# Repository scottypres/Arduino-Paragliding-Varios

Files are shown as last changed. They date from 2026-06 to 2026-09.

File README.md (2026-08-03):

# Arduino Paragliding Varios

GitHub: [`scottypres/Arduino-Paragliding-Varios`](https://github.com/scottypres/Arduino-Paragliding-Varios)
Local checkout: `~/Documents/GitHub/Vario_Adafruit_Featherwing` — the folder name predates the
rename and is *not* worth changing; git doesn't care what the working directory is called.

Two separate paragliding variometers live here. They share nothing but ideas — different
boards, different sketches, different PCBs. Each one keeps its firmware, KiCad projects and
notes inside its own top-level folder.

| | **SparkFun ESP32 WROOM Vario** | **Adafruit Feather Mini Vario** |
|---|---|---|
| Status | **Active.** All current work. | Older / on ice. |
| Board | SparkFun Thing Plus ESP32 WROOM-C | Adafruit ESP32 Feather V2 |
| Firmware | `Sparkfun ESP32 WROOM Vario/Arduino Scripts/Sparkfun_Vario/` (multi-file) | `Adafruit Feather Mini Vario/Arduino Scripts/oled_ssid_button_buzzer/` (single `.ino`) |
| FQBN | `esp32:esp32:esp32thing_plus_c` | `esp32:esp32:adafruit_feather_esp32_v2` |
| Battery sense | MAX17048 fuel gauge on I2C (21/22) | ADC on `BATT_MONITOR` |
| Last touched | ongoing | 2026-07-03 (`bdf2adf`) |

Sensors on both: BMP581 (pressure/altitude), SHT41 (temp/humidity), SH1106G OLED, piezo buzzers.
The SparkFun build adds GPS, an LSM6DSV16X IMU, SD logging and a web app.

---

## Where things are

```
Adafruit Feather Mini Vario/
  Arduino Scripts/oled_ssid_button_buzzer/   single-file firmware
  KiCAD Files/                               Buzzer PCB, Buzzer PCB with step up converter
  CAD Files/                                 3D models for the stack
  docs/

Sparkfun ESP32 WROOM Vario/
  Arduino Scripts/
    Sparkfun_Vario/          <-- THE firmware. Everything else is a side experiment.
    Sparkfun_Battery_Tester/ standalone battery-drain rig
    experiments/             a2dp beep latency, piezo tests, wifi manager/OTA spike
    iram_tests/              IRAM budget probes (why WiFi and BT can't ship together)
  KiCAD Files/               Buzzer PCB V2, Buzzer PCB V3 (rerouting traces)
  3D Printed Case/
  docs/                      SparkFun datasheets, SD-log backups, design specs
```

`Component References/` is duplicated under each variant's `KiCAD Files/` on purpose: KiCad
resolves 3D models via `${KIPRJMOD}/../Component References/...`, so each project needs its own
copy to open cleanly from its own folder.

**Not in git, safe to delete:** anything under a `.history/` folder (VS Code Local History),
`build/`, `build-wifi/`, `build-bt/`, `.pio/`. If you see a top-level `Arduino Scripts/` or
`KiCAD Files/` in your working copy, those are leftovers from before the per-board
restructure — they contain no source, only build and history junk.

---

## The two firmware builds (SparkFun)

Since v1.2.0 the WiFi build also carries **BLE vario telemetry** (NimBLE — small enough
to coexist with WiFi in IRAM; the old split existed because Bluedroid *Classic* wasn't).
The BT-only build remains as a no-WiFi variant. Selected in `radio_config.h`:

| Build | Radios | Gets you | Loses |
|---|---|---|---|
| **WiFi** (default) | WiFi + BLE | web app, OTA, WiFi portal, LK8EX1 telemetry to phone apps | — |
| **BT** | BLE only | LK8EX1 telemetry, lower power | web app, OTA |

IRAM is within ~2 KB of full on the combined build — `rgbLedWrite` is stubbed in
`power.cpp` to keep the RMT driver out; don't add libraries without watching the link.

```sh
cd "Sparkfun ESP32 WROOM Vario/Arduino Scripts/Sparkfun_Vario"

# WiFi image (default)
arduino-cli compile --fqbn esp32:esp32:esp32thing_plus_c --output-dir build-wifi .

# BT image
arduino-cli compile --fqbn esp32:esp32:esp32thing_plus_c --output-dir build-bt \
  --build-property compiler.cpp.extra_flags=-DVARIO_RADIO_BT .
```

Required libraries: `SparkFun MAX1704x Fuel Gauge Arduino Library`, `SparkFun 6DoF LSM6DSV16X`,
plus the usual Adafruit GFX/SH110X/SHT4x/BMP5xx, TinyGPSPlus, ESPAsyncWebServer, WiFiManager.

### Getting a build onto the device

1. **OTA** (WiFi image running): System tab → *Firmware update*, or
   `espota.py -i <ip> -p 3232 -a password -f build-wifi/Sparkfun_Vario.ino.bin`
   (hostname `sparkfun-vario`).
2. **SD self-flash** — the only way to reach the BT image. Copy both binaries to the SD card
   root as `/fw_wifi.bin` and `/fw_bt.bin`, then Menu → System → **Switch FW** flashes *the
   other* variant and reboots.
3. **USB** — `arduino-cli upload -p /dev/cu.usbserial-* --fqbn esp32:esp32:esp32thing_plus_c`.

---

## Firmware versions

`Sparkfun_Vario/version.h` holds a single `VARIO_FW_VERSION`. It is shown in three places:

- OLED: **Menu → System → About**
- Web app: the header (`SparkFun Vario v1.0.0-WiFi`) and System tab → *About*
- API: `GET /api/settings` → `fw_version`, `fw_radio`, `fw_build`

The radio suffix (`-WiFi` / `-BT`) is derived at compile time, so the version string always
says which of the two images is running. `fw_build` is `__DATE__ __TIME__`, which answers
"is the board running the build I just made?" without any build-time codegen.

**Bump `VARIO_FW_VERSION` and add a `CHANGELOG.md` line in the same commit that changes
behaviour.** Semver-ish: patch for fixes, minor for new menu items/features, major for
anything that breaks saved settings or the log format.

To check what a device is running:

```sh
curl -s http://172.20.10.2/api/settings | python3 -m json.tool | grep fw_
```

---

## Working on this repo

Development also happens in Claude Code **cloud** sessions that push straight to
`origin/main` (branch names like `worktree-bridge-cse_*`). **Always `git fetch` before you
start** — a local checkout has silently been 21 commits stale before, and flashing a stale
build erases features that only exist on the device.

Device is usually at `http://172.20.10.2/` on the iPhone-hotspot subnet (`172.20.10.x`).
It sleeps aggressively, so a failed curl means "asleep", not "broken".

`arduino_secrets.h` is gitignored; copy `arduino_secrets.example.h` if you need hardcoded
WiFi credentials. Normally the WiFi portal handles it instead.

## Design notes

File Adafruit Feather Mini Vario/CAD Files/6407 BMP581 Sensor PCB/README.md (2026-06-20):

## Adafruit BMP5xx I2C or SPI Temperature and Pressure Sensors - STEMMA QT PCB

<a href="http://www.adafruit.com/products/6413"><br/>
Click here to purchase one from the Adafruit shop</a>
<a href="http://www.adafruit.com/products/6413"><br/>
Click here to purchase one from the Adafruit shop</a>
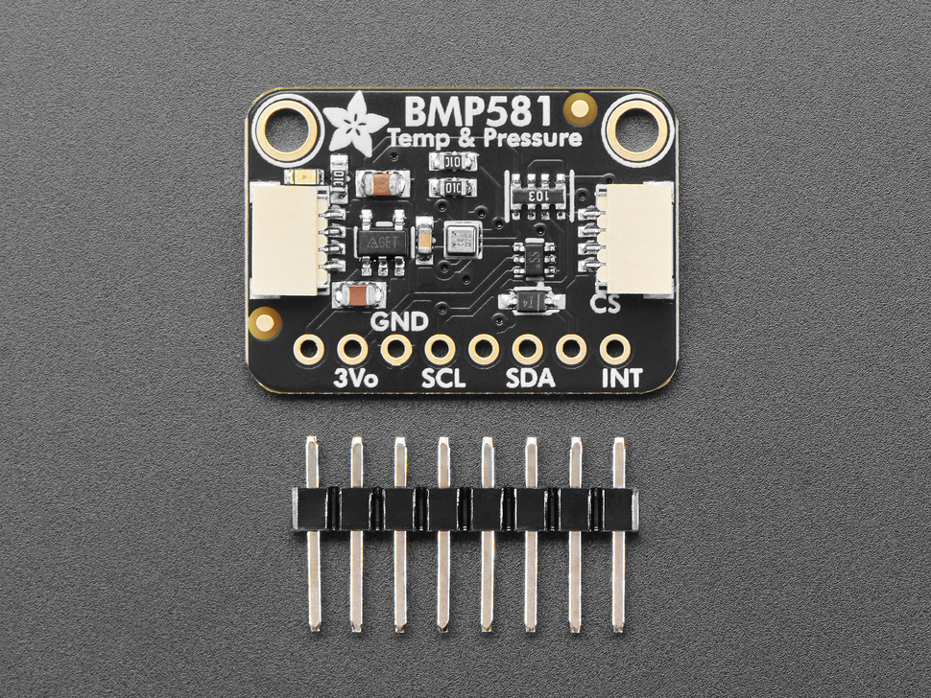
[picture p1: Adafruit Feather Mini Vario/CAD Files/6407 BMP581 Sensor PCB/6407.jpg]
<a href="http://www.adafruit.com/products/6413"><br/>
Click here to purchase one from the Adafruit shop</a>

PCB files for the Adafruit BMP5xx I2C or SPI Temperature and Pressure Sensors - STEMMA QT. 

Format is EagleCAD schematic and board layout
* https://www.adafruit.com/product/6413
* https://www.adafruit.com/product/6411
* https://www.adafruit.com/product/6407

### Description

Bosch has been a leader in barometric pressure sensors, from the BMP085. BMP180, BMP280, BMP388, BMP390... now we've got the next generation, the Adafruit BMP585 Precision Barometric Pressure and Altimeter Breakout. As you would expect, this sensor is similar to its earlier versions but even better. The BMP585 has better precision than ever, which makes it excellent for environmental sensing or as a precision altimeter. It can even be used in either I2C and SPI configurations.

The BMP5xx is the next-generation of sensors from Bosch and is the upgrade to the BMP2xx and BMP3xx - with a low-altitude noise as low as 1cm (0.08Pa) and the same fast conversion time. And like the previous BMP280, you can use I2C or SPI. For simple easy wiring, go with I2C. If you want to connect a bunch of sensors without worrying about I2C address collisions, go with SPI.

The BMP585 and BMP580 has a relative accuracy of ±6 Pascals at room temperature, which translates to about ±50 centimeters of altitude (compare to the BMP280's ±12 Pascal/±1 meter and BMP388's ±8 Pascal/±0.5 meter). The typical absolute accuracy is ±60 Pa or about 5 meters. Check the datasheet for how temperature and altitude can affect the absolute/relative accuracy.

The BMP581 has an astonishing relative accuracy of ±0.4 Pascals at 900-1100 hPa and 25°C, which translates to about ±3.3 centimeters of altitude (compare to the BMP280's ±12 Pascal/±1 meter and BMP388's ±8 Pascal/±0.5 meter). The typical absolute accuracy is ±30Pa or about 2.5 meters. Check the datasheet for how temperature and altitude can affect the absolute/relative accuracy.

The datasheet sort of implies they intend this sensor to be used for drones and quadcopters, to keep altitude stable, but you could also use this for wearables or any project that wants to track height-above-sea-level. Note that for absolute height you'll still need to enter in the barometric pressure at sea level if the weather changes, but that's true of every altimeter sensor that uses pressure. You can also measure temperature with ±0.5°C accuracy.

Nice sensor right? So we made it easy for you to get right into your next project. The surface-mount sensor is soldered onto a custom made PCB in the STEMMA QT form factor, making them easy to interface with. The STEMMA QT connectors on either side are compatible with the SparkFun Qwiic I2C connectors. This allows you to make solderless connections between your development board and the BMP58x or to chain it with a wide range of other sensors and accessories using a compatible cable. QT Cable is not included, but we have a variety in the shop

### License

Adafruit invests time and resources providing this open source design, please support Adafruit and open-source hardware by purchasing products from [Adafruit](https://www.adafruit.com)!

Designed by Limor Fried/Ladyada for Adafruit Industries.

Creative Commons Attribution/Share-Alike, all text above must be included in any redistribution. 
See license.txt for additional details.

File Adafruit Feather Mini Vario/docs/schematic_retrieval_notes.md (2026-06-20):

# Schematic Retrieval Notes

Updated: 2026-06-20

## Files Retrieved

- Adafruit ESP32 Feather V2, product 5400:
  - Retrieved official EagleCAD schematic and board files.
  - Folder: `5400 ESP32 Feather V2 EagleCAD`
  - Source: https://github.com/adafruit/Adafruit-ESP32-Feather-V2-PCB
  - Native KiCad source not found.

- Adafruit 128x64 OLED FeatherWing, product 6313 / 4650 family:
  - Retrieved official EagleCAD schematic and board files for the 128x64 OLED FeatherWing.
  - Folder: `6313 OLED FeatherWing EagleCAD`
  - Source: https://github.com/adafruit/Adafruit-OLED-FeatherWing-PCB
  - Native KiCad source not found.

- Adafruit BMP581 Temperature and Pressure Sensor, product 6407:
  - Retrieved official EagleCAD schematic and board files.
  - Folder: `6407 BMP581 Sensor EagleCAD`
  - Source: https://github.com/adafruit/Adafruit-BMP5xx-Temperature-and-Pressure-Sensor-PCB
  - Native KiCad source not found.

- Adafruit SHT41 Temperature and Humidity Sensor, product 5776:
  - Retrieved official EagleCAD schematic and board files.
  - Folder: `5776 SHT41 Sensor EagleCAD`
  - Source: https://github.com/adafruit/Adafruit-SHT40-PCB
  - Native KiCad source not found.

- Custom Buzzer PCB:
  - Existing native KiCad project already present.
  - Folder: `Buzzer PCB`

## No Downloadable Schematic Source Found

- 400 mAh LiPo battery:
  - Battery only; no schematic source needed. Use connector symbols and physical battery envelope.

- 12085 passive buzzer / Adafruit product 160 PS1240-style piezo buzzer:
  - No downloadable schematic source found. Use a generic KiCad buzzer/speaker symbol and a footprint based on measured/datasheet pin spacing.

- Comidox 0.9-5V to 5V boost converter module:
  - No exact schematic source found for the purchased module. Treat as a 3-pin module: `VIN`, `GND`, `VOUT`, with a custom footprint based on measured board and pin spacing.

- ALLECIN S8050 transistor:
  - No external schematic source needed. Use KiCad built-in BJT symbol and match the footprint to the actual package/pinout.

- JST-PH 2.0 battery connectors:
  - No external schematic source needed. Use generic 2-pin connector symbols and KiCad JST-PH footprints.

- SS12D00G5 slide switch:
  - No exact importable schematic source found. Use a KiCad SPDT switch symbol and verify/create the footprint from the measured switch pinout.

- 1N5819 Schottky diode:
  - No external schematic source needed. Use KiCad built-in diode symbol and match the footprint to the physical package.

- Resistors, capacitors, single-pin header:
  - No external schematic source needed. Use KiCad built-in symbols and footprints.

- STEMMA QT / Qwiic JST-SH cables:
  - Cable assemblies only; no schematic source needed. Use generic 4-pin connector symbols and KiCad JST-SH footprints for board-side connectors.

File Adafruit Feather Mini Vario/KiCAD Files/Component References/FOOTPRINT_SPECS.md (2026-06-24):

# Footprint build specs — from DXF + PDF (Buzzer PCB V2)

Source: `Component References/*.pdf` (dims, pin names) + `*Sheet1.dxf` (geometry).
All headers are **2.54 mm pitch, single row, THT**. Pin 1 = square pad.
Exact pad centers to be verified visually against the drawing in KiCad at build time
(DXFs are drawn at a per-file scale + include both front/back views — counts below are de-duplicated).

## Sides (per user; do NOT flip others)
- SD card reader → **BACK (B.Cu)**
- JST plug → **BACK** (existing part)
- Buzzer → **FRONT (F.Cu)** (existing part)
- OLED / Comidox booster / TP4057 charger → **keep current side** (unspecified)

## 1. M16968 OLED + Rotary Knob — `M16968 OLED and Rotary Knob.step`
- Board outline: **59.3 × 35.3 mm**
- Mounting: **4 × Ø3.25** holes (corners), vertical span 29.5
- Header: **9 pins**, header offset 11.5 from datum, 2 from top edge
- Pin order (BACK view, L→R): `3v3, GND, BACK, ENCODER_B, ENCODER_A, ENCODER_PUSH, OLED_SCL, OLED_SDA, CONFIRM`
- Note: front/back pin order mirrors — confirm orientation when placing.

## 2. WWZMDiB SD TF Card Adaptor — `WWZMDiB SD TF Card Adaptor - SPI - Arduino.step`  → BACK
- Board outline: **17.9 × 17.75 mm**, thickness 1.6
- Card window: 13.8 wide
- Mounting: **2 × Ø2.5**, 14.5 apart (horizontal), near bottom
- Header: **6 pins** along bottom edge, row-to-mount offset 4.5
- Pin order (front view, L→R): `3v3, CS, MOSI, CLK, MISO, GND`

## 3. Comidox 5V Booster — `Comidox 5V Booster Board.step`
- Board outline: **10.75 × 10.75 mm**
- Pot/trimmer circle: Ø5.25
- Header: **3 pins** (Ø1 holes): `Vin, GND, Vout` (L→R), offsets 8.12 / 2.84
- Pad pitch 2.54.

## 4. HiLetGo TP4057 LiPo/LiIon Charger — `HiLetGo TP4057 LiPo_LiIon Charger.step`
- Board envelope: **12.2 × 18.5 mm** including the USB-C protrusion.
- Main pad columns span **10.45 mm**; pad rows span **9.0 mm**. Holes are **6 × Ø0.8**.
- Pads at USB end: `In-`, `In+`.
- Pads at opposite end: `Out-`, `Batt-`, `Batt+`, `Out+`.

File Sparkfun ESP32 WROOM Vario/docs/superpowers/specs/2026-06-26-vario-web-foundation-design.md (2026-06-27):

# SparkFun Vario — Web Foundation (Sub-project #0) Design

Date: 2026-06-26
Status: IN PROGRESS — phases 1–2 complete & verified green (see Implementation progress)
Sketch: `Arduino Scripts/Sparkfun_Vario/Sparkfun_Vario.ino` (currently ~2030 lines, single file)
Board: SparkFun Thing Plus ESP32 WROOM-C, Arduino-ESP32 **core 3.x** (pin-based `ledcAttach`/`ledcWriteTone` confirm this)

## Roadmap context

The full wishlist is ~7 subsystems built on the existing working sketch. Each gets its own
spec → plan → build cycle. Recommended order:

| # | Sub-project | Depends on |
|---|---|---|
| **0** | **Web foundation (THIS doc)** — async migration, SD-served SPA, unified settings, WS, OTA, confirms, file split | — |
| 1 | Time & date — RTC on battery, NTP on cold boot, GPS-time vs manual-location, timestamp every log row | 0 |
| 2 | OLED window system (device) — up to 3 windows, encoder switch, select/back enters menu | 1 |
| 3 | OLED designer (browser) — simulated 128×64, drag placeholders, per-field config, WYSIWYG, save/upload | 0,2 |
| 4 | Live map — Leaflet + OSM tiles, current position, updates as you move | 0,1 |
| 5 | Power + logger extras — deep sleep, takeoff auto-start, flight summary, IGC export | 1 |
| 6 | Jingles + vario tone polish — 3-buzzer chords/melodies, tune climb/sink feel | — |

This document covers **#0 only**. #0 is deliberately "new plumbing, same on-device behavior"
so it yields a clean *nothing-regressed* checkpoint before later phases change how the device acts.

## Hardware/firmware reality (baseline)

- **3 passive piezo buzzers** on pins 13/26/27, LEDC-driven via per-buzzer bitmask (`setToneMask`). Chords already possible. Volume currently faked as #-of-buzzers-on.
- Sensors: BMP581 (`Adafruit_BMP5xx`), SHT4x, TinyGPSPlus GPS, SH1106 128×64 OLED, NeoPixel.
- Vario tone algorithm already exists and is decent (`updateVarioAudio`).
- Current web: **synchronous `WebServer.h`**, whole UI as inline `F()` strings in `handleRoot`, `ArduinoOTA` (IDE-only), WiFiManager portal, **no LittleFS**. SD card mounted with CSV logger. `data.json` polled at 1 Hz. SD clear/format have **no confirmation** and `format` calls `deleteRecursive("/")`.
- No real-time clock; every log row is `millis()`.

## Decisions (locked via grilling)

1. **Async library**: ESP32Async/ESPAsyncWebServer (mathieucarbou fork) — required for core 3.x. The old me-no-dev fork won't compile.
2. **Bootstrap & failure model**: minimal page baked into flash (PROGMEM) is *always* served and can do the essentials — show live data, set WiFi, **upload the SPA bundle to SD**. The rich SPA (designer, map, etc.) is served from SD `/www` when present; if SD or `/www/index.html` is missing, fall back to the flash page (with an "upload web UI" button) instead of a dead server. Leaflet + map tiles load from **CDN** (online), so SD holds only our handful of files — no on-device unzip.
3. **Settings model**: one unified in-memory settings struct is the single source of truth. `GET /api/settings` returns all; `POST /api/settings` patches. The on-device menu and the browser both read/write this same model (no drift). Concrete `buildSettingsJson()` + `applySettingsJson()` over known fields — **not** a reflective registry framework. Scalars persist to **NVS** (Preferences); window-config files (later phases) persist as JSON on SD. Model is extensible: later additions (time mode, deep-sleep timeout, window-config pointers) are just new fields.
4. **Live telemetry**: one `AsyncWebSocket` (`/ws`) broadcasting a shared JSON telemetry frame at ~5 Hz, fed from the existing sensor cadence (non-blocking, won't disturb buzzer beep timing). `GET /api/state` one-shot retained for initial load and debugging.
5. **OTA**: add **ElegantOTA** (async mode) → browser `/update` page with drag-drop + progress bar. **Keep ArduinoOTA** for fast IDE reflashing during dev. If flash gets tight later, ArduinoOTA is the one to drop.
6. **Destructive actions**: reusable browser confirmation modal on every destructive action; **typed-word confirm** for full SD wipe and factory reset. Default "clear" wipes logs/flight data but **preserves `/www` and `/config`** so you can't brick your own UI. A separate, explicitly-labeled "Full wipe SD (erases web UI)" exists with the loud typed warning. No server-side CSRF token machinery (overkill for a personal LAN device).
7. **Code organization**: split the single `.ino` into subsystem `.h`/`.cpp` pairs, staying **procedural with shared globals** (match current style; no OOP rewrite). Portable across Arduino IDE and arduino-cli/PlatformIO. The split is done **first** and verified to compile with behavior unchanged before any feature is added.
8. **Scope line**: #0 is plumbing only. On-device OLED/menu behavior is **unchanged**. #0 mirrors the *current* settings (data logging, set/clear zero, audio, volume, response, tone test, log rate, GPS display, forget WiFi, pixel) into the polished browser UI. The 3-window OLED redesign and the select/back menu flow are deferred entirely to #2.

## Architecture

### File layout (after refactor)

```
Sparkfun_Vario.ino     // setup() / loop() wiring only
globals.h              // pins, shared state, structs, enums, extern decls
settings.h/.cpp        // unified model, buildSettingsJson/applySettingsJson, NVS load/save
web.h/.cpp             // AsyncWebServer, routes, AsyncWebSocket, ElegantOTA wiring, flash fallback page
audio.h/.cpp           // buzzers, vario tones (jingles land here in #6)
display.h/.cpp         // OLED render (window system lands here in #2)
sensors.h/.cpp         // BMP581 + SHT4x
gps.h/.cpp             // TinyGPS glue
logging.h/.cpp         // SD CSV logger
power.h/.cpp           // battery (deep sleep lands here in #5)
wifi_net.h/.cpp        // WiFiManager portal + multi-network store
```

(Procedural; `.cpp` files share state through `globals.h` externs, as today.)

### Web/asset serving

- AsyncWebServer on port 80.
- `GET /` → if `/www/index.html` exists on SD, serve it (and `/www/*` static assets); else serve the PROGMEM flash fallback page.
- Static handler for `/www/*` from SD.
- Upload endpoint (`POST /api/upload?path=/www/...`) writes uploaded files to SD; used by both the flash fallback page and the SPA to update the UI without reflashing.

### API surface (#0)

- `GET /api/state` — one-shot telemetry + status JSON (supersedes `data.json`).
- `WS /ws` — pushes the same telemetry frame ~5 Hz.
- `GET /api/settings` / `POST /api/settings` — unified settings.
- `POST /api/upload` — write file to SD (SPA bundle, configs).
- Logs: `GET /api/log` (view), `GET /api/log/download`, `GET /api/log/tail` (port existing).
- WiFi: `GET`/`POST /api/wifi` (list/add/forget/forget-all — port existing).
- Destructive: `POST /api/sd/clear` (preserves /www,/config), `POST /api/sd/wipe` (typed confirm), `POST /api/reset` (typed confirm).
- `/update` — ElegantOTA.
- JSON via **ArduinoJson**.

### Data flow

`loop()` reads sensors → updates shared globals → at the sensor cadence, `web` serializes a
telemetry frame and broadcasts on `/ws`. Browser renders from WS; falls back to `GET /api/state`
if WS drops, with auto-reconnect. Settings edits POST to `/api/settings`, which calls
`applySettingsJson()` (updates globals + NVS); changes made on the device menu are reflected to
browsers via the next telemetry/settings push.

## Error handling

- SD missing/assets missing → flash fallback page, never a dead server.
- WS drop → browser auto-reconnects; `GET /api/state` covers the gap.
- Upload failure (SD full / write error) → HTTP 500 + message surfaced in UI.
- Destructive ops require confirm; full-wipe/reset require typed word; "clear" never touches `/www`,`/config`.
- Settings POST validates/clamps fields (reuse existing `constrain` bounds); bad field ignored, not fatal.

## Testing / verification

- **Toolchain**: arduino-cli 1.5.0, esp32 core 3.3.10, FQBN `esp32:esp32:esp32thing_plus_c`. I can run `arduino-cli compile` here to verify each phase.
- **Green baseline (current sketch, 2026-06-26)**: compiles clean — 1,238,053 bytes = **18% of 6.25 MB** app partition; globals 56,576 bytes = **17% of 320 KB** RAM. Flash budget is comfortable; ArduinoOTA need NOT be dropped.
- **Libs to install**: `ESP Async WebServer` (ESP32Async fork) + `AsyncTCP` (ESP32Async) + `ElegantOTA`; build flag `-DELEGANTOTA_USE_ASYNC_WEBSERVER=1`.
- **Refactor gate**: after the file split (no behavior change), `arduino-cli compile` must stay green before adding features.
- **Pure-logic unit test (host-compilable)**: `buildSettingsJson()` → `applySettingsJson()`
  round-trip preserves every field; out-of-range inputs clamp. Single assert-based check, no framework.
- **On-device smoke**: serve fallback page with SD removed; upload SPA to SD and confirm rich UI loads; WS live values update; ElegantOTA upload succeeds; confirm modals gate destructive ops; "clear" leaves `/www` intact.

## Out of scope for #0

OLED window system & menu-flow redesign (#2), designer (#3), time/date (#1), map (#4),
deep sleep & logger extras (#5), jingles & tone tuning (#6). The settings model is *designed* to
accept their fields without rework, but none are implemented here.

## Implementation progress (updated 2026-06-27)

Build verify: `arduino-cli compile --fqbn esp32:esp32:esp32thing_plus_c .` (run from sketch dir).

- ✅ **Phase 1 — File split.** Single 2030-line `.ino` → `globals.h/.cpp` + 10 subsystem `.h/.cpp` pairs (audio, display, controls, sensors, gps_mod, power, wifi_net, web, logging, settings), main `.ino` = setup()/loop() only. Procedural, shared globals. Verified behavior-preserving: 1,238,393 B (+340 B vs baseline).
- ✅ **Phase 2 — Async migration.** `WebServer.h` → ESP Async WebServer 3.11.1 (+ Async TCP 3.4.10). globals: `AsyncWebServer webServer`. All routes ported to async handlers (`AsyncWebServerRequest*`), POST args via `getParam(name,true)`, file sends via `request->send(SD,path,type)`, download adds Content-Disposition, no-store headers via beginResponse. `serviceWebServer()` no longer polls (event-driven) — now only fires a **deferred board restart** (async handlers can't `ESP.restart()` inline). begin()/end() lifecycle kept mutually exclusive with WiFiManager portal. Gotchas fixed: `AsyncWebServerParameter`→`AsyncWebParameter`; `HTTP_GET/POST` ambiguous (WiFiManager pulls core WebServer.h) → qualified `AsyncWebRequestMethod::HTTP_GET/POST`. Verified green: 1,333,257 B (20%), RAM 17%.
- ✅ **Phase 3 — Browser OTA.** Switched ElegantOTA → core `Update.h` + a custom async upload handler (`/api/ota`) to avoid ElegantOTA's GLOBAL `-DELEGANTOTA_USE_ASYNC_WEBSERVER=1` flag (would break plain `arduino-cli compile`). Same browser-upload feature, no fragile config. ArduinoOTA kept for IDE reflashing.
- ✅ **Phase 4 — WebSocket telemetry.** `AsyncWebSocket("/ws")` broadcasting `dataJson()` at ~5 Hz via `serviceWebPush()` (200 ms throttle + `cleanupClients()`); `GET /api/state` retained for poll fallback. SPA uses WS with poll fallback.
- ✅ **Phase 5 — Unified settings model.** `buildSettingsJson()`/`applySettingsJson()` + `GET`/`POST /api/settings` (AsyncCallbackJsonWebHandler), persisted to NVS. Added `dataLog`/`logRate`/`gpsDisp` keys.
- ✅ **Phase 6 — Bootstrap assets.** Flash PROGMEM `kIndexHtml` fallback + SD `/www` static serving + `/api/upload`. `/sd/clear` preserves `/www`+`/config`; `/sd/wipe` (typed "ERASE" confirm) full wipe.
- ✅ **Phase 7 — Polished SPA.** Dark tabbed SPA (Live/Map/Settings/WiFi/SD/System), toggle switches, confirm modals, Leaflet live map (CDN + SRI), OTA progress bar.
- ✅ **Extras.** Jingle engine (3-buzzer chords, on-demand, never at boot) + `/api/jingle`; deep sleep (`enterDeepSleep()`, wake on encoder button) + `/api/sleep`; live map.
- ✅ **Sub-project #1 — Time & date.** `timekeeping.h/.cpp`: NTP via `configTime()` on WiFi-connect (ESP32 RTC keeps ticking after WiFi drops); GPS-time fallback seeds the clock via `settimeofday()` when NTP hasn't synced; `serviceClock()` in loop. UTC stored (TZ=UTC0; offset knob deferred to manual-location work). CSV gains an `iso_utc` column on every row (migration sentinel bumped to `iso_utc` → old logs auto-rotate). `dataJson` exposes `time_known`/`time_source`/`time_utc`; SPA footer shows live UTC clock. Verified green: 1,421,332 B (21%), RAM 17%.
- ✅ **Sub-project #2 — OLED 3-window system** (device-side). New `inMenuMode`/`activeWindow` state (globals) + `kOledWindowCount=3`. View mode: encoder cycles 3 data windows — **Flight** (big altitude + vario + sat/bat), **GPS** (lat/lng/alt/speed/sat), **Status** (temp/humidity/battery/SD/WiFi + UTC date+time). Select (encoder/confirm) **or** back enters the menu; in menu, encoder scrolls (full-screen 5-row scrolling list with `n/total` indicator), select activates/edits, back exits editing then exits menu→view. `dataJson` exposes `oled_window`/`oled_window_count`/`oled_in_menu`. Old `gpsDisplayEnabled` menu toggle kept (now inert vs windows; #3 will redefine windows). Verified green: 1,423,116 B (21%), RAM 17%.
- ✅ **Sub-project #3 — Browser OLED designer + config-driven rendering.** New `windows.h/.cpp`: `OledField{data,x,y,size,dec,prefix,suffix}` + `OledWindow{fields[8],count}` × `kOledWindowCount`. Device renders each window straight from its field list (`drawConfiguredWindow` replaced the hard-coded Flight/GPS/Status draws), so the browser preview is 1:1. Config persists to SD `/config/windows.json` (ArduinoJson load/save); baked-in defaults when absent/invalid. Data keys: altitude_ft, raw_altitude_ft, vario_mps, temp_f, humidity_pct, battery_pct, battery_v, sat_used, sat_seen, lat, lng, gps_alt_m, gps_speed_kmph, date, time, plus `text` (static label). Routes: `GET /api/windows`, `POST /api/windows` (AsyncCallbackJsonWebHandler → `applyWindowConfigJson` + SD persist + `updateDisplay(true)`). New SPA **OLED** tab: 128×64 live preview (×3 scale), drag-to-position fields (pointer events, clamped 0-127/0-63), tap-to-edit panel (data dropdown / prefix / suffix / size 1-4 / decimals / X·Y / delete), +Field (max 8), Save-to-device, Download JSON, Upload JSON. Verified green: 1,439,344 B (21%), RAM 18%. Note: preview text width is a monospace approximation of Adafruit_GFX 6×8 metrics — field *positions* map exactly; glyph widths are close, not pixel-perfect.

## Open items

- Manual-location + TZ offset knob (GPS-time vs text/zip geocoding toggle) deferred; clock currently UTC-only.
- None blocking. (Toolchain: arduino-cli. Flash budget: 21% of 6.25 MB — very comfortable.)
- Runtime/on-hardware verification still pending (compile-green only): web UI serves, routes work, portal⇄server handoff, deferred reset/sleep, NTP/GPS clock sync, CSV timestamps.

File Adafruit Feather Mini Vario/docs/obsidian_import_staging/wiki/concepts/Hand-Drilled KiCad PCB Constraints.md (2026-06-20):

---
type: concept
title: "Hand-Drilled KiCad PCB Constraints"
created: 2026-06-20
updated: 2026-06-20
tags:
  - pcb
  - kicad
  - fabrication
status: developing
related:
  - "[[Feather Vario Buzzer PCB]]"
  - "[[KiCad Single-Sided PCB Milling Workflow]]"
sources:
  - "[[vario-adafruit-featherwing-repo-2026-06-20]]"
---

# Hand-Drilled KiCad PCB Constraints

For a hand-drilled PCB, footprints should use drill sizes that match the available bit set instead of library-default or mathematically convenient holes.

## Drill Strategy

The active drill list for the Feather vario buzzer board is:

`0.8`, `1.0`, `1.2`, `1.4`, `1.6`, `1.8`, `2.0`, `2.2`, `2.4`, `3.0`, `3.125`, `3.2 mm`.

The current board export uses only:

`0.8`, `1.0`, `1.2`, `3.0 mm`.

This keeps fabrication simple and avoids odd drill sizes such as `2.6 mm` that cannot be made directly with the available bits.

## Trace Strategy

For a low-power buzzer board, `1 mm` traces are acceptable everywhere. Wider traces can still be used for extra margin and easier milling:

- `3 mm`: battery, boost, buzzer, and main ground paths if there is space.
- `2 mm`: shorter current branches where space is tight.
- `1 mm`: signal traces such as D13 to the transistor base.

The important routing property is directness and short return paths, not maximum width.

## Footprint Strategy

Use footprints that match fabrication and assembly realities:

- TO-92 transistor footprints can be widened to `2.54 mm` pitch for hand drilling, but this requires bending the outside leads outward.
- Mounting holes should be converted to allowed drill sizes, such as `3.0 mm` NPTH instead of non-listed clearances.
- Module footprints should encode real mechanical constraints, including board size and hole-to-edge distances.

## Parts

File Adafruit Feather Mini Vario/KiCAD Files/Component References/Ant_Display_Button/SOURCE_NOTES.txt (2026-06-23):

Ant Display tactile button footprint source

Local source project:
C:\Users\Scott\Documents\GitHub\antPID\Ant_Display\kicad\Ant_Display\Ant_Display.kicad_pcb

Copied footprint:
Button_Switch_THT:SW_PUSH_6mm_H5mm

Copied button nets:
SW1 BACK  -> BTN_BACK_GPIO3 / GND
SW2 NEXT  -> BTN_NEXT_GPIO4 / GND
SW3 DOWN  -> BTN_DOWN_GPIO5 / GND
SW4 UP    -> BTN_UP_GPIO21 / GND

Copied pad geometry:
Four through-hole pads, duplicate pad numbers 1/1 and 2/2.
Pad coordinates are (0,0), (6.5,0), (0,4.5), and (6.5,4.5).
Pad size is 3.0 mm, drill is 1.2 mm, on both copper and mask layers.

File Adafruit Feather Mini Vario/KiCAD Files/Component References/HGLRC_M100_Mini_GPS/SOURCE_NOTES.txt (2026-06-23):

HGLRC M100_MINI GPS reference sources

Official product page:
https://www.hglrc.com/products/hglrc-m100_mini-gps
- Size: 15 x 15 x 5.2 mm
- Input: 3.3V-5V per product page
- M10 chip, 72 channels, 115200 bps, 10Hz, UBLOX-compatible protocol

Manual PDF saved in this folder:
M100minigpsManual.pdf
- Wiring/pad order shown as RX TX 5V GND on the manual graphic
- English parameter table lists power supply as 5V, size 15 x 15 x 5.2 mm, output protocol UBLOX, 115200 bps, 10Hz

STEP model search result:
https://grabcad.com/library/hglrc-m100-mini-gps-1
- Search result identifies HGLRC M100_MINI.step, but GrabCAD download requires an interactive account/session from the saved page.

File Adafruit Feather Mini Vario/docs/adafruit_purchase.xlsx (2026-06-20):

products_history
order | product id | product name | quantity | price | subtotal | CAD Downloaded
3697907 | 160 | Piezo Buzzer | 2 | 1.5 | 3 | External model found, login required; not copied
3697907 | 261 | JST PH 2 Pin Cable Female Connector 100mm | 1 | 0.75 | 0.75 | STEP cable assembly added: 261 JST PH 2-pin Cable
3697907 | 2940 | Short Headers Kit for Feather 12 pin 16 pin Female Headers | 1 | 1.5 | 1.5 | Reference CAD copied: 2940 Short Feather Headers - Generic PinSocket Reference
3697907 | 3299 | Black Nylon Machine Screw and Stand off Set – M2.5 Thread | 1 | 16.95 | 16.95 | STEP standoff variants added: 3299 M2.5 Standoff Reference
3697907 | 3366 | 36 pin Stacking header pack of 5! | 1 | 5.95 | 5.95 | Parametric source copied: 3366 36-pin Stacking Header - Parametric Source
3697907 | 3700 | Maker Friendly Zipper Case Red | 1 | 2.5 | 2.5 | No downloadable external CAD found
3697907 | 3898 | Lithium Ion Polymer Battery Ideal For Feathers 3.7V 400mAh | 2 | 6.95 | 13.9 | Copied: 3898 400mah Battery
3697907 | 4210 | STEMMA QT / Qwiic JST SH 4 pin Cable 100mm Long | 1 | 0.95 | 0.95 | STEP cable assembly added: 4210_4399 STEMMA QT Qwiic JST SH Cables
3697907 | 4397 | STEMMA QT / Qwiic JST SH 4 pin Cable with Premium Female Sockets | 1 | 0.95 | 0.95 | STEP cable assembly added: 4397 STEMMA QT to Female Sockets Cable
3697907 | 4399 | STEMMA QT / Qwiic JST SH 4 Pin Cable 50mm Long | 2 | 0.95 | 1.9 | STEP cable assembly added: 4210_4399 STEMMA QT Qwiic JST SH Cables
3697907 | 5019 | Thick Double Sided Rectangle Foam Tape 2 pieces | 2 | 0.75 | 1.5 | No downloadable external CAD found
3697907 | 5400 | Adafruit ESP32 Feather V2 8MB Flash 2 MB PSRAM | 1 | 19.95 | 19.95 | Copied: 5400 ESP32 Feather V2
3697907 | 5719 | PCB Coaster with Gold Adafruit Logo | 1 | 2.5 | 2.5 | No downloadable external CAD found
3697907 | 5776 | Adafruit Sensirion SHT41 Temperature & Humidity Sensor | 1 | 5.95 | 5.95 | STEP added: 5776 SHT41 Sensor - from SHT45 same SHT4x board family.step
3697907 | 6313 | Assembled Adafruit FeatherWing OLED 128x64 OLED Add on | 1 | 15.95 | 15.95 | Copied by name: 4650 OLED FeatherWing
3697907 | 6407 | Adafruit BMP581 I2C or SPI Temperature and Pressure Sensor | 1 | 9.95 | 9.95 | STEP added: 6407 BMP581 Sensor - from BMP585 same BMP5xx board family.step

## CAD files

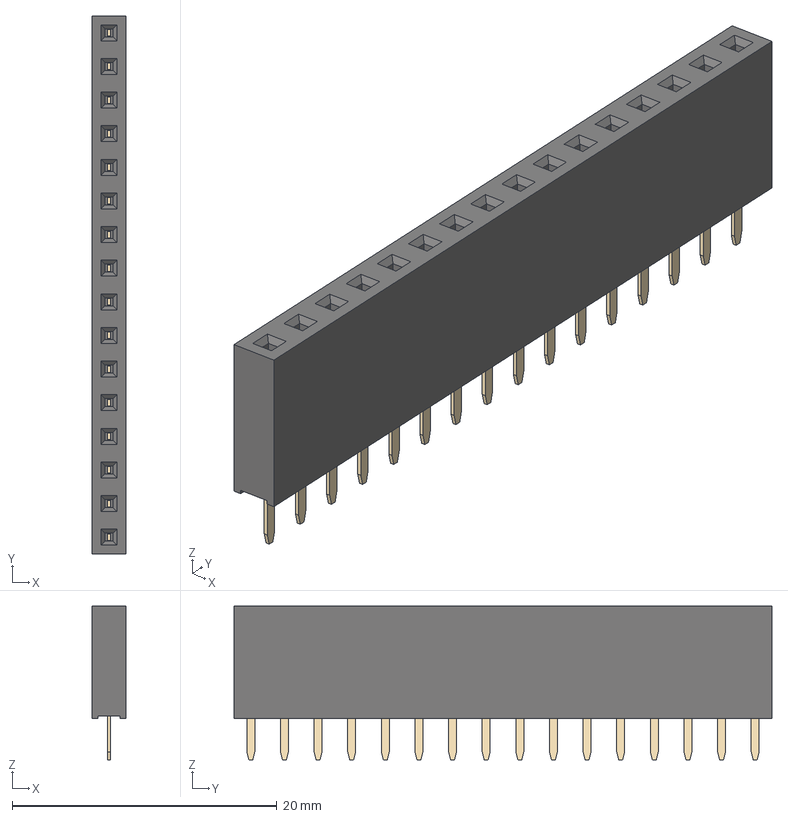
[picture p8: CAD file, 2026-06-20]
Adafruit Feather Mini Vario/CAD Files/2940 Short Feather Headers - Generic PinSocket Reference/PinSocket_1x16_P2.54mm_Vertical.step
2.54 x 40.6 x 11.6 mm

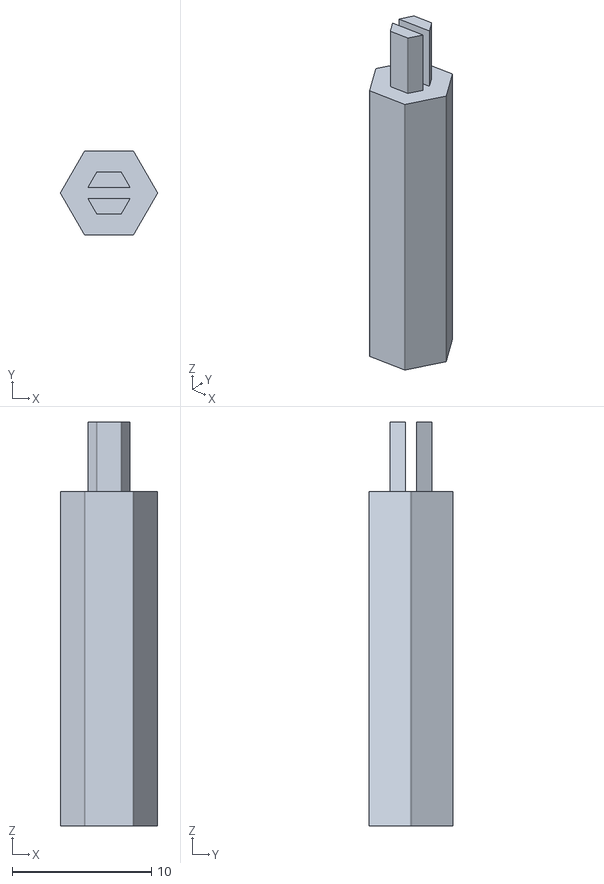
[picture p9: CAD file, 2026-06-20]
Adafruit Feather Mini Vario/CAD Files/3299 M2.5 Standoff Reference/files/hex-standoff_base.stl
6.96 x 6.06 x 29.0

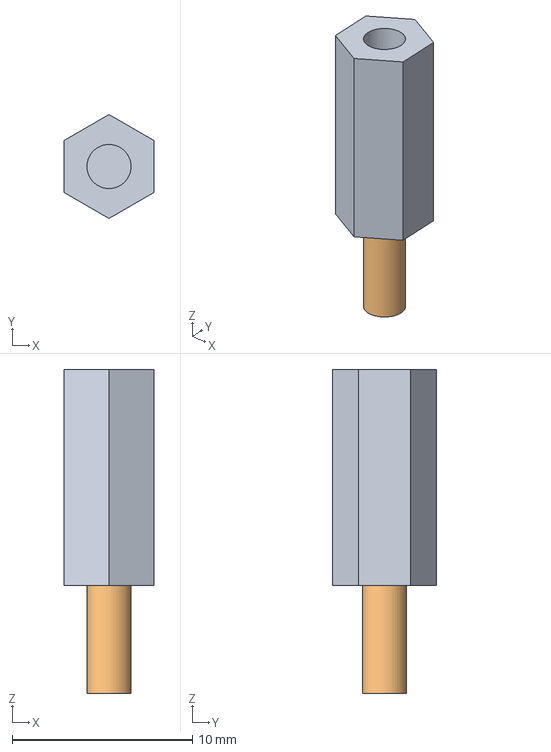
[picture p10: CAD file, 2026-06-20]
Adafruit Feather Mini Vario/CAD Files/3299 M2.5 Standoff Reference/M2.5 male-female hex standoff 12mm body.step
5.00 x 5.77 x 18.0 mm

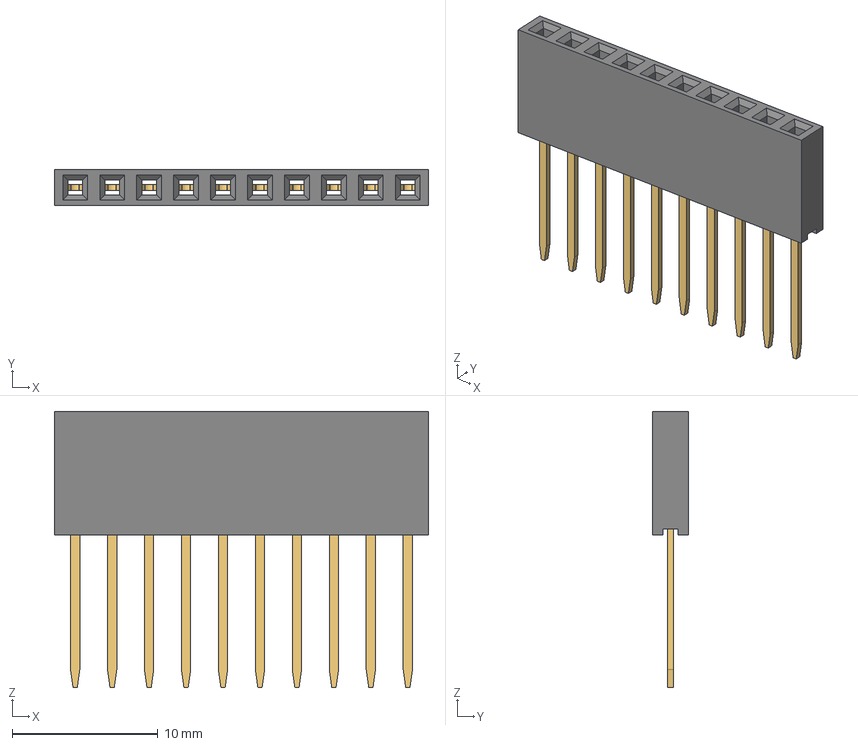
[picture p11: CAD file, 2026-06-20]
Adafruit Feather Mini Vario/CAD Files/3366 36-pin Stacking Header - Parametric Source/Stackable Header 2.54 mm.FCStd
25.7 x 2.50 x 19.0 mm
Pins
Housing

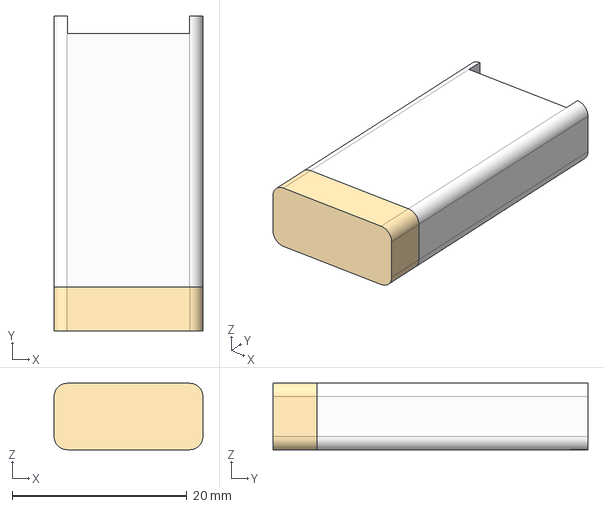
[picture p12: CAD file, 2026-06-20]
Adafruit Feather Mini Vario/CAD Files/3898 400mah Battery/3898 400mAh Battery.step
17.0 x 36.0 x 7.60 mm

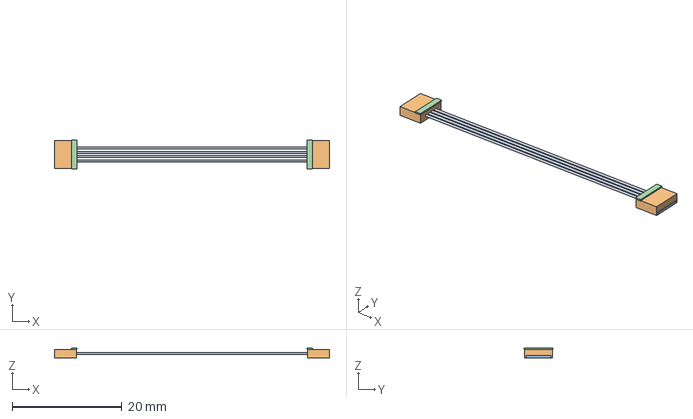
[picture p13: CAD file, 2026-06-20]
Adafruit Feather Mini Vario/CAD Files/4210_4399 STEMMA QT Cable Connector Reference/4399 STEMMA QT Qwiic JST SH 4-pin cable 50mm simplified.step
50.0 x 5.30 x 1.77 mm

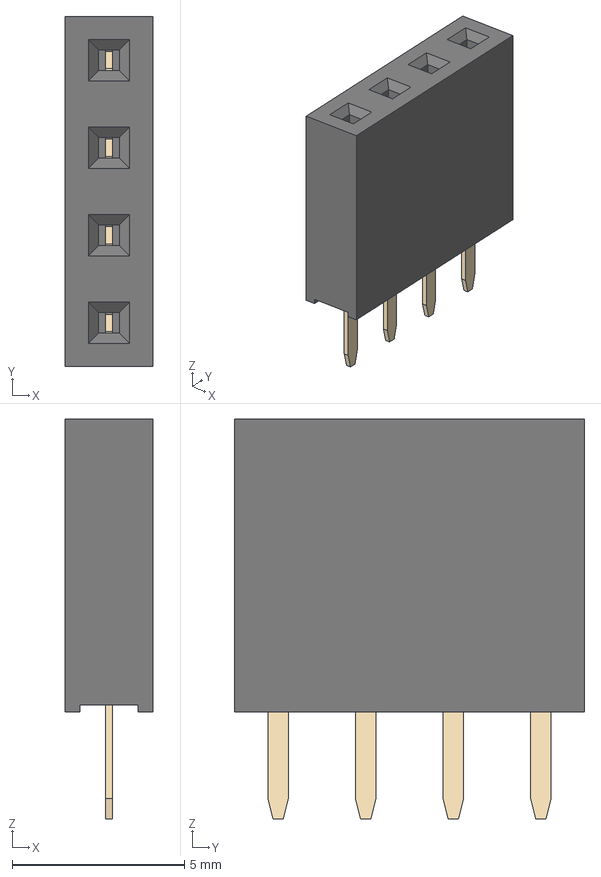
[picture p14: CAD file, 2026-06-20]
Adafruit Feather Mini Vario/CAD Files/4397 STEMMA QT to Female Sockets Reference/PinSocket_1x04_P2.54mm_Vertical.step
2.54 x 10.2 x 11.6 mm

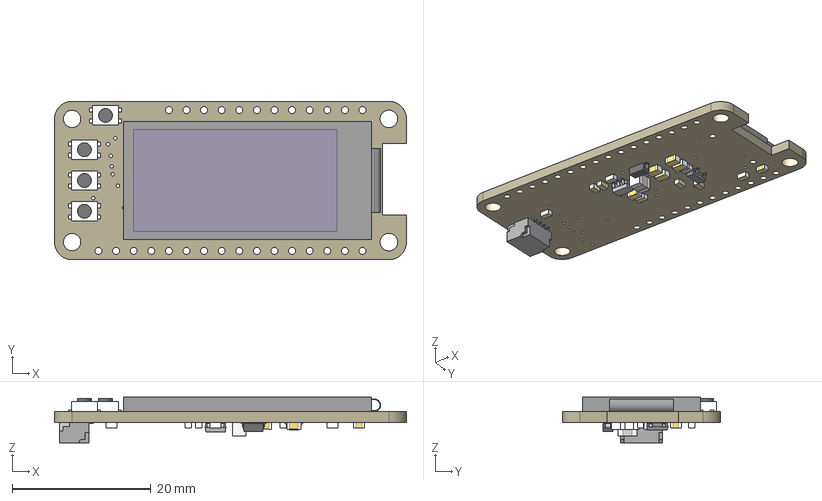
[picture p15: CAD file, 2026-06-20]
Adafruit Feather Mini Vario/CAD Files/4650 OLED FeatherWing/4650 OLED FeatherWing.step
50.8 x 22.9 x 6.59 mm
Board
10uF/16V x 5
0.1uF x 10
KMR2 x 4
APX803
OLED_128X64_SH1107
FAN5331SX
10uH
MBR120
STEMMA_I2C_QT

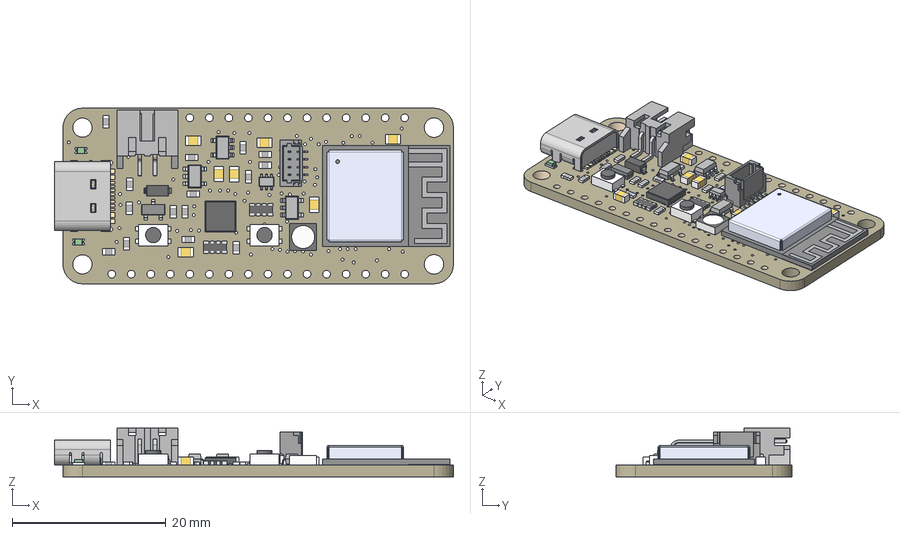
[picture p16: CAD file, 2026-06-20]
Adafruit Feather Mini Vario/CAD Files/5400 ESP32 Feather V2/5400 ESP32 Feather V2.step
51.9 x 22.9 x 6.37 mm
Board
10uF x 7
AP2112-3.3 x 2
MBR540
JSTPH
MCP73831T-2ACI/OT
RED x 2
1uF x 15
KMR2 x 2
DMG3415U
47K x 2
ESP32-PICO-MINI-02MINI
WS2812B3535
STEMMA_I2C_QTRA
TPB1,27 x 2
USB Type C
CP2102N-24
DUAL NPN

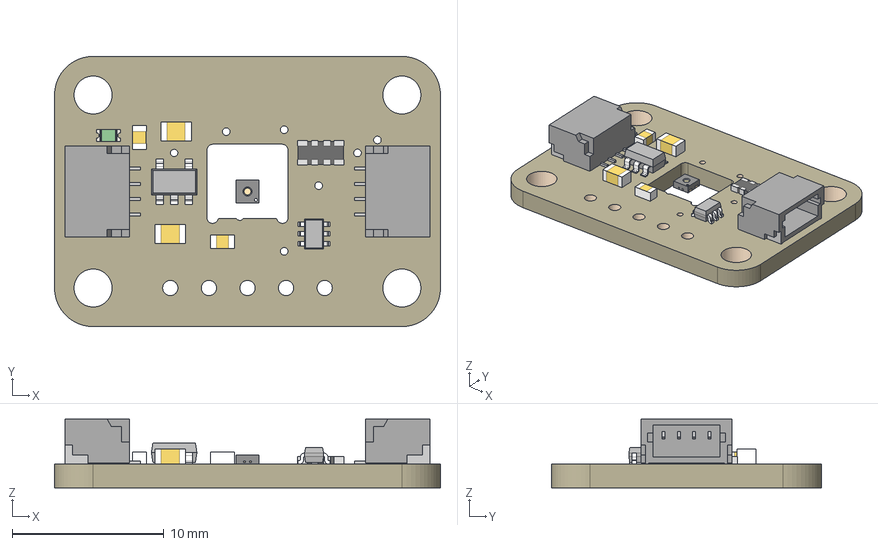
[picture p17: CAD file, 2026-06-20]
Adafruit Feather Mini Vario/CAD Files/5776 SHT41 Sensor PCB/5776 SHT41 Sensor - from SHT45 same SHT4x board family.step
25.4 x 17.8 x 4.53 mm
Board
10uF x 2
AP2127K-3.3
10K x 2
10K Pack
BSS138
STEMMA_I2C_QT x 2
GREEN
SHT4X_

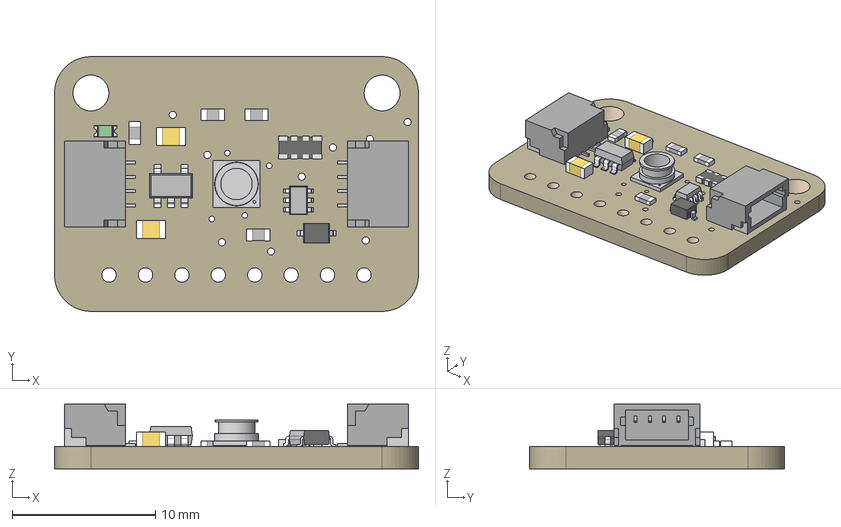
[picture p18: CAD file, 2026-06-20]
Adafruit Feather Mini Vario/CAD Files/6407 BMP581 Sensor PCB/6407 BMP581 Sensor - from BMP585 same BMP5xx board family.step
25.4 x 17.8 x 4.53 mm
Board
10K x 4
1N4148
10uF x 2
AP2127K-3.3
10K Pack
BSS138
STEMMA_I2C_QT x 2
GREEN
BMP585

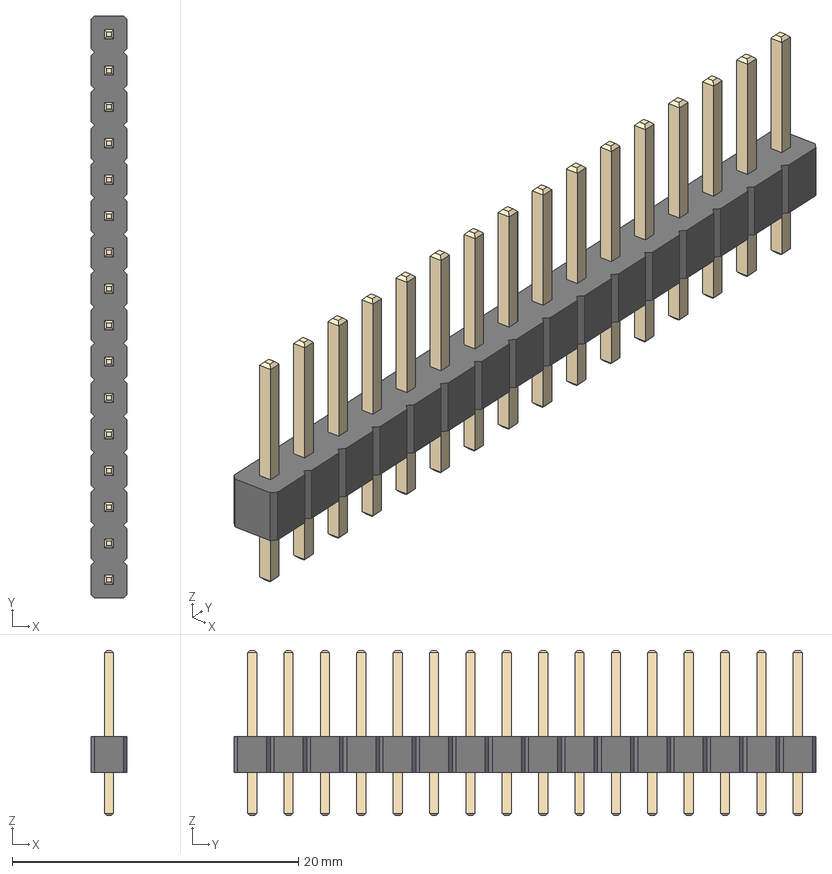
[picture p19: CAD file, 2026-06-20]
Adafruit Feather Mini Vario/CAD Files/Standard 2.54mm Male Headers/PinHeader_1x16_P2.54mm_Vertical.step
2.54 x 40.6 x 11.5 mm

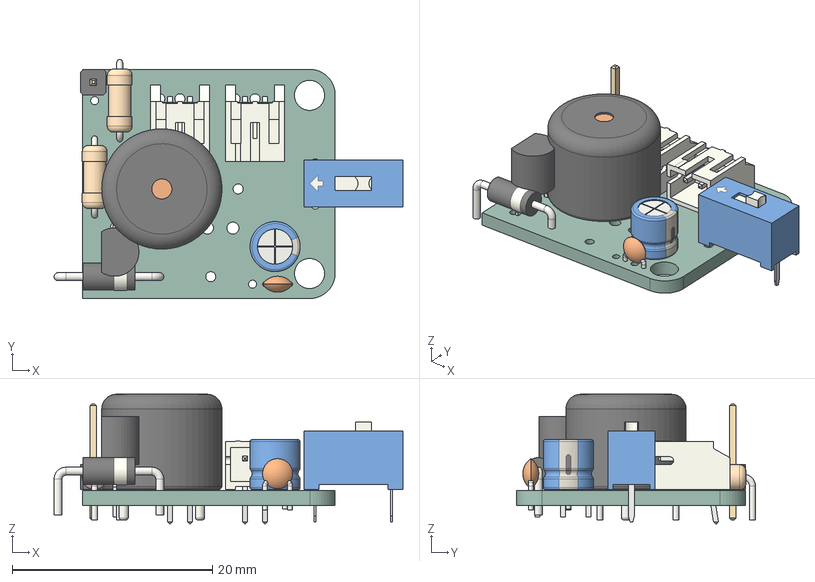
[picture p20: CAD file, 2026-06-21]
Adafruit Feather Mini Vario/KiCAD Files/Buzzer PCB with step up converter/STEP/PCB_with_models.step
34.8 x 23.8 x 12.9 mm
PinHeader_1x01_P254mm_Vertical
CP_Radial_D50mm_P200mm
C_Disc_D30mm_W16mm_P250mm
R_Axial_DIN0207_L63mm_D25mm_P762mm_Horizontal x 2
SW_DIP_SPSTx01_Slide_978x472mm_W762mm_P254mm
JST_S2B_PH_K x 2
TO-92_Inline_Wide
D_DO-41_SOD81_P10.16mm_Horizontal
Buzzer_12x95RM76
Buzzer PCB_PCB

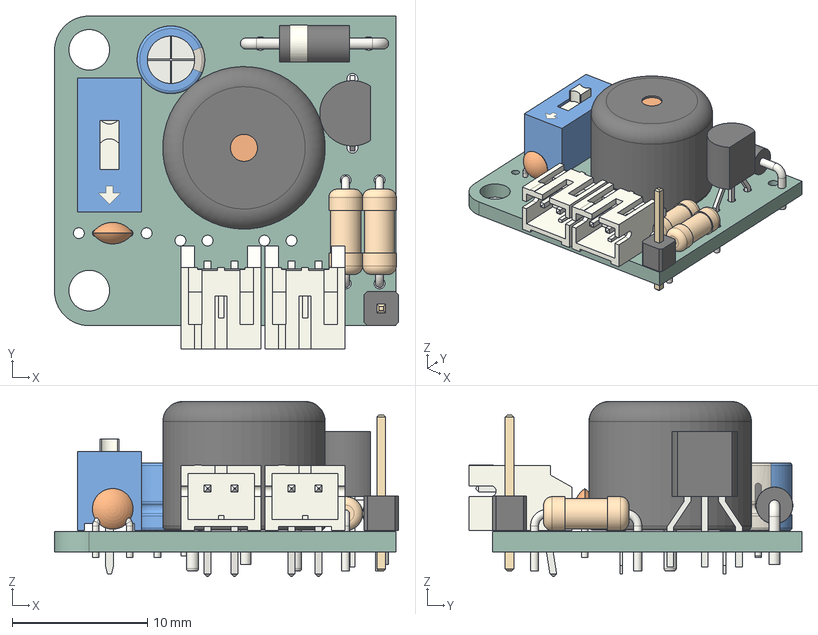
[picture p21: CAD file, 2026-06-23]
Adafruit Feather Mini Vario/KiCAD Files/Buzzer PCB/STEP/PCB.step
25.4 x 24.6 x 12.9 mm
PinHeader_1x01_P254mm_Vertical
CP_Radial_D50mm_P200mm
C_Disc_D30mm_W16mm_P250mm
R_Axial_DIN0207_L63mm_D25mm_P762mm_Horizontal x 2
SW_DIP_SPSTx01_Slide_978x472mm_W762mm_P254mm
JST_S2B_PH_K x 2
TO-92_Inline_Wide
D_DO-41_SOD81_P10.16mm_Horizontal
Buzzer_12x95RM76
Buzzer PCB_PCB

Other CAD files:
Adafruit Feather Mini Vario/CAD Files/261 JST PH 2-pin Cable/261 JST PH 2-pin cable female connector 100mm simplified.step
Adafruit Feather Mini Vario/CAD Files/261 JST PH 2-pin Connector Reference/261 JST PH 2-pin cable female connector 100mm simplified.step
Adafruit Feather Mini Vario/CAD Files/4210_4399 STEMMA QT Qwiic JST SH Cables/4399 STEMMA QT Qwiic JST SH 4-pin cable 50mm simplified.step
Adafruit Feather Mini Vario/CAD Files/4397 STEMMA QT to Female Sockets Cable/4397 STEMMA QT JST SH to female sockets cable 150mm simplified.step
Adafruit Feather Mini Vario/CAD Files/3299 M2.5 Standoff Reference/files/hex-standoff.scad
Adafruit Feather Mini Vario/CAD Files/261 JST PH 2-pin Connector Reference/JST_PH_B2B-PH-K_1x02_P2.00mm_Vertical.step
Adafruit Feather Mini Vario/CAD Files/2940 Short Feather Headers - Generic PinSocket Reference/PinSocket_1x12_P2.54mm_Vertical.step
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

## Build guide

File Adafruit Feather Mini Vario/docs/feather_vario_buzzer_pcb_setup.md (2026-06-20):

# Feather Vario Buzzer Power/Sound PCB Setup

## Purpose

This small PCB acts as a **battery power switch board** and **loud passive buzzer driver board** for the Feather-based vario build.

The system stack is:

```text
FeatherWing OLED
        ↓
400 mAh LiPo battery (sandwiched between adafruit feather and featherwing)
        ↓
Adafruit Feather
        ↓
custom power/buzzer PCB with switch + boost + buzzer driver
        ↓
BMP581 connected to featherwing through Qwiic/STEMMA QT (BMP sits adjacent to our custom PCB)
```

The custom PCB will sit underneath the Feather, adjacent to the BMP581 board.

---

## Important Connector Correction

For the battery path, use **JST-PH 2.0 mm**

```text
JST-PH 2.0 mm = Feather LiPo battery connector
JST-SH 1.0 mm = Qwiic/STEMMA QT connector
```

Do **not** connect the LiPo battery through a Qwiic/JST-SH connector. Qwiic is for 3.3V I2C devices only.

Use the Amazon parts you bought:

- **20 Sets JST PH 2.0 Connector 2 Pin Male/Female**
- **PH 2.0 mm Socket Kit, through-hole side-entry/right-angle PCB connectors**

The custom PCB should have:

```text
JST-PH 2mm 2pin female connector for battery input
JST-PH 2mm 2pin female connector for Feather battery output
switch to turn off all components (SS12D00G5)
```

---

## Main Components

### Purchased components

| Component | Purchased item / source description | Use |
|---|---|---|
| LiPo battery | 400 mAh battery | Main power source |
| Buzzer/transducer | 12085 passive buzzer, 12 mm × 8.5 mm, 42Ω | Loud variable-pitch sounder |
| Boost converter | Comidox 0.9–5V to 5V step-up module | Boosts LiPo/BAT voltage to 5V for buzzer | dimensions: 11x10.5mm (pin location to be determined, but order will be Vin, GND, Vout vertically)
| Transistor kit | ALLECIN 24-value BJT kit | S8050 as buzzer driver |
| Battery connectors | JST-PH 2.0 connector pigtails and PCB sockets | Battery in/out wiring |
| Switch | SS12D00G5 slide switch | Main power switch |
| Flyback diode | Existing 1N5819 Schottky diode | Protects driver transistor from buzzer coil kickback |

### Additional small parts needed

| Qty | Part | Suggested value |
|---:|---|---|
| 1 | Base resistor | 330Ω to 470Ω |
| 1 | Base pulldown resistor | 100kΩ |
| 1 | Bulk capacitor | 47µF to 100µF electrolytic |
| 1 | Ceramic decoupling capacitor | 0.1µF |
| 1 | single-pin header | D13 signal from Feather |

---

## Board Function Blocks

The PCB has two main sections:

1. **Power switching section**
2. **Buzzer driver section**

---

## 1. Power Switching Section

The LiPo battery plugs into the custom PCB first. The PCB switch controls power to the entire device.

### Battery path

```text
LiPo battery +
        ↓
JST-PH battery input +
        ↓
SS12D00G5 slide switch
        ↓
switched BAT+
        ↓
JST-PH output +
        ↓
Feather battery input +
```

Ground is not switched:

```text
LiPo battery -
        ↓
JST-PH battery input -
        ↓
PCB GND
        ↓
JST-PH output -
        ↓
Feather battery input -
```

### Switch wiring

Use the SS12D00G5 as a simple inline power switch on the **positive battery lead**.

```text
Battery + → switch common
switch ON terminal → switched BAT+
unused switch terminal → not connected
```

Before final soldering, verify the switch pins with a multimeter. Do not assume the pinout from the package shape.

---

## 2. Buzzer Driver Section

The buzzer should be driven from the boosted 5V rail through an NPN low-side switch.

### Recommended transistor

Use this one from from the ALLECIN kit:

```text
S8050 NPN

```

---

## Electrical Connections

### Boost converter

The Comidox boost converter has:

```text
VIN
GND
VOUT
```

Wire it like this:

```text
switched BAT+ → boost VIN
PCB GND       → boost GND
boost VOUT    → BOOST_5V
```

The boost converter should receive power **after the main switch**, so it is fully off when the device switch is off.

---

## Buzzer circuit

```text
BOOST_5V → buzzer +
buzzer - → transistor collector
transistor emitter → GND
```

### Transistor base drive

```text
Feather D13 → 330Ω–470Ω resistor → transistor base
transistor base → 100kΩ resistor → GND
```

### Flyback diode

Use your existing **1N5819** across the buzzer.

```text
1N5819 stripe/cathode side → BOOST_5V / buzzer +
1N5819 non-stripe/anode    → buzzer - / transistor collector
```

The diode is normally reverse-biased during operation. It protects the transistor from the magnetic buzzer coil’s voltage spike.

### Capacitors

Place these close to the boost converter output and buzzer driver:

```text
47–100µF electrolytic:
+ → BOOST_5V
- → GND

0.1µF ceramic:
BOOST_5V → GND
```

---

## Feather Connections

The custom PCB connects to the Feather using:

```text
D13
GND
```

The power path to the Feather is handled through the Feather’s battery input connector.

### Signal connection

Use **D13** as the buzzer PWM/tone signal.

```text
Feather D13 → custom PCB BUZZER_SIG
```

---

## FeatherWing / Feather Header Plan

The OLED FeatherWing is pre-soldered and connects to the Feather through female headers.

The OLED FeatherWing uses:

```text
3V
GND
SDA
SCL
```

The BMP581 connects through the OLED FeatherWing’s Qwiic/STEMMA QT port.

The buzzer PCB does **not** connect through Qwiic. It uses D13 for the buzzer signal and the switched battery path for power.

### D27 note

Since the buzzer signal is now planned for **D13**, removing the D27 header pin is not electrically required for the buzzer circuit.

If D27 removal is only for physical clearance, it is acceptable. If there is no clearance issue, leave D27 installed.

---

## Overall Wiring Diagram

```text
                      ┌──────────────────────────┐
                      │  Custom Power/Buzzer PCB │
                      │                          │
LiPo Battery + ───────┤ JST-PH IN +              │
LiPo Battery - ───────┤ JST-PH IN -              │
                      │                          │
                      │ IN+ → switch → BAT_SW+   │
                      │ IN- → GND                │
                      │                          │
                      │ BAT_SW+ → JST-PH OUT + ──┼────→ Feather battery +
                      │ GND     → JST-PH OUT - ──┼────→ Feather battery -
                      │                          │
                      │ BAT_SW+ → boost VIN      │
                      │ GND     → boost GND      │
                      │ boost VOUT → BOOST_5V    │
                      │                          │
Feather D13 ──────────┤ BUZZER_SIG               │
Feather GND ──────────┤ optional extra GND       │
                      │                          │
                      │ BOOST_5V → buzzer +      │
                      │ buzzer - → transistor C  │
                      │ transistor E → GND       │
                      └──────────────────────────┘
```

---

## Suggested Net Names

Use these net names in KiCad/Fusion:

```text
BAT_IN
BAT_SW
GND
BOOST_5V
BUZZER_SIG
BUZZER_LOW
```

Connections:

```text
BAT_IN      = battery input positive before switch
BAT_SW      = switched battery positive after switch
GND         = battery negative / system ground
BOOST_5V    = 5V boost output
BUZZER_SIG  = D13 signal from Feather
BUZZER_LOW  = buzzer negative / transistor collector
```

---

## Suggested Net Classes / Trace Widths

For a CNC-milled single-sided board:

| Net class | Nets | Suggested trace width |
|---|---|---:|
| Power | BAT_IN, BAT_SW, BOOST_5V, GND, BUZZER_LOW | 2.0 mm |
| Signal | BUZZER_SIG | 0.3–0.5 mm |
Please create pad diameters that are as large as possible without overlapping eachother. There should be 0.55mm between each pad minimum. When possible, if 3mm diameter pads that are adjacent allows for 0.55mm clearance between them, when possible make the pads slot shaped (5mm long and 3mm wide for example)

Use wider traces if space allows, especially on:

```text
BAT_SW → boost VIN
boost VOUT → buzzer +
buzzer - → transistor collector
transistor emitter → GND
```

---

---

## Example ESP32 Arduino Test Code

```cpp
const int BUZZER_PIN = 13;
const int BUZZER_CH = 0;

void setup() {
  pinMode(BUZZER_PIN, OUTPUT);
  digitalWrite(BUZZER_PIN, LOW);

  ledcSetup(BUZZER_CH, 3000, 8);
  ledcAttachPin(BUZZER_PIN, BUZZER_CH);
}

void loop() {
  ledcWriteTone(BUZZER_CH, 2500);
  delay(150);

  ledcWriteTone(BUZZER_CH, 0);
  digitalWrite(BUZZER_PIN, LOW);
  delay(250);

  ledcWriteTone(BUZZER_CH, 4000);
  delay(150);

  ledcWriteTone(BUZZER_CH, 0);
  digitalWrite(BUZZER_PIN, LOW);
  delay(500);
}
```

---

## Sleep / Off Behavior

The main slide switch cuts power from the LiPo to:

```text
Feather
OLED FeatherWing
BMP581
boost converter
buzzer driver
```

So when the switch is off, there should be essentially no battery drain from the electronics.

Deep sleep is separate from true off. The switch is what provides true off.

Before entering ESP32 deep sleep, the firmware should still stop the buzzer:

```cpp
ledcWriteTone(BUZZER_CH, 0);
digitalWrite(BUZZER_PIN, LOW);
pinMode(BUZZER_PIN, OUTPUT);
```

Also turn off the OLED display before sleep if using deep sleep without switching the device fully off.

---

## Critical Warnings

1. **Battery polarity matters.**  
   Some Amazon JST-PH cables may have reversed polarity compared with Adafruit/Feather wiring. Verify with a multimeter before plugging into the Feather.

2. **Do not use JST-SH/Qwiic for battery power.**  
   Qwiic/STEMMA QT is 3.3V I2C only.

3. **Do not drive the 42Ω buzzer directly from a Feather GPIO.**  
   Use the transistor driver.

4. **Verify transistor pinout before milling.**  
   S8050 may have different pin orders depending on package/vendor.

5. **Verify switch pinout before milling.**  
   Use continuity mode to identify common and switched terminals.

6. **Use a shared ground.**  
   Feather GND, boost GND, buzzer driver GND, and battery negative must all be common.

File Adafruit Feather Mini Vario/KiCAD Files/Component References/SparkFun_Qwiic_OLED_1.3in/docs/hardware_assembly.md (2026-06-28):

---
icon: fontawesome/solid/screwdriver-wrench
---

SparkFun's Qwiic system makes components plug and play. Simply plug one end of your Qwiic cable into the Qwiic connector on your OLED screen and the other end of the Qwiic cable into the controller board (here we're using the RedBoard Qwiic). Now connect your controller board to the computer and voila. You're ready to rock. 

<figure markdown>
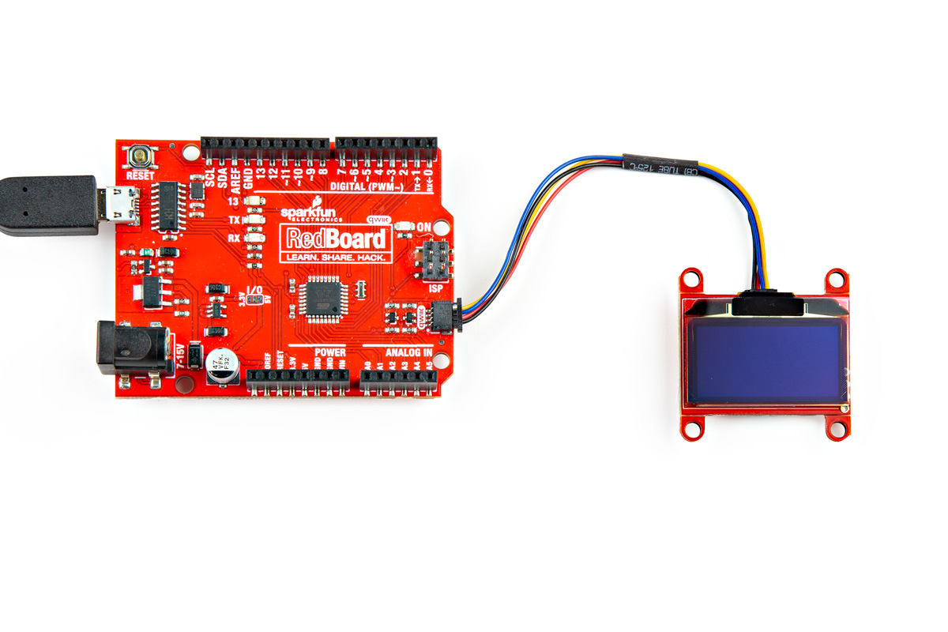
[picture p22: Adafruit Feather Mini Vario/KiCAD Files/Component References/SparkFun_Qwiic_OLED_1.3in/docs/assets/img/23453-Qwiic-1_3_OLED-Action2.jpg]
Qwiic OLED connected to the Qwiic RedBoard

<figcaption markdown>SparkFun Qwiic OLED connected to the SparkFun Qwiic RedBoard</figcaption>
</figure>

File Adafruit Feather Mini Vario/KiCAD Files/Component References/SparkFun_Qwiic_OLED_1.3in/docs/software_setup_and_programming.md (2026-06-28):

---
icon: simple/arduino
---

!!! arduino

    ### Arduino IDE

    This example assumes you are using the latest version of the Arduino IDE on your desktop. If this is your first time using Arduino IDE and an library, please review the following tutorials.

    - [Installing the Arduino IDE](https://learn.sparkfun.com/tutorials/installing-arduino-ide)
    - [Installing an Arduino Library](https://learn.sparkfun.com/tutorials/installing-an-arduino-library)

SparkFun has leveraged our existing OLED library to work with the SparkFun Qwiic OLED 1.3 board. If you haven't already worked with our OLED boards, you can obtain this library through the Arduino Library Manager by searching for "Qwiic OLED" and installing the latest version. If you prefer downloading libraries manually, you can grab them from the GitHub Repository.

<div style="text-align: center"><a href="https://github.com/sparkfun/SparkFun_Qwiic_OLED_Arduino_Library/archive/refs/heads/main.zip" target="qwiic_oled_arduino_library" class="md-button">SparkFun Qwiic OLED Arduino Library GitHub</a></div>

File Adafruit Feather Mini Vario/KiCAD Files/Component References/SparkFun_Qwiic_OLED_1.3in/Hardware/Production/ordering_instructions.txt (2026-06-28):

panel size, 122x136mm
PCB thickness, 1.6mm
number of layers, 2
soldermask color, Red
silkscreen color, White
oz copper, 1oz
finish, HASL lead free
stencils, top+bottom
pcs per panel, 9
min trace width, 0.2540mm / 0.0100in
min drill size, 0.3000mm / 0.0118in

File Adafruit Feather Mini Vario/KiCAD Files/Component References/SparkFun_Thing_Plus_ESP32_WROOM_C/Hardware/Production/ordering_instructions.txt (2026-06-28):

panel size, 107x204mm
PCB thickness, 1.6mm
number of layers, 2
soldermask color, Red
silkscreen color, White
oz copper, 1oz
finish, HASL lead free
stencils, none
pcs per panel, 12
min trace width, 0.1270mm / 0.0050in
min drill size, 0.3048mm / 0.0120in

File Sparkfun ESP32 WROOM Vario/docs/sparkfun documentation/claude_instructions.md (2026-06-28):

To process any PDFs, please use Microsoft MarkItDown MCP

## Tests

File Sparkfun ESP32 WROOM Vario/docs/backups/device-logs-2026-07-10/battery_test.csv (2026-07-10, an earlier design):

millis | elapsed_s | event | battery_voltage | battery_percent | wifi_status | ssid | bluetooth_enabled | oled_enabled
260124 | 199 | log_cleared | 4.121 | 103.0 | connected | Warehouse_2G | 0 | 1
261413 | 0 | logging_started | 4.130 | 103.0 | connected | Warehouse_2G | 0 | 1
261427 | 0 | sample | 4.130 | 103.0 | connected | Warehouse_2G | 0 | 1
261927 | 0 | sample | 4.130 | 103.0 | connected | Warehouse_2G | 0 | 1
262427 | 1 | sample | 4.126 | 103.0 | connected | Warehouse_2G | 0 | 1
262927 | 1 | sample | 4.126 | 103.0 | connected | Warehouse_2G | 0 | 1
263427 | 2 | sample | 4.129 | 103.0 | connected | Warehouse_2G | 0 | 1
263927 | 2 | sample | 4.129 | 103.0 | connected | Warehouse_2G | 0 | 1
264427 | 3 | sample | 4.130 | 103.0 | connected | Warehouse_2G | 0 | 1
264927 | 3 | sample | 4.130 | 103.0 | connected | Warehouse_2G | 0 | 1
265107 | 3 | logging_stopped | 4.130 | 103.0 | connected | Warehouse_2G | 0 | 1
265732 | 0 | logging_started | 4.130 | 103.0 | connected | Warehouse_2G | 0 | 1
265746 | 0 | sample | 4.130 | 103.0 | connected | Warehouse_2G | 0 | 1
266246 | 0 | sample | 4.129 | 103.0 | connected | Warehouse_2G | 0 | 1
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

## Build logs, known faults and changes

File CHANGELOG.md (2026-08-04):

# Changelog

Versions track the SparkFun `Sparkfun_Vario` firmware (`version.h`). Bump
`VARIO_FW_VERSION` in the same commit that changes behaviour.

## 1.4.0 — 2026-08-04

- **Fix: Flyskyhy/Gaggle connect but receive no telemetry.** Devices named
  `BlueFly-*` are handled as real BlueFlyVarios, whose RN4677 radio exposes
  Microchip Transparent UART (`49535343-...`), not Nordic UART or HM-10.
  The firmware now streams on all three profiles. It also exposes standard
  Environmental Sensing Pressure (2A6D) at Flyskyhy's required 10 Hz and
  logs notification subscriptions over USB serial for field diagnosis.
- **Temperature over BLE.** Environmental Sensing (181A) with the standard
  Temperature characteristic (2A6E), notified at 1 Hz — drives Flyskyhy's
  Temperature instrument. Same reading the LK8EX1 temp field carries: SHT41
  when present, the BMP's own sensor otherwise.
- **Buttons over BLE.** Automation IO (1815) with the Digital characteristic
  (2A56), 2 bits per button (back / encoder push / confirm) plus the Number
  of Digitals descriptor. Notified on change, not on a tick, so a click
  reaches the app immediately.
- **Fix: LK8EX1 battery field.** Was sent as 1000+volts×10 (4.1 V read as
  "41%" by spec-compliant apps). Now sends 1000+percent when the fuel gauge
  reports one, plain voltage float otherwise, per the LK8EX1 spec.
- **Fix: keep advertising while connected** (up to 3 concurrent centrals).
  Previously the first client (a Mac, Flyskyhy left in the background) made
  the vario invisible to everyone else — the usual cause of Gaggle's
  "connection failed". Telemetry notifies fan out to every subscriber.

## 1.3.0 — 2026-08-04

- **Dual BLE serial services.** Sentences now stream simultaneously over the
  HM-10 dialect (FFE0/FFE1, what Flyskyhy documents) AND Nordic UART
  (6E4000xx, the XCTracer-style dialect Gaggle handles best) — aimed at the
  "Gaggle stuck on connecting / Flyskyhy lists but won't select" reports.
  Standard Battery (180F, live percent) and Device Information (180A)
  services added too; apps probe these right after connecting.
- **GPS over BLE.** $GPGGA + $GPRMC at 1 Hz to the phone apps, with a
  Settings → Bluetooth toggle ("Send GPS to apps") and an OLED menu item
  (GPS → BLE GPS out). Automatically silent while GPS is disabled, has no
  fix, or the fix is >5 s stale.
- **Configurable BLE name** (Settings → Bluetooth, applied at next boot) —
  some apps recognise varios by advertised name, so this makes
  experimenting easy. Blank resets to "SparkFun Vario".

## 1.2.0 — 2026-08-04

- **WiFi + BLE in one image.** The WiFi build now carries BLE LK8EX1 telemetry
  alongside the web app — no more firmware-switching to feed Gaggle/Flyskyhy.
  Made possible by NimBLE (the 2023 split was forced by Bluedroid Classic) plus
  stubbing the unused RGB-LED/RMT driver to claw back the last ~2 KB of IRAM.
  The BT-only build remains as a low-power variant.
- **Fix: toggling Bluetooth off rebooted the device** — `NimBLEDevice::deinit()`
  crashes in practice; the stack now inits once and "off" just stops advertising
  and drops the client.
- **Fix: Settings tab JS died** referencing a Bluetooth toggle that didn't exist;
  the toggle now actually exists (Settings → Bluetooth → BLE telemetry).
- Note: generic BLE devices never appear in iOS/macOS Settings scan lists —
  connect from inside the flight app (or verify with LightBlue).

## 1.1.0 — 2026-08-03

- **BLE vario telemetry (BT build).** The BT firmware now advertises as
  `SparkFun Vario` over BLE (HM-10-style service FFE0/FFE1) and streams
  `$LK8EX1` sentences at 5 Hz — pressure, altitude, vario, temperature and
  battery — so iPhone flight apps (Gaggle, Flyskyhy) can use it as an external
  baro/vario, exactly like a BlueFlyVario. Replaces the old Bluetooth Classic
  SPP, which iOS could not see at all. OLED `bt_status` shows Off / Adv / Linked.
- **Faster logging.** Log rates now go down to 0.2 s (5 Hz) and 0.5 s; the CSV's
  `millis` column carries the sub-second timing. NOTE: the saved log-rate
  preference is an index, so after flashing re-pick your rate once (old
  selections shift two steps faster).
- **Flight log names.** Per-flight CSVs are now `/logs/flight_YYYY_MM_DD_HH-MM-SS.csv`
  (local start time; FAT forbids `:` so the time is dash-separated).
- **Idle log size cap.** Settings → Logging: "Idle log limit (MB)" rotates
  `/vario_log.csv` to `_old` past the cap (0 = unlimited, the old behaviour).
- **SD usage.** Card used/total shown in the web SD tab (with a bar) and as a
  new `sd_usage` OLED panel field on both firmwares.
- **Per-firmware OLED layouts.** Layouts live in `/config/windows_wifi.json` and
  `/config/windows_bt.json`; the designer grew a "Layout for" selector so the
  WiFi build's browser can edit the BT build's screens (saved to SD, loaded when
  that firmware boots). Old `/config/windows.json` still loads as a fallback.

## 1.0.0 — 2026-08-03

First numbered release. Baseline of everything already shipping on the device:

- Two mutually exclusive radio builds (WiFi / BT A2DP) selected in `radio_config.h`,
  swappable on the device via SD self-flash (Menu → System → Switch FW).
- Web app served from the device: live data, settings, OLED window designer, map,
  WiFi manager, SD file browser, Buzzer Lab, OTA update.
- OLED menu with categories: Power & Lock, Vario & Audio, Clock, Altitude, IMU,
  Flight, GPS, Logging, System.
- Clock synced from GPS and NTP (most recent source wins), 12h/24h toggle and a
  saved timezone offset.
- Button lock (hold Select+Back), staged OLED/WiFi/BT toggles applied on lock.
- Tunable vario tone model: 1–3 buzzers, thresholds, pitch slope, two-tone.
- Configurable Bluetooth earbud name.
- MAX17048 fuel gauge battery monitoring, SD data + battery logging.
- **New in this release:** firmware version reporting — Menu → System → About,
  the web app header and System → About card, and `fw_version` / `fw_radio` /
  `fw_build` in `GET /api/settings`.

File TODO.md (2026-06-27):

# TODO

## Battery Voltage

- [ ] Future hardware/firmware change: remove the WS2812B NeoPixel from A1/GPIO25 and repurpose A1 for battery voltage sensing through a resistor divider. Do not remove the current NeoPixel firmware until this hardware change is ready.

## Temperature Self-Heating Compensation

- [ ] Run the vario in a constant-temperature room for 30-45 minutes while logging SHT41 temperature, SHT41 humidity, BMP temperature, BMP pressure/altitude, battery voltage, and runtime.
- [ ] Use the warmup data to estimate how much the PCB heats the sensors after startup.
- [ ] Add a firmware correction for displayed/logged temperature based on runtime or measured warmup behavior.
- [ ] Validate the correction with a second constant-temperature run.

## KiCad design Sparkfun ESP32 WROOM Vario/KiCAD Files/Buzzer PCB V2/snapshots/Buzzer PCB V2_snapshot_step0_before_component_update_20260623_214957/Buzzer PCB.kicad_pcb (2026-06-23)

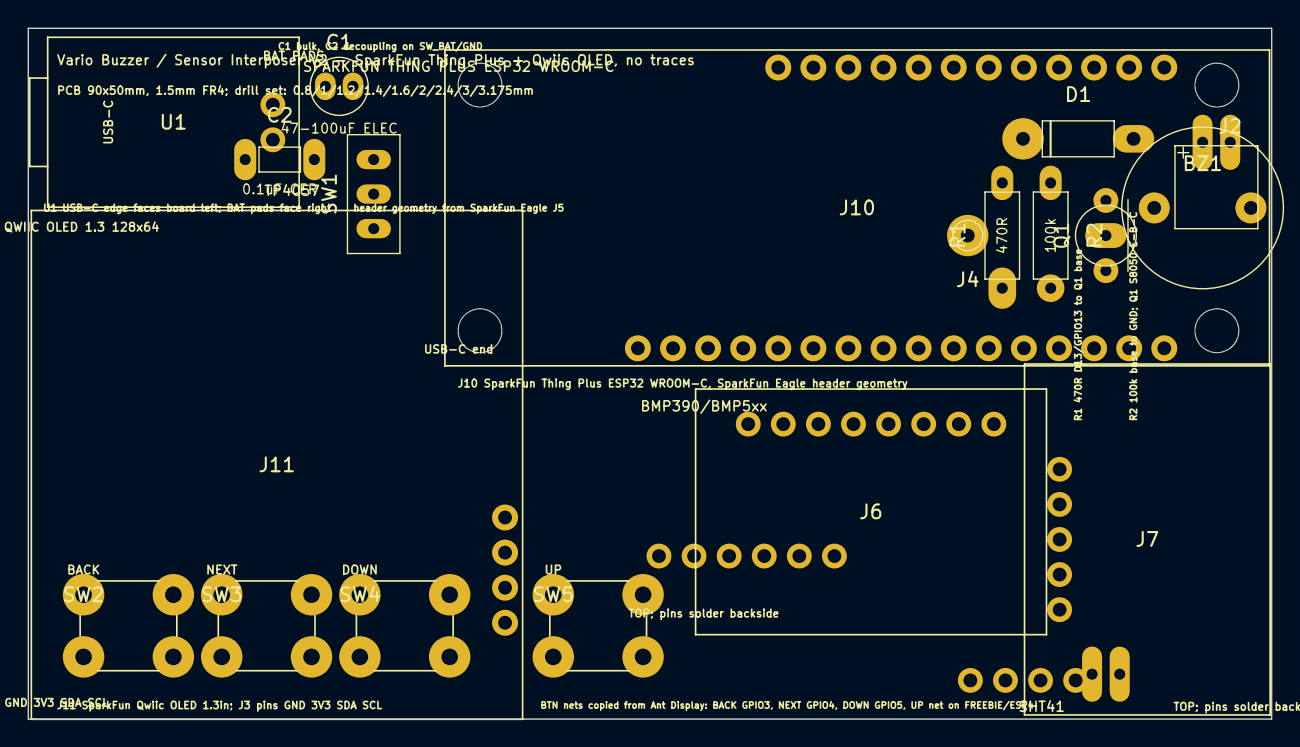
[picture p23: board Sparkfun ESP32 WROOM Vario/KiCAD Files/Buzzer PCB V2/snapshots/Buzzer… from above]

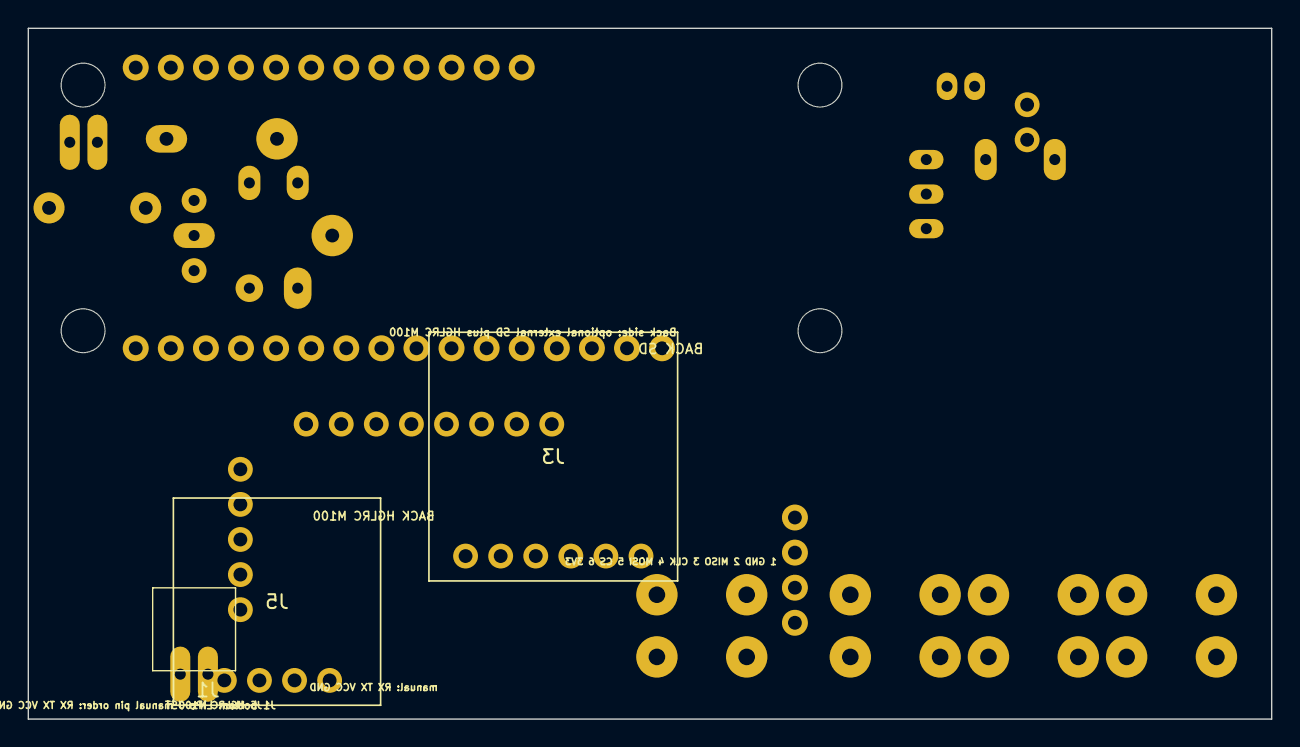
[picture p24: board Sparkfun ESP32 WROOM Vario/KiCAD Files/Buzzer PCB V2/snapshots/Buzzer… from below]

Board: 2 copper layers, 90.0 x 50.0 mm, 22 parts (3 on the bottom side), 19 nets, no tracks yet.

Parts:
BZ1: 12085 Passive Buzzer 42R; Buzzer_12x8.5mm_P7.62mm_Custom
C1: 47-100uF ELEC; CP_Radial_D5.0mm_P2.00mm
C2: 0.1uF CER; C_Disc_D3.0mm_W1.6mm_P2.50mm
D1: 1N5819; D_DO-41_SOD81_P10.16mm_Horizontal
J1: 2600mAh LiPo JST-PH bottom; JST_PH_S2B-PH-K_1x02_P2.00mm_Horizontal
J2: Legacy SW_BAT/GND out; JST_PH_S2B-PH-K_1x02_P2.00mm_Horizontal
J3: Optional external SD module; Thing Plus has onboa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; SD_Module_18x18_6Pin_Back
J4: Legacy D13 test pad; PinHeader_1x01_P2.54mm_Vertical
J5: HGLRC M100 Mini GPS manual pinout; GPS_M100_15x15_4Pin_Back
J6: BMP390/BMP5xx top pads; Adafruit_BMP390_Breakout_Top
J7: SHT41 top pads; Adafruit_SHT41_Breakout_Top
J10: SparkFun Thing Plus ESP32 WROOM-C USB-C header; SparkFun_Thing_Plus_ESP32_WROOM_C_Header
J11: SparkFun Qwiic OLED 1.3in module; SparkFun_Qwiic_OLED_1p3_Module
Q1: S8050; TO-92_Inline_Wide_Formed
R1: 470R; R_Axial_DIN0207_L6.3mm_D2.5mm_P7.62mm_Horizontal
R2: 100k; R_Axial_DIN0207_L6.3mm_D2.5mm_P7.62mm_Horizontal
SW1: SS12D00G5; SS12D00G5_Custom
SW2: BACK; Ant_Display_SW_PUSH_6mm_H5mm
SW3: NEXT; Ant_Display_SW_PUSH_6mm_H5mm
SW4: DOWN; Ant_Display_SW_PUSH_6mm_H5mm
SW5: UP; Ant_Display_SW_PUSH_6mm_H5mm
U1: TP4057 USB-C charger; TP4057_Module_18.2x12.3

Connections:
3V3: J3.6 (3V3), J5.3 (VCC 3.3-5V), J6.1 (VCC), J6.2 (3V3), J7.1 (VCC), J7.2 (3V3), J10.27 (3V3), J11.2 (VDD)
BAT_IN: J1.1 (+), SW1.2 (COM), U1.1 (BAT+)
BTN_BACK_GPIO3: J10.6 (GPIO3 / ESP33), SW2.1
BTN_DOWN_GPIO5: J10.4 (GPIO5 / ESP32), SW4.1
BTN_NEXT_GPIO4: J10.5 (GPIO4 / ESP15), SW3.1
BTN_UP_GPIO21: J10.13 (FREEBIE / ESP4), SW5.1
BUZZER_BASE: Q1.2 (B), R1.2, R2.1
BUZZER_LOW: BZ1.2 (-), D1.2 (A), Q1.3 (C)
D13_BUZZER_GPIO13: J4.e (D13/GPIO13 test), J10.9 (GPIO0 / ESP13 / STAT), R1.1
GND: C1.2 (-), C2.2 (-), J1.2 (-), J2.2 (-), J3.1 (GND), J5.4 (GND), J6.3 (GND), J7.3 (GND), J10.25 (GND), J11.1 (GND), Q1.1 (E), R2.2, SW2.2, SW3.2, SW4.2, SW5.2, U1.2 (BAT-)
GPS_RX_THING_TX: J5.1 (RX), J10.14 (TX / ESP17)
GPS_TX_THING_RX: J5.2 (TX), J10.15 (RX / ESP16)
SCL: J6.4 (SCK/SCL), J7.4 (SCL), J10.2 (SCL / ESP22), J11.4 (SCL)
SDA: J6.6 (SDI/SDA), J7.5 (SDA), J10.1 (SDA / ESP21), J11.3 (SDA)
SD_CS_GPIO2: J3.5 (CS), J10.7 (GPIO2 / ESP27)
SPI_MISO: J3.2 (MISO), J10.16 (POCI / ESP19)
SPI_MOSI: J3.4 (MOSI), J10.17 (PICO / ESP23)
SPI_SCK: J3.3 (CLK), J10.18 (SCK / ESP18)
SW_BAT: BZ1.1 (+), C1.1 (+), C2.1 (+), D1.1 (K), J2.1 (+), J10.12 (V_BATT), SW1.1 (ON)

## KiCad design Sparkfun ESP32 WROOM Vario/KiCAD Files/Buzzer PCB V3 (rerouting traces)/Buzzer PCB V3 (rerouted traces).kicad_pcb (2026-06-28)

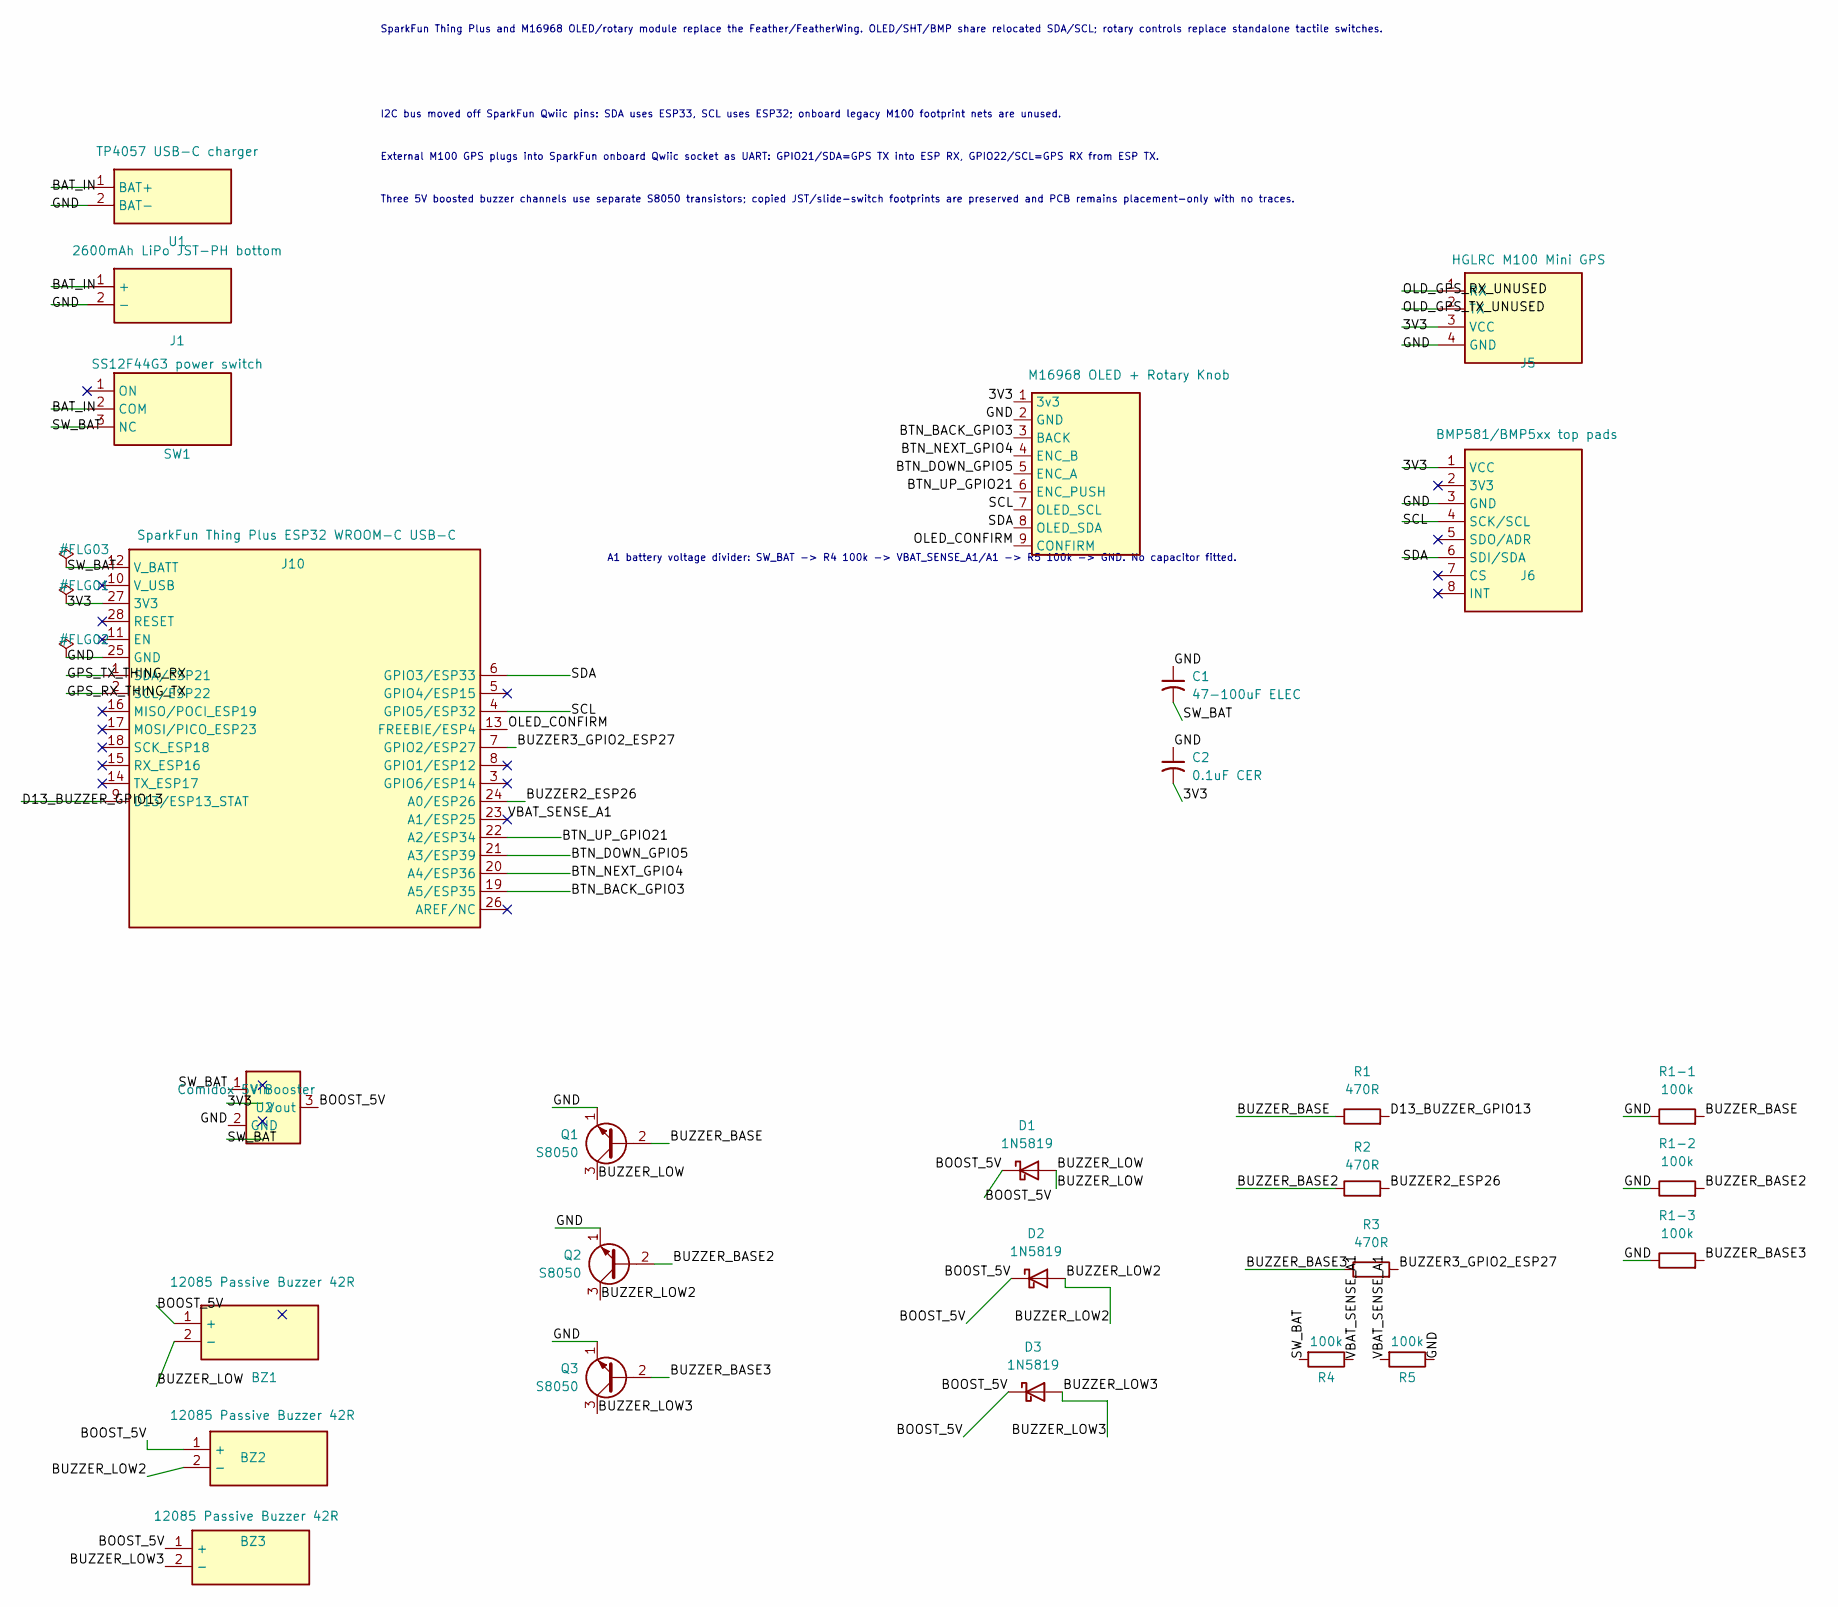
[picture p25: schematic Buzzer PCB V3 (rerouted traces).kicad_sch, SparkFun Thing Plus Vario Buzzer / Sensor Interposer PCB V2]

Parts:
BZ1, BZ2, BZ3: 12085 Passive Buzzer 42R; Buzzer_12x8.5mm_P7.62mm_Custom
C1: 47-100uF ELEC; CP_Radial_D5.0mm_P2.00mm
C2: 0.1uF CER; Ceramic_Cap_0.1uF_P5.00mm_V1
D1, D2, D3: 1N5819; D_DO-41_SOD81_P10.16mm_Horizontal
J1: 2600mAh LiPo JST-PH bottom; JST_PH_S2B-PH-K_1x02_P2.00mm_Horizontal
J5: HGLRC M100 Mini GPS; GPS_M100_15x15_4Pin_Back
J6: BMP581/BMP5xx top pads; Adafruit_BMP390_Breakout_Top
J10: SparkFun Thing Plus ESP32 WROOM-C USB-C; SparkFun_Thing_Plus_ESP32_WROOM_C_Header
J11: M16968 OLED + Rotary Knob; OLED_M16968_59x35_9Pin
Q1, Q2, Q3: S8050; TO-92_Inline
R1, R2, R3: 470R; R_Axial_DIN0207_L6.3mm_D2.5mm_P10.16mm_Horizontal
R1-1, R1-2, R1-3, R4, R5: 100k; R_Axial_DIN0207_L6.3mm_D2.5mm_P10.16mm_Horizontal
SW1: SS12F44G3 power switch; SS12F44G3_5.9x12.25_P3.00
U1: TP4057 USB-C charger; TP4057_Module_12.2x18.5
U2: Comidox 5V Booster; Comidox_5V_Booster_10.75x10.75_3Pin

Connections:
/3V3: C2.2, J5.3 (VCC), J6.1 (VCC), J10.27 (3V3), J11.1 (3v3)
/BAT_IN: J1.1 (+), SW1.2 (COM), U1.1 (BAT+)
/BOOST_5V: BZ1.1 (+), BZ2.1 (+), BZ3.1 (+), D1.1 (K), D2.1 (K), D3.1 (K), U2.3 (Vout)
/BTN_BACK_GPIO3: J10.19 (A5/ESP35), J11.3 (BACK)
/BTN_DOWN_GPIO5: J10.21 (A3/ESP39), J11.5 (ENC_A)
/BTN_NEXT_GPIO4: J10.20 (A4/ESP36), J11.4 (ENC_B)
/BTN_UP_GPIO21: J10.22 (A2/ESP34), J11.6 (ENC_PUSH)
/BUZZER2_ESP26: J10.24 (A0/ESP26), R2.2
/BUZZER3_GPIO2_ESP27: J10.7 (GPIO2/ESP27), R3.2
/BUZZER_BASE: Q1.2 (B), R1.1, R1-1.2
/BUZZER_BASE2: Q2.2 (B), R1-2.2, R2.1
/BUZZER_BASE3: Q3.2 (B), R1-3.2, R3.1
/BUZZER_LOW: BZ1.2 (-), D1.2 (A), Q1.3 (C)
/BUZZER_LOW2: BZ2.2 (-), D2.2 (A), Q2.3 (C)
/BUZZER_LOW3: BZ3.2 (-), D3.2 (A), Q3.3 (C)
/D13_BUZZER_GPIO13: J10.9 (D13/ESP13_STAT), R1.2
/GND: C1.1, C2.1, J1.2 (-), J5.4 (GND), J6.3 (GND), J10.25 (GND), J11.2 (GND), Q1.1 (E), Q2.1 (E), Q3.1 (E), R1-1.1, R1-2.1, R1-3.1, R5.1, U1.2 (BAT-), U2.2 (GND)
/GPS_RX_THING_TX: J10.2 (SCL/ESP22)
/GPS_TX_THING_RX: J10.1 (SDA/ESP21)
/OLD_GPS_RX_UNUSED: J5.1 (RX)
/OLD_GPS_TX_UNUSED: J5.2 (TX)
/OLED_CONFIRM: J10.13 (FREEBIE/ESP4), J11.9 (CONFIRM)
/SCL: J6.4 (SCK/SCL), J10.4 (GPIO5/ESP32), J11.7 (OLED_SCL)
/SDA: J6.6 (SDI/SDA), J10.6 (GPIO3/ESP33), J11.8 (OLED_SDA)
/SW_BAT: C1.2, J10.12 (V_BATT), R4.2, SW1.3 (NC), U2.1 (Vin)
/VBAT_SENSE_A1: J10.23 (A1/ESP25), R4.1, R5.2

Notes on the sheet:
External M100 GPS plugs into SparkFun onboard Qwiic socket as UART: GPIO21/SDA=GPS TX into ESP RX, GPIO22/SCL=GPS RX from ESP TX.
I2C bus moved off SparkFun Qwiic pins: SDA uses ESP33, SCL uses ESP32; onboard legacy M100 footprint nets are unused.
SparkFun Thing Plus and M16968 OLED/rotary module replace the Feather/FeatherWing. OLED/SHT/BMP share relocated SDA/SCL; rotary controls replace standalone tactile switches.
A1 battery voltage divider: SW_BAT -> R4 100k -> VBAT_SENSE_A1/A1 -> R5 100k -> GND. No capacitor fitted.
Three 5V boosted buzzer channels use separate S8050 transistors; copied JST/slide-switch footprints are preserved and PCB remains placement-only with no traces.

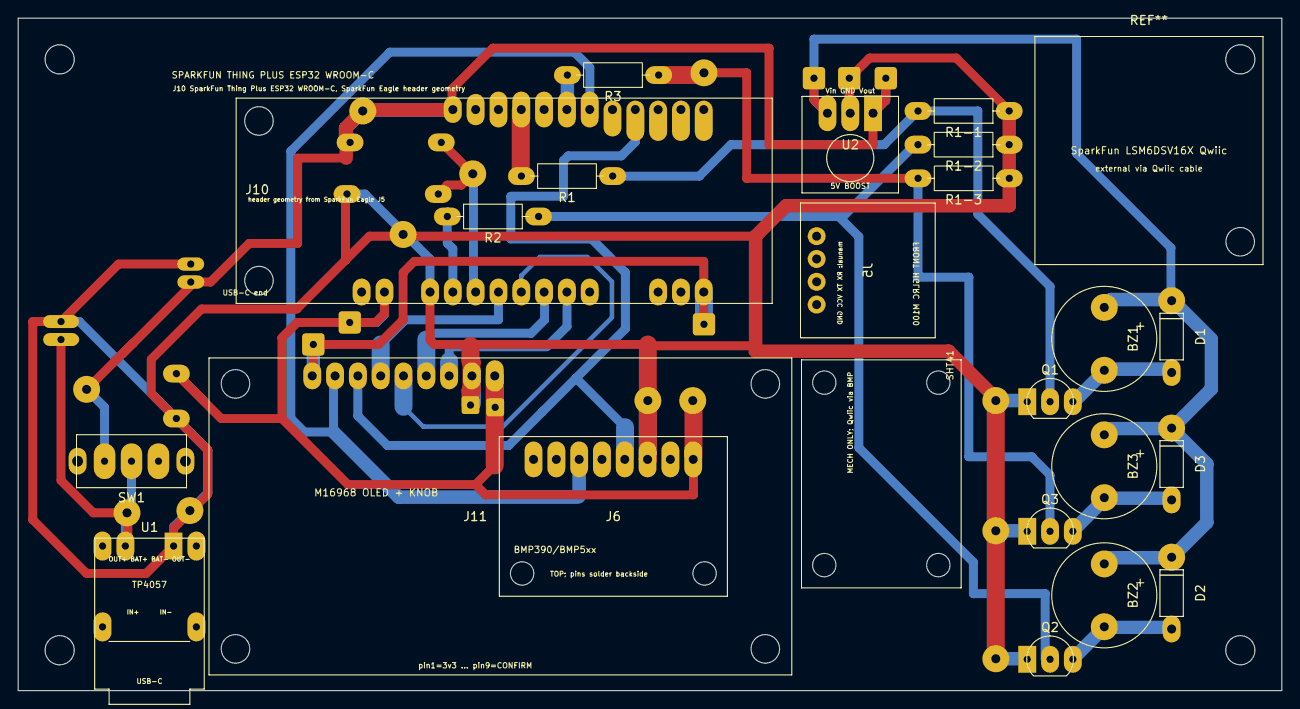
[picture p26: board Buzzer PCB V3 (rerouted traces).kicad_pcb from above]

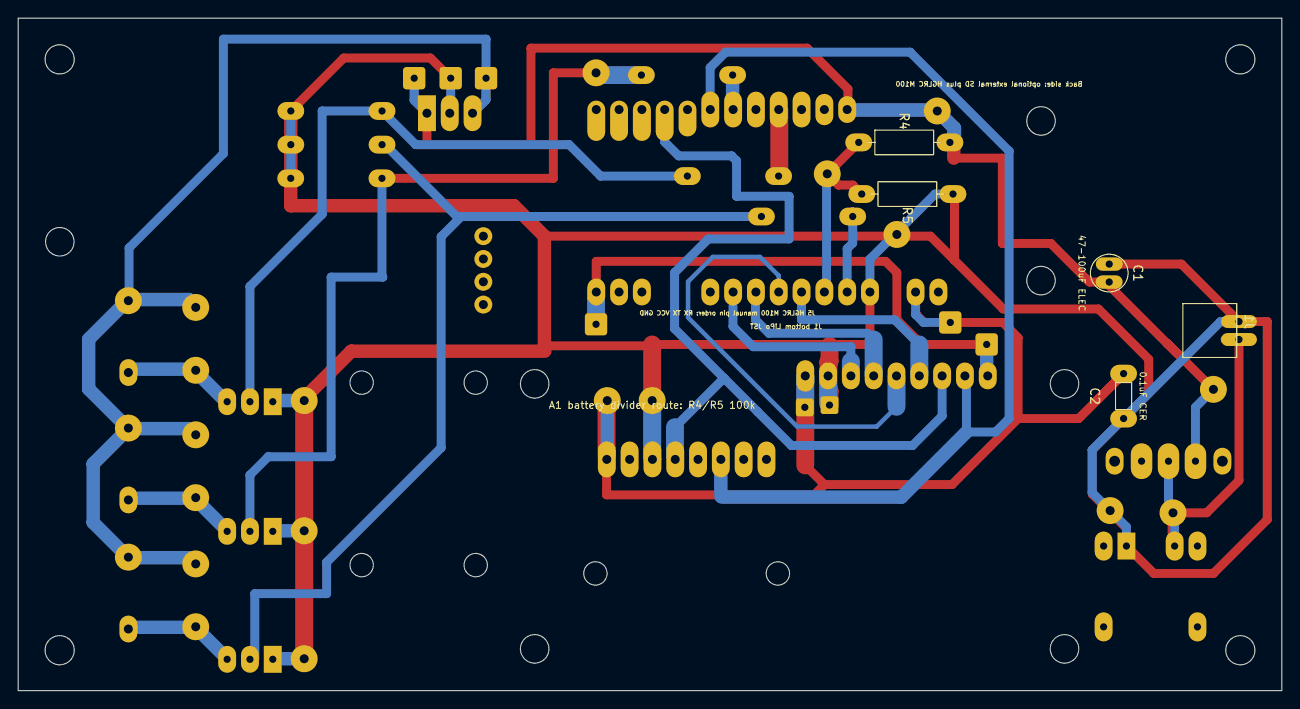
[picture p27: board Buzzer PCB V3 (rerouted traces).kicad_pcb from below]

Board: 2 copper layers, 140.7 x 74.9 mm, 32 parts (5 on the bottom side), 22 nets.

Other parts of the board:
H1, H2, H3, H4: MountingHole_3.2mm_M3
J7: SHT41 mechanical only; Adafruit_SHT41_Breakout_Top

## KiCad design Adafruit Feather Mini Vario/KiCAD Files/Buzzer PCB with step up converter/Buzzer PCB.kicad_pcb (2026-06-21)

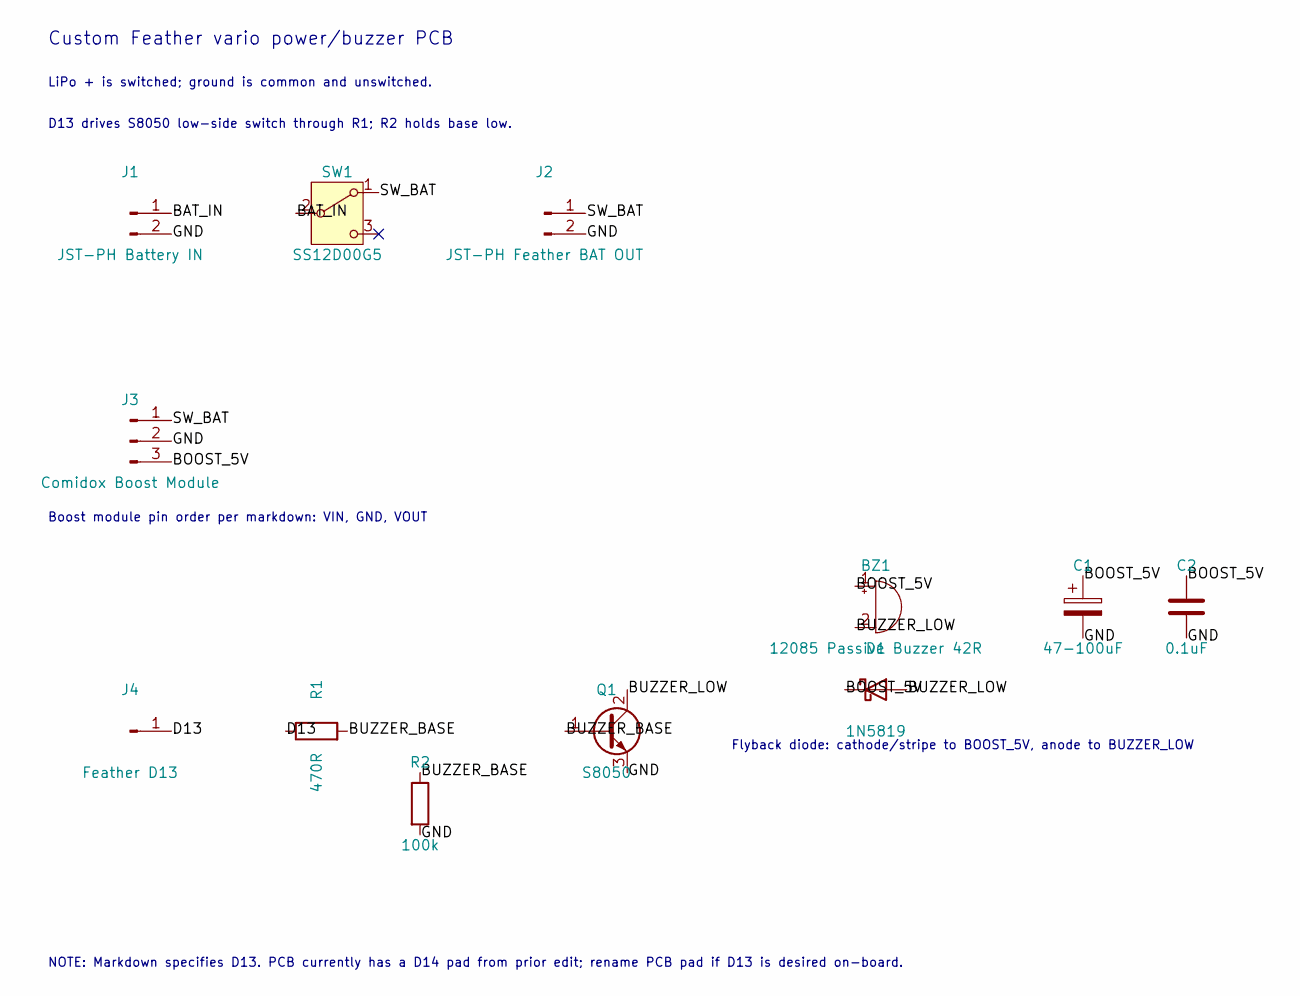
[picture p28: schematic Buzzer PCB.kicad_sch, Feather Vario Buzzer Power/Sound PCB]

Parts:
BZ1: 12085 Passive Buzzer 42R
C1: 47-100uF; CP_Radial_D5.0mm_P2.00mm
C2: 0.1uF; C_Disc_D3.0mm_W1.6mm_P2.50mm
D1: 1N5819; D_DO-41_SOD81_P10.16mm_Horizontal
J1: JST-PH Battery IN; JST_PH_S2B-PH-K_1x02_P2.00mm_Horizontal
J2: JST-PH Feather BAT OUT; JST_PH_S2B-PH-K_1x02_P2.00mm_Horizontal
J3: Comidox Boost Module; PinHeader_1x03_P2.54mm_Vertical
J4: Feather D13; PinHeader_1x01_P2.54mm_Vertical
Q1: S8050; TO-92_Inline
R1: 470R; R_Axial_DIN0207_L6.3mm_D2.5mm_P7.62mm_Horizontal
R2: 100k; R_Axial_DIN0207_L6.3mm_D2.5mm_P7.62mm_Horizontal
SW1: SS12D00G5

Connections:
BAT_IN: J1.1 (+), SW1.2 (COM)
BOOST_5V: BZ1.1 (+), C1.1 (+), C2.1 (+), D1.1 (K), J3.3 (VOUT)
BUZZER_BASE: Q1.1 (B), R1.2, R2.1
BUZZER_LOW: BZ1.2 (-), D1.2 (A), Q1.2 (C)
D13: J4.1 (Feather D13), R1.1
GND: C1.2 (-), C2.2 (-), J1.2 (-), J2.2 (-), J3.2 (GND), Q1.3 (E), R2.2
SW_BAT: J2.1 (+), J3.1 (VIN), SW1.1 (ON)

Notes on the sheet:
Boost module pin order per markdown: VIN, GND, VOUT
Flyback diode: cathode/stripe to BOOST_5V, anode to BUZZER_LOW
Custom Feather vario power/buzzer PCB
LiPo + is switched; ground is common and unswitched.
D13 drives S8050 low-side switch through R1; R2 holds base low.
NOTE: Markdown specifies D13. PCB currently has a D14 pad from prior edit; rename PCB pad if D13 is desired on-board.

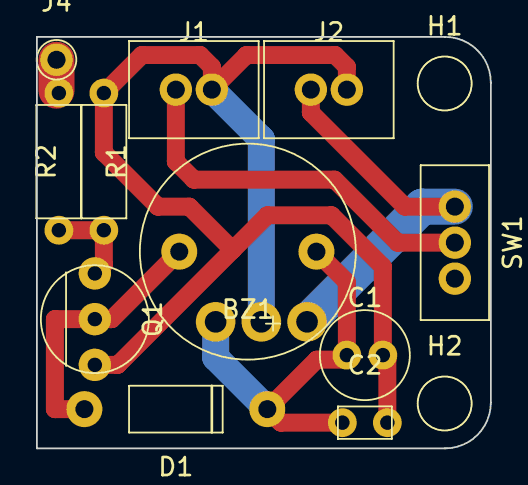
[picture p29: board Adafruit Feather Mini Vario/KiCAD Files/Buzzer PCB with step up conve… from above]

Board: 2 copper layers, 25.2 x 22.9 mm, 14 parts (1 on the bottom side), 7 nets.

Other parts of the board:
H1, H2: NPTH_3.0mm; MountingHole_3.0mm

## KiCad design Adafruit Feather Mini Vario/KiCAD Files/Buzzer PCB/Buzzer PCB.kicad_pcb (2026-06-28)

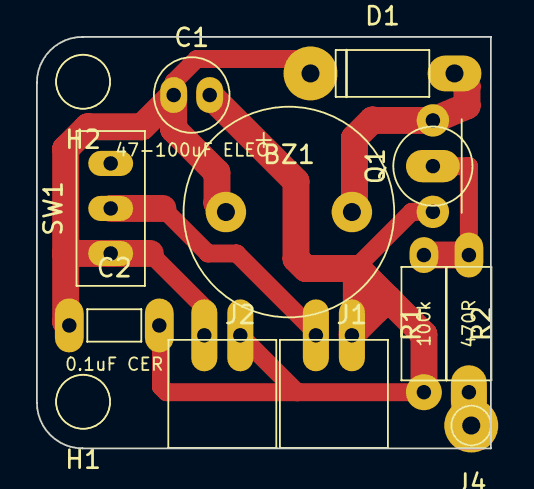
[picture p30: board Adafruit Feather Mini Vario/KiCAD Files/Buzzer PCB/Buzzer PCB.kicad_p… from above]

Board: 2 copper layers, 25.2 x 22.9 mm, 13 parts (0 on the bottom side), 6 nets.

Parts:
BZ1: 12085 Passive Buzzer 42R; Buzzer_12x8.5mm_P7.62mm_Custom
C1: 47-100uF ELEC; CP_Radial_D5.0mm_P2.00mm
C2: 0.1uF CER; C_Disc_D3.0mm_W1.6mm_P2.50mm
D1: 1N5819; D_DO-41_SOD81_P10.16mm_Horizontal
H1, H2: NPTH_3.0mm; MountingHole_3.0mm
J1: JST-PH Battery IN; JST_PH_S2B-PH-K_1x02_P2.00mm_Horizontal
J2: JST-PH Feather BAT OUT; JST_PH_S2B-PH-K_1x02_P2.00mm_Horizontal
J4: Feather D13; PinHeader_1x01_P2.54mm_Vertical
Q1: S8050; TO-92_Inline_Wide_Formed
R1: 470R; R_Axial_DIN0207_L6.3mm_D2.5mm_P7.62mm_Horizontal
R2: 100k; R_Axial_DIN0207_L6.3mm_D2.5mm_P7.62mm_Horizontal
SW1: SS12D00G5; SS12D00G5_Custom

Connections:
BAT_IN: J1.1 (+), SW1.2 (COM)
BUZZER_BASE: Q1.2 (B), R1.2, R2.1
BUZZER_LOW: BZ1.2 (-), D1.2 (A), Q1.3 (C)
D13: J4.e (Feather D13), R1.1
GND: C1.2 (-), C2.2 (-), J1.2 (-), J2.2 (-), Q1.1 (E), R2.2
SW_BAT: BZ1.1 (+), C1.1 (+), C2.1 (+), D1.1 (K), J2.1 (+), SW1.1 (ON)

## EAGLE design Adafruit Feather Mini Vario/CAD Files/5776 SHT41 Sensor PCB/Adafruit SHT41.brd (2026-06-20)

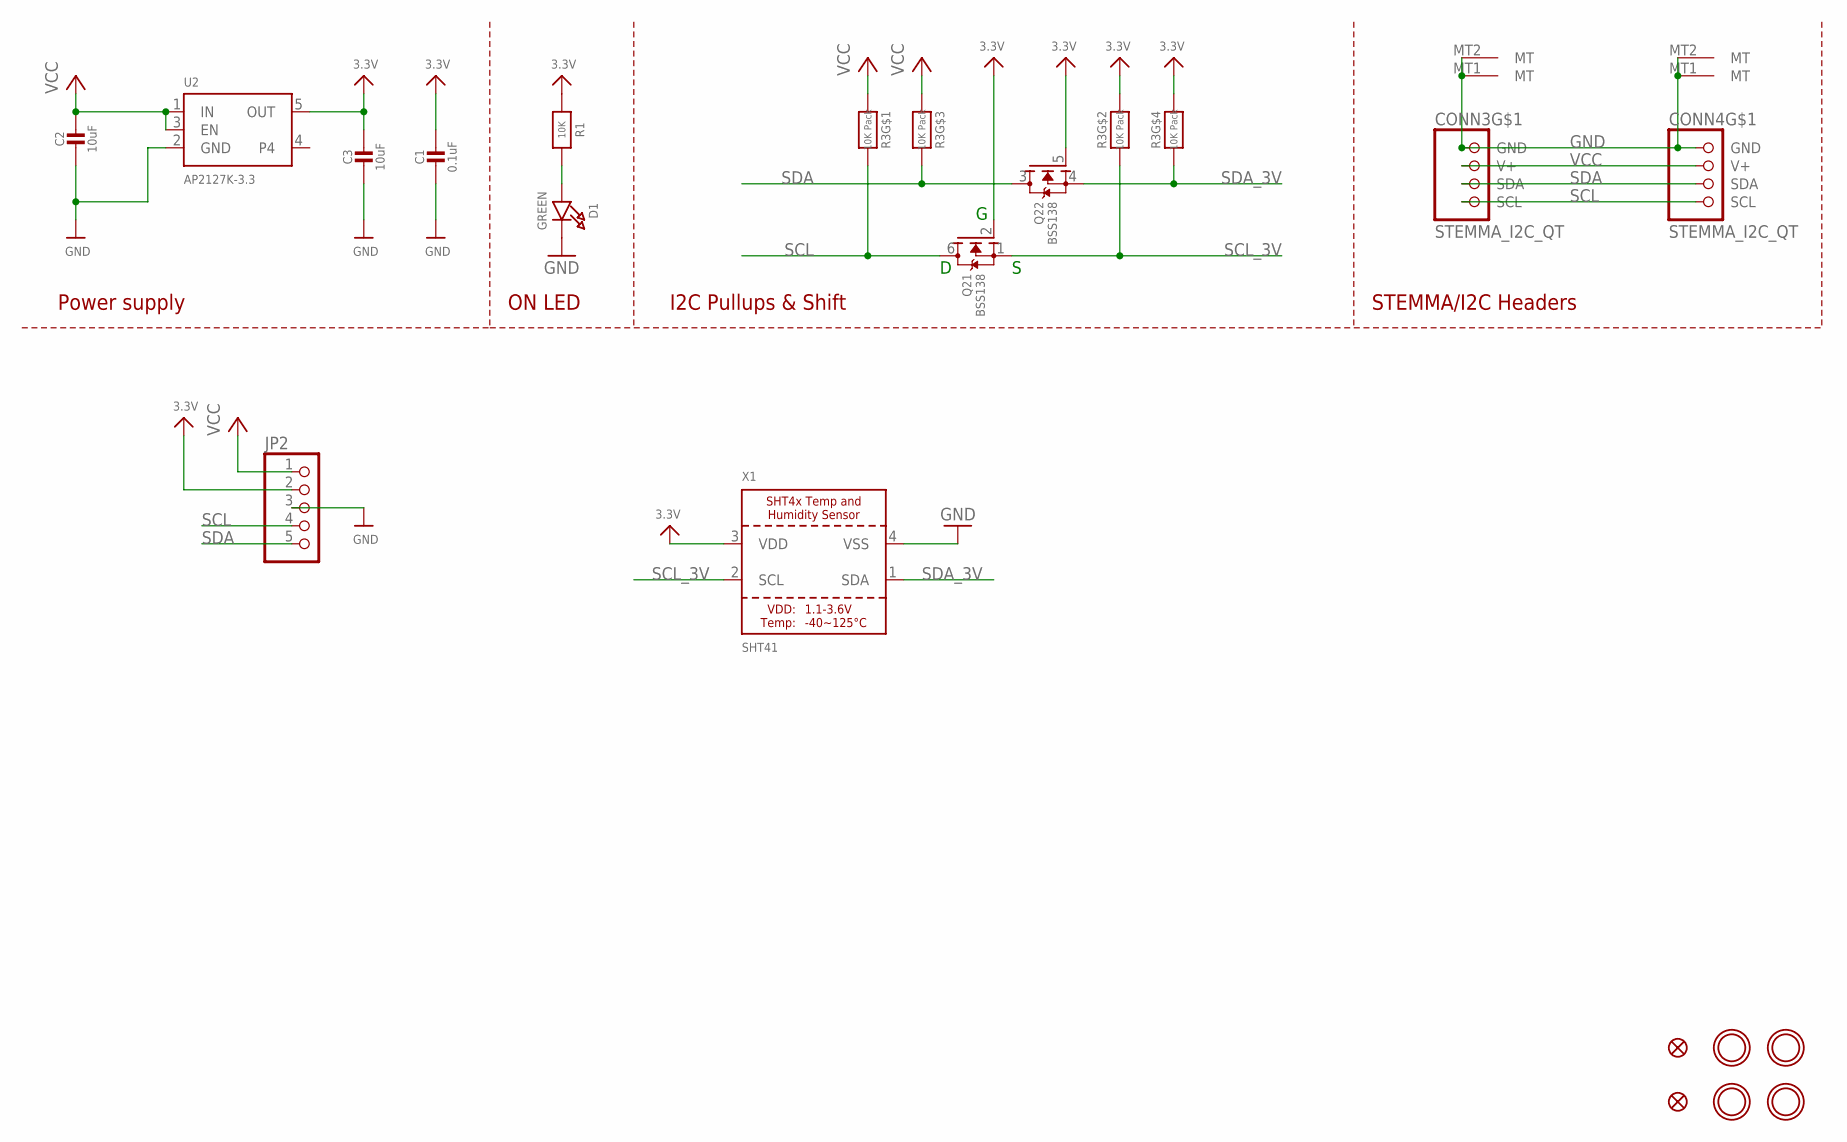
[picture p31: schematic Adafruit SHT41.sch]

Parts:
C1: 0.1uF; 0603-NO
C2, C3: 10uF; 0805-NO
CONN3, CONN4: STEMMA_I2C_QT; JST_SH4
D1: GREEN; CHIPLED_0603_NOOUTLINE
FID3, FID4: FIDUCIAL_1MM
JP2: HEADER-1X570MIL; 1X05_ROUND_70
Q2: BSS138; SOT363
R1: 10K; 0603-NO
R3: 10K Pack; RESPACK_4X0603
U2: AP2127K-3.3; SOT23-5
U$1, U$17, U$19, U$21: MOUNTINGHOLE2.5; MOUNTINGHOLE_2.5_PLATED
X1: SHT41; SHT4X

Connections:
3.3V: C1.1, C3.1, JP2.2, Q2.2 (G), Q2.5 (G), R1.1, R3.2 (1), R3.4 (1), U2.5 (OUT), X1.3 (VDD)
GND: C1.2, C2.2, C3.2, CONN3.1 (GND), CONN3.MT1 (MT), CONN3.MT2 (MT), CONN4.1 (GND), CONN4.MT1 (MT), CONN4.MT2 (MT), D1.C, JP2.3, U2.2 (GND), X1.4 (VSS)
unnamed: D1.A, R1.2
SCL: CONN3.4 (SCL), CONN4.4 (SCL), JP2.4, Q2.6 (D), R3.8 (2)
SCL_3V: Q2.1 (S), R3.7 (2), X1.2 (SCL)
SDA: CONN3.3 (SDA), CONN4.3 (SDA), JP2.5, Q2.3 (D), R3.6 (2)
SDA_3V: Q2.4 (S), R3.5 (2), X1.1 (SDA)
VCC: C2.1, CONN3.2 (V+), CONN4.2 (V+), JP2.1, R3.1, R3.3 (1), U2.1 (IN), U2.3 (EN)

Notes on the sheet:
I2C Pullups & Shift
STEMMA/I2C Headers
ON LED
Power supply

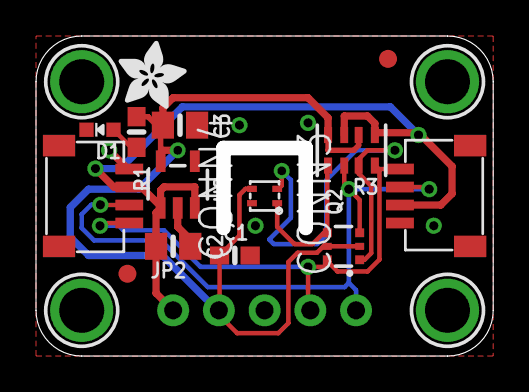
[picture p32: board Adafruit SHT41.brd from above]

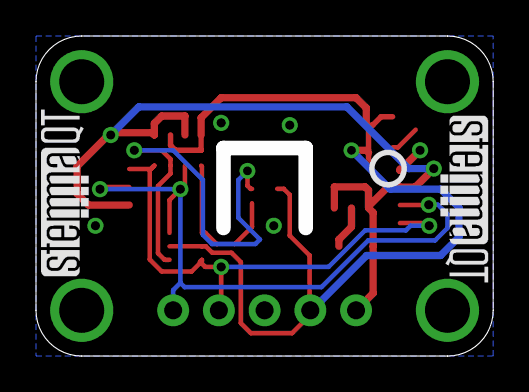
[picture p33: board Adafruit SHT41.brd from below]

Board: 2 copper layers, 25.4 x 17.8 mm, 35 parts (8 on the bottom side), 8 nets.

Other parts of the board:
PLABEL0: PLABEL0
PLABEL1: PLABEL1
PLABEL2: PLABEL2
PLABEL3: PLABEL3
PLABEL4: PLABEL4
PLABEL7: PLABEL7
PLABEL8: PLABEL8
PLABEL9: PLABEL9
PLABEL10: PLABEL10
PLABEL11: PLABEL11
PLABEL12: PLABEL12
PLABEL13: PLABEL13
PLABEL14: PLABEL14
U$22: ADAFRUIT_3.5MM
U$25: PCBFEAT-REV-040
U$30, U$31: STEMMAQT

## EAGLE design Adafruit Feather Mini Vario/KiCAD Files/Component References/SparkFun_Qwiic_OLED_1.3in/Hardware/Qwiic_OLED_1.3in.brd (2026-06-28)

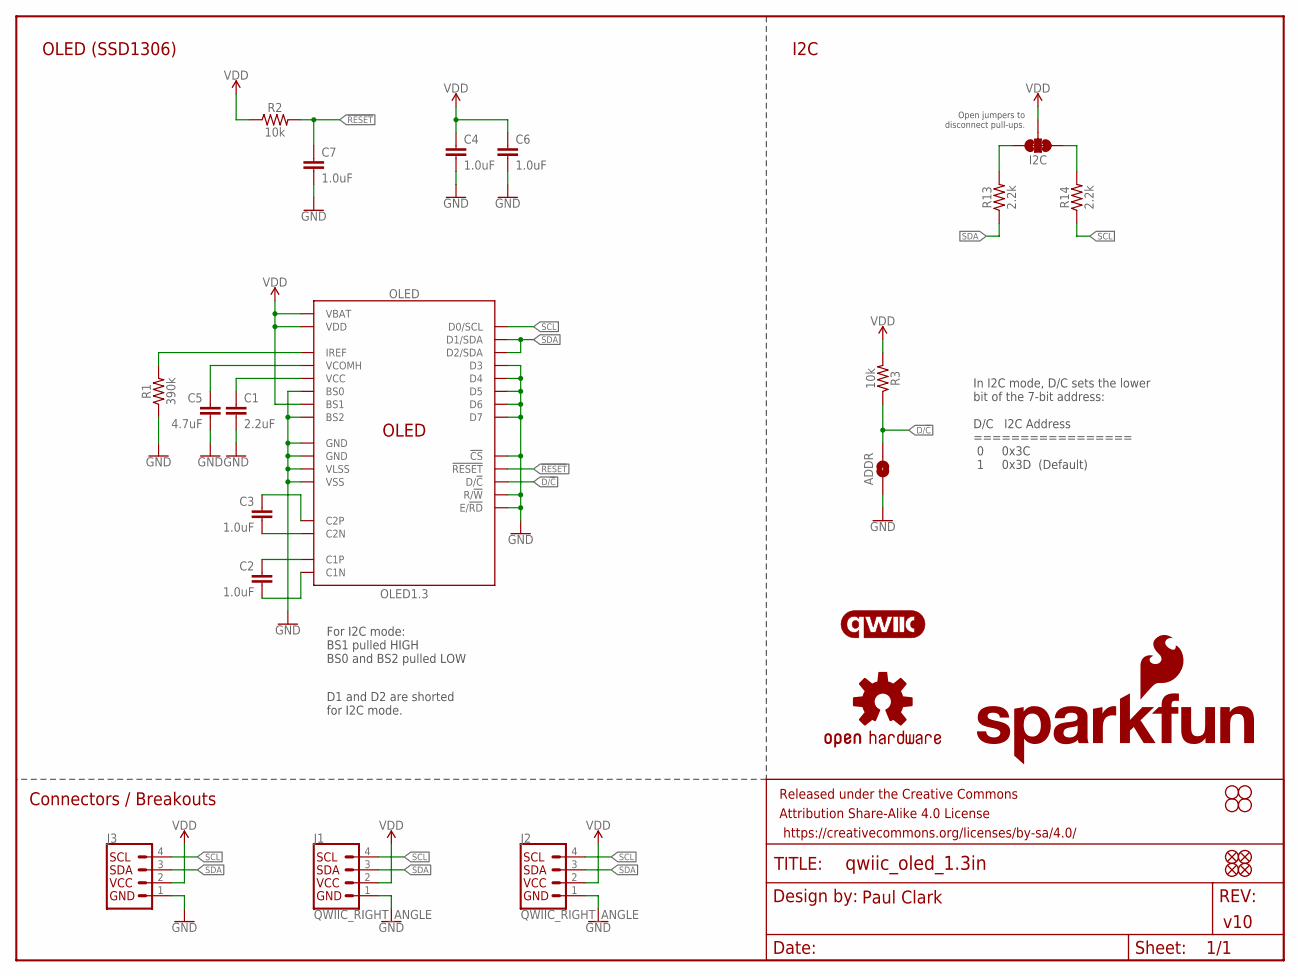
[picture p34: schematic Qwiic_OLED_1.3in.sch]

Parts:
ADDR: JUMPER-SMT_2_NO_SILK; SMT-JUMPER_2_NO_SILK
C1: 2.2uF; 0603
C2, C3, C4, C6, C7: 1.0uF; 0603
C5: 4.7uF; 0603
FID1, FID2, FID3, FID4: FIDUCIAL1X2; FIDUCIAL-1X2
FRAME1: FRAME-LETTER; CREATIVE_COMMONS
H1, H2, H3, H4: STAND-OFF
I2C: JUMPER-SMT_3_2-NC_TRACE_SILK; SMT-JUMPER_3_2-NC_TRACE_SILK
J1, J2: QWIIC_RIGHT_ANGLE; JST04_1MM_RA
J3: I2C_STANDARD_NO_SILK; 1X04_NO_SILK
LOGO1: QWIIC_LOGO_6MM; QWIIC_6MM
LOGO3: OSHW-LOGOS; OSHW-LOGO-S
LOGO4: SFE_LOGO_NAME_FLAME.1_INCH; SFE_LOGO_NAME_FLAME_.1
OLED: OLED1.3; OLED-1.3-128X64
R1: 390k; 0603
R2, R3: 10k; 0603
R13, R14: 2.2k; 0603

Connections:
!RESET!: C7.1, OLED.14 (!RESET!), R2.2
C1N: C2.2, OLED.5 (C1N)
C1P: C2.1, OLED.4 (C1P)
C2N: C3.2, OLED.3 (C2N)
C2P: C3.1, OLED.2 (C2P)
D/!C!: ADDR.2, OLED.15 (D/!C!), R3.1
GND: ADDR.1, C1.2, C4.2, C5.2, C6.2, C7.2, J1.1, J2.1, J3.1 (GND), OLED.1 (GND), OLED.8 (VSS), OLED.10 (BS0), OLED.12 (BS2), OLED.13 (!CS!), OLED.16 (R/!W!), OLED.17 (E/!RD!), OLED.21 (D3), OLED.22 (D4), OLED.23 (D5), OLED.24 (D6), OLED.25 (D7), OLED.29 (VLSS), OLED.30 (GND), R1.1
IREF: OLED.26 (IREF), R1.2
unnamed: I2C.3, R13.2
unnamed: I2C.1, R14.2
SCL: J1.4, J2.4, J3.4 (SCL), OLED.18 (D0/SCL), R14.1
SDA: J1.3, J2.3, J3.3 (SDA), OLED.19 (D1/SDA), OLED.20 (D2/SDA), R13.1
VCC: C1.1, OLED.28 (VCC)
VCOMH: C5.1, OLED.27 (VCOMH)
VDD: C4.1, C6.1, I2C.2, J1.2, J2.2, J3.2 (VCC), OLED.6 (VBAT), OLED.9 (VDD), OLED.11 (BS1), R2.1, R3.2

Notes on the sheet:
v10
D1 and D2 are shorted for I2C mode.
In I2C mode, D/C sets the lower bit of the 7-bit address: D/C I2C Address ================= 0 0x3C 1 0x3D (Default)
For I2C mode: BS1 pulled HIGH BS0 and BS2 pulled LOW
Open jumpers to disconnect pull-ups.
Paul Clark
OLED (SSD1306)
Connectors / Breakouts
I2C



Board: 2 copper layers, 35.6 x 36.8 mm, 37 parts (3 on the bottom side), 15 nets.

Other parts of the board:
U$1: QWIIC_OLED_1#3##0
U$2: #I�C#2
U$3: #3V3#2
U$4: #ADDR#5
U$5: #GND#4
U$6: #SCL#0
U$7: #SDA#1

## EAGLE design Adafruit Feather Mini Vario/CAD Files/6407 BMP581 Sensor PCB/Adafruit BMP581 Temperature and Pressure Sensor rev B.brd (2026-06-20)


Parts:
C4, C5: 10uF; 0805-NO
C6: 0.1uF; 0603-NO
CONN3, CONN4: STEMMA_I2C_QT; JST_SH4
D1: GREEN; CHIPLED_0603_NOOUTLINE
D2: 1N4148; SOD-323
FID3, FID4: FIDUCIAL_1MM
IC1: BMP581; BMP388
JP1: HEADER-1X870MIL; 1X08_ROUND_70
Q2: BSS138; SOT363
R1, R4, R5: 10K; 0603-NO
R2: 10K Pack; RESPACK_4X0603
SJ1: SOLDERJUMPER; SOLDERJUMPER_ARROW_NOPASTE
U1: AP2127K-3.3; SOT23-5
U$40, U$41: MOUNTINGHOLE2.5; MOUNTINGHOLE_2.5_PLATED

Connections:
3.3V: C5.1, C6.1, IC1.1 (VDDIO), IC1.10 (VDD), JP1.2, Q2.2 (G), Q2.5 (G), R1.2, R2.2 (1), R2.4 (1), R4.2, R5.1, U1.5 (OUT)
CS: D2.C, JP1.7
CS_3V: D2.A, IC1.6 (CSB), R1.1
GND: C4.2, C5.2, C6.2, CONN3.1 (GND), CONN3.MT1 (MT), CONN3.MT2 (MT), CONN4.1 (GND), CONN4.MT1 (MT), CONN4.MT2 (MT), D1.C, IC1.3 (GND), IC1.8 (GND), IC1.9 (GND), JP1.3, SJ1.2, U1.2 (GND)
INT: IC1.7 (INT), JP1.8
unnamed: D1.A, R5.2
SCK/SCL: CONN3.4 (SCL), CONN4.4 (SCL), JP1.4, Q2.6 (D), R2.8 (2)
SCK_3V: IC1.2 (SCK), Q2.1 (S), R2.7 (2)
SDI/SDA: CONN3.3 (SDA), CONN4.3 (SDA), JP1.6, Q2.3 (D), R2.6 (2)
SDI_3V: IC1.4 (SDI), Q2.4 (S), R2.5 (2)
SDO/ADR: IC1.5 (SDO), JP1.5, R4.1, SJ1.1
VCC: C4.1, CONN3.2 (V+), CONN4.2 (V+), JP1.1, R2.1, R2.3 (1), U1.1 (IN), U1.3 (EN)

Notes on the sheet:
I2C Pullups & Shift
STEMMA/I2C Headers
ON LED
Power supply
For SPI set CSB low at startup SDO=MISO, SDI=MOSI, SCK=SCK, CSB=CS/SSEL
For I2C leave CSB pulled high (default value) SDI=SDA, SCK=SCL
LEVEL SHIFTING (5V <--> 3V)



Board: 2 copper layers, 25.4 x 17.8 mm, 40 parts (11 on the bottom side), 12 nets.

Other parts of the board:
PLABEL14: PLABEL14
PLABEL15: PLABEL15
PLABEL16: PLABEL16
PLABEL17: PLABEL17
PLABEL18: PLABEL18
PLABEL19: PLABEL19
PLABEL20: PLABEL20
PLABEL21: PLABEL21
PLABEL23: PLABEL23
PLABEL24: PLABEL24
PLABEL26: PLABEL26
PLABEL27: PLABEL27
PLABEL28: PLABEL28
PLABEL29: PLABEL29
U$1: GND; ADAFRUIT_2.5MM
U$2: ADAFRUIT_2.5MM
U$46: ADAFRUIT_3.5MM
U$47: PCBFEAT-REV-040
U$48, U$49: STEMMAQT

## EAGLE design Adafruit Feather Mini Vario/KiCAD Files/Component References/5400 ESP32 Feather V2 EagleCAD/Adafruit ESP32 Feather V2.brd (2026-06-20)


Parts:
C1, C2, C13: 10uF; 0805-NO
C3, C6, C7, C8: 10µF; 0805-NO
C4, C5, C9, C10: 1uF; 0603-NO
C11, C12: 0.1uF; 0603-NO
CHG: ORANGE; CHIPLED_0603_NOOUTLINE
CONN1: STEMMA_I2C_QTRA; JST_SH4_RA
D3: RED; CHIPLED_0603_NOOUTLINE
D4: MBR540; SOD-123
D+1: TPB1,27; B1,27
D-1: TPB1,27; B1,27
IC3: CP2102N-24; QFN24_4MM_SMSC
JP1: HEADER-1X16ROUND; 1X16_ROUND
JP3: HEADER-1X12; 1X12_ROUND
LED1: WS2812B3535; LED3535
Q3: DMG3415U; SOT23-R
Q5: DUAL NPN; SOT363
R1, R3: 200K; 0603-NO
R2, R4, R5, R6, R10: 5.1K; 0603-NO
R7, R12: 100K; 0603-NO
R9: 47K; RESPACK_4X0603
R13: 10K; RESPACK_4X0603
SW1, SW2: KMR2; BTN_KMR2_4.6X2.8
U1, U2: AP2112-3.3; SOT23-5
U3: MCP73831T-2ACI/OT; SOT23-5
U$31, U$32: MOUNTINGHOLE2.5; MOUNTINGHOLE_2.5_PLATED
U$34, U$35: FIDUCIAL_1MM
X1: JSTPH; JSTPH2_BATT
X3: ESP32-PICO-MINI-02MINI; ESP32-PICO-MINI
X6: USB Type C; USB_C_CUSB31-CFM2AX-01-X

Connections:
3.3V: C1.1, C2.1, C8.1, C9.1, C13.1, JP1.15, R9.5 (2), R13.1, U2.5 (OUT), X3.3 (3.3V)
3.45V: C10.1, C12.1, IC3.5 (VIO), IC3.6 (VDD)
!RESET: C4.1, JP1.16, Q5.3 (D), R13.8 (2), SW2.B (S), SW2.B' (S1), X3.8 (EN)
A0_DAC2: JP1.12, X3.16 (IO26/DAC2/A2_9)
A1_DAC1: JP1.11, X3.15 (IO25/DAC1/A2_8)
A2_I34: JP1.10, X3.9 (I34/A1_6)
A3_I39: JP1.9, X3.7 (I39/A1_3)
A4_I36: JP1.8, X3.4 (I36/A1_0)
A5_IO4: JP1.7, X3.24 (IO4/A2_0)
A13_I35: C5.1, R1.1, R3.2, X3.10 (I35/A1_7)
CC1: R6.2, X6.A5 (CC1)
CC2: R5.2, X6.B5 (CC2)
D+: D+1.TP, IC3.3 (D+), X6.A6 (D+), X6.B6 (D+)
D-: D-1.TP, IC3.4 (D-), X6.A7 (D-), X6.B7 (D-)
DTR: IC3.23 (DTR), Q5.1 (S), R13.3 (1)
EN: JP3.2, R7.1, U2.3 (EN)
GND: C1.2, C2.2, C3.2, C4.2, C5.2, C6.2, C7.2, C8.2, C9.2, C10.2, C11.2, C12.2, C13.2, CONN1.1 (GND), CONN1.MT1 (MT), CONN1.MT2 (MT), D3.C, IC3.2 (GND), IC3.THERM (GND), JP1.13, LED1.4 (GND), R3.1, R4.1, R5.1, R6.1, R9.3 (1), R12.1, R13.5 (2), SW1.A, SW1.A' (P1), SW2.A, SW2.A' (P1), U1.2 (GND), U2.2 (GND), U3.2 (VSS), X1.1, X1.NC1, X1.NC2, X3.1 (GND), X3.2 (GND), X3.11 (GND), X3.14 (GND), X3.36 (GND), X3.37 (GND), X3.38 (GND), X3.39 (GND), X3.40 (GND), X3.41 (GND), X3.42 (GND), X3.43 (GND), X3.44 (GND), X3.45 (GND), X3.46 (GND), X3.47 (GND), X3.48 (GND), X3.49 (GND), X3.50 (GND), X3.51 (GND), X3.52 (GND), X3.53 (GND), X3.54 (GND), X3.55 (GND), X3.56 (GND), X3.57 (GND), X3.58 (GND), X3.59 (GND), X3.60 (GND), X3.61 (GND), X6.A1B12 (GND), X6.B1A12 (GND)
GPIO0: LED1.1 (DI), Q5.6 (D), X3.23 (IO0/A2_1)
I37: JP1.1, X3.5 (I37/A1_1)
IO12_A11: JP3.5, X3.19 (IO12/A2_5)
IO13_A12: JP3.4, R10.1, X3.20 (IO13/A2_4)
IO14_A6: JP3.10, X3.18 (IO14/A2_6)
IO15_A8: JP3.8, X3.21 (IO15/A2_3)
IO27_A10: JP3.6, X3.17 (IO27/A2_7)
IO32_A7: JP3.9, X3.12 (IO32/A1_4/X32P)
IO33_A9: JP3.7, X3.13 (IO33/A1_5/X32N)
MISO: JP1.4, X3.35 (IO21)
MOSI: JP1.5, X3.33 (IO19)
unnamed: CHG.C, R2.1
unnamed: R2.2, U3.1 (STAT)
unnamed: R4.2, U3.5 (PROG)
unnamed: D3.A, R10.2
unnamed: R9.4 (1), SW1.B (S), SW1.B' (S1), X3.6 (I38/A1_2)
unnamed: Q5.5 (G), R13.6 (2)
unnamed: Q5.2 (G), R13.2 (1)
NEOI2C_PWR: R13.4 (1), U1.3 (EN), X3.22 (IO2/A2_2)
RTS: IC3.19 (RTS), Q5.4 (S), R13.7 (2)
RX/IO7: JP1.3, X3.27 (IO7)
RXD0: IC3.21 (TXD), X3.30 (RXD0)
SCK: JP1.6, X3.29 (IO5)
SCL: CONN1.4 (SCL), JP3.11, X3.26 (IO20)
SDA: CONN1.3 (SDA), JP3.12, X3.34 (IO22)
TX/IO8: JP1.2, X3.28 (IO8)
TXD0: IC3.20 (RXD), X3.31 (TXD0)
VBAT: C3.1, JP3.1, Q3.3 (D), R1.2, U3.3 (VBAT), X1.2
VBUS: C11.1, CHG.A, D4.A, IC3.7 (REGIN), JP3.3, Q3.1 (G), R9.7 (2), R9.8 (2), R12.2, U3.4 (VDD), X6.A4B9 (VBUS), X6.B4A9 (VBUS)
VBUS_DET: IC3.8 (VBUS), R9.1, R9.2 (1), R9.6 (2)
VHI: C6.1, D4.C, Q3.2 (S), R7.2, U1.1 (IN), U2.1 (IN)
V_NEOI2C: C7.1, CONN1.2 (V+), LED1.2 (VDD), U1.5 (OUT)

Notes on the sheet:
POWER AND FILTERING
RESET
10K = 100mA
5.0K = 200mA
2.0K = 500mA
1.0K = 1000mA
USB TO SERIAL CONVERTER
LIPO CHARGING
LED
ESP32 PICO MODULE
LIPO MONITOR
HEADERS
STEMMA QT & SECOND LDO
USB TYPE C
AUTORESET
NEOPIXEL



Board: 2 copper layers, 50.8 x 22.9 mm, 54 parts (6 on the bottom side), 49 nets.

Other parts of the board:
U$7: ADAFRUIT_5MM
U$9: FEATHERLOGO_MED
U$13: PCBFEAT-REV-040
U$14: ADAFRUIT_2.5MM
U$15: ADAFRUIT_3.5MM
U$43: HUZZAH32

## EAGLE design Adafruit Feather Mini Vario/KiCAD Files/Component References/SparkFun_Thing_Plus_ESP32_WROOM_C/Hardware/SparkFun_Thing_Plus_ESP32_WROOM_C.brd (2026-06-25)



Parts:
C1, C4: 10uF; 0402-TIGHT
C2, C5, C15: 0.1uF; 0402-TIGHT
C3, C7, C10: 1.0uF; 0402-TIGHT
C6: 4.7uF; 0402-TIGHT
C19: 4.7uF; 0603
D1: Yellow; LED-0603
D3: BLUE; LED-0603
D4: 3A/10V/280mV; SOD-323
D5: WS2812; WS2812-2020
D12: RED; LED-0603
FD1, FD2, FD3, FD4: FIDUCIALUFIDUCIAL; FIDUCIAL-MICRO
FRAME1: FRAME-LEDGER; CREATIVE_COMMONS
H1, H2: STAND-OFFTIGHT; STAND-OFF-TIGHT
J1: USB_C_2-LAYER_PADS; USB-C-16P-2LAYER-PADS
J2: MICRO-SDFRICTION; MICROSD_TINY
J3: QWIIC_RA; JST04_1MM_RA
J4: JST_2MM_MALE; JST-2-SMD
J5: THING_PLUS_LOGICAL; THING_PLUS
JP1, JP2, JP3: JUMPER-SMT_2_NC_TRACE_SILK; SMT-JUMPER_2_NC_TRACE_SILK
LOGO1: SFE_LOGO_NAME_FLAME.1_INCH; SFE_LOGO_NAME_FLAME_.1
LOGO2: OSHW-LOGOMINI; OSHW-LOGO-MINI
LOGO4: QWIIC_LOGO_4MM; QWIIC_4MM
Q2: MBT3904DW1T1; SC70-6
Q3: 20V/4.2A/52mΩ/1.4W; SOT23-3
R2, R7, R8, R17, R18: 10k; 0402-TIGHT
R3, R4, R34: 1k; 0402-TIGHT
R6: 2.0k; 0603
R9, R10: 5.1k; 0402-TIGHT
S3: Boot; TACTILE_SWITCH_SMD_4.6X2.8MM
S4: Reset; TACTILE_SWITCH_SMD_4.6X2.8MM
TP1, TP2, TP3, TP4: TEST-POINT3X5; PAD.03X.05
U1: MCP73831; SOT23-5
U2: ESP-WROOM-3232D-NARROW; ESP-WROOM-32D-NARROW
U3, U5: 3.3V; SOT23-5
U4: MAX17048; DFN-8
U7: CH340C; SO016

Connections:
3.3V: C1.1, C2.1, C4.1, C5.1, C10.1, D5.VCC, J2.4 (VCC), J5.27 (3.3V), JP1.2, R2.2, U2.2 (3V3), U3.5 (OUT), U7.4 (V3), U7.16 (VCC)
!RESET!: J5.28 (!RESET), Q2.3 (C), R2.1, S4.3 (2), S4.4 (2), U2.3 (EN)
CH340-DTR: Q2.1 (E), R17.1, U7.13 (!DTR)
CH340-RTS: Q2.4 (E), R18.1, U7.14 (!RTS)
CH340-RX: U2.35 (TX-IO1), U7.3 (RXI)
CH340-TX: U2.34 (RX-IO3), U7.2 (TXO)
CHG_LED: D1.A, R3.2
D+: J1.A6 (D+), J1.B6 (D+), U7.5 (UD+)
D-: J1.A7 (D-), J1.B7 (D-), U7.6 (UD-)
DTR-10K: Q2.5 (B), R17.2
ESP_0/QPWR: Q2.6 (C), S3.3 (2), S3.4 (2), TP1.1, U2.25 (IOA0), U5.3 (EN)
ESP_2/RGB_DI: D5.DI, TP3.1, U2.24 (IOA2)
ESP_4/TP_FB: J5.13 (FREEBIE), U2.26 (IOA4)
ESP_5/SD_CS: J2.2 (DAT3/!CS!), TP4.1, U2.29 (CS3/IO5)
ESP_12/GPIO1: J5.8 (GPIO1), U2.14 (POCI2/IOA12)
ESP_13/GPIO0/LED: J5.9 (GPIO0), R4.1, U2.16 (PICO2/IOA13)
ESP_14/GPIO6: J5.3 (GPIO6), U2.13 (SCK2/IOA14)
ESP_15/GPIO4: J5.5 (GPIO4), U2.23 (CS2/IOA15)
ESP_16/TP_RX: J5.15 (RX), U2.27 (IO16)
ESP_17/TP_TX: J5.14 (TX), U2.28 (IO17)
ESP_18/TP_SCK: J2.5 (CLK/SCK), J5.18 (SCK), U2.30 (SCK3/IO18)
ESP_19/TP_POCI: J2.7 (DAT0/SDO), J5.16 (POCI), U2.31 (POCI3/IO19)
ESP_21/TP_SDA: J3.3, J5.1 (SDA), U2.33 (SDA/IO21), U4.8 (SDA)
ESP_22/TP_SCL: J3.4, J5.2 (SCL), U2.36 (SCL/IO22), U4.7 (SCL)
ESP_23/TP_PICO: J2.3 (CMD/SDI), J5.17 (PICO), U2.37 (PICO3/IO23)
ESP_25/TP_A1: J5.23 (A1), U2.10 (DAC1/IOA25)
ESP_26/TP_A0: J5.24 (A0), U2.11 (DAC2/IOA26)
ESP_27/GPIO2: J5.7 (GPIO2), U2.12 (IOA27)
ESP_32/GPIO5: J5.4 (GPIO5), U2.8 (XTAL_P/IOA32)
ESP_33/GPIO3: J5.6 (GPIO3), U2.9 (XTAL_N/IOA33)
ESP_34/TP_A2: J5.22 (A2), U2.6 (IA34)
ESP_35/TP_A5: J5.19 (A5), U2.7 (IA35)
ESP_36/TP_A4: J5.20 (A4), U2.4 (SENSOR_VP/IA36)
ESP_39/TP_A3: J5.21 (A3), U2.5 (SENSOR_VN/IA39)
GND: C1.2, C2.2, C3.2, C4.2, C5.2, C6.2, C7.2, C10.2, C15.2, C19.2, D3.C, D5.GND, D12.C, J1.GND, J1.GND2 (GND), J2.6 (GND), J2.GND1 (GND), J2.GND2 (GND), J2.GND3 (GND), J2.GND4 (GND), J2.GND5 (GND), J2.GND6 (GND), J3.1, J4.1 (-), J5.25 (GND), JP3.1, R6.1, R7.1, R9.1, R10.1, S3.1, S3.2 (1), S4.1, S4.2 (1), U1.2 (VSS), U2.1 (GND), U2.15 (GND), U2.38 (GND), U2.GND1 (GND), U2.GNDT1 (GND), U2.GNDT2 (GND), U2.GNDT3 (GND), U2.GNDT4 (GND), U2.GNDT5 (GND), U2.GNDT6 (GND), U2.GNDT7 (GND), U2.GNDT8 (GND), U3.2 (GND), U4.1 (CTG), U4.4 (GND), U4.6 (QSTRT), U4.9 (GND), U5.2 (GND), U7.1 (GND)
unnamed: JP1.1, R34.1
unnamed: D3.A, R4.2
unnamed: D5.DO, TP2.1
unnamed: JP2.1, R3.1
unnamed: J1.B5 (CC2), R9.2
unnamed: J1.A5 (CC1), R10.2
unnamed: D1.C, U1.1 (STAT)
unnamed: J1.SHLD1 (SHLD), J1.SHLD2 (SHLD), J1.SHLD3 (SHLD), J1.SHLD4 (SHLD), JP3.2
unnamed: R6.2, U1.5 (PROG)
unnamed: D12.A, R34.2
QWIIC_PWR: C3.1, J3.2, U5.5 (OUT)
RTS-10K: Q2.2 (B), R18.2
TP_EN: J5.11 (EN), R8.2, U3.3 (EN)
VIN: C7.1, D4.C, Q3.2 (S), R8.1, U3.1 (IN), U5.1 (IN)
V_BATT: C6.1, C15.1, J4.2 (+), J5.12 (V_BATT), Q3.3 (D), U1.3 (VBAT), U4.2 (CELL), U4.3 (VDD)
V_USB: C19.1, D4.A, J1.VBUS1 (VBUS), J1.VBUS2 (VBUS), J5.10 (V_USB), JP2.2, Q3.1 (G), R7.2, U1.4 (VIN)

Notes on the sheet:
USB-to-Serial Converter
Single-cell LiPo battery
Charge current: I_CHG = 1000 / R_PROG R_PROG=2k : I_CHG=500mA
System Regulator
Lithium-Polymer Battery Charger
600mA out 6V max in
Auto-Reset
Espressif ESP32-WROOM
Reset Button
ThingPlus Form Factor
v40
If DTR is LOW, toggling RTS from HIGH to LOW resets to run mode. If RTS is HIGH, toggling DTR from LOW to HIGH resets to bootloader.
Qwiic Connector
Status LED
GPIO0/Boot Button
V_USB - 6V MAX V_BATT - Single Cell (4.2V MAX)
Pin
IO0
IO2
IO12
IO15
IO5
Run
Bootloader
Default
IO12 = MDTI, IO15 = MDTO
Boot Mode Configuration
IO0: Avoid device connections. Can be used a stat LED.
ADC2 is unavailable when WiFi is enabled.
IO12: Avoid external pullups - will cause bootloader fail.
Use boot control pins with caution: 0, 2, 5, 12, 15
IO2: Avoid external pullups - will cause bootloader fail.
Fuel Gauge
600mA out
RGB Status LED
microSD Connector
IO15: Has builtin pullup at POR.
IO5: Has builtin pullup at POR.
Cut trace to disconnect CHG LED.
Cut trace to disconnect PWR LED.



Board: 2 copper layers, 22.9 x 59.7 mm, 110 parts (46 on the bottom side), 51 nets.

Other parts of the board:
U$1: SFE_LOGO_FLAME_STOP_.1
U$2: #23#PICO#0
U$3: #19#POCI#0
U$4: #4#FREE#0
U$5: #CHG_LED#0
U$6: ESP32#WROOM0
U$7: THING_PLUS_C0
U$8: #SHLD#0
U$9: #_GND#0
U$10: #_NC#0
U$11: #_3V3#0
U$12: SFE_LOGO_FLAME_.1
U$23: 3V30
U$24: CHG1
U$25: PWR2
U$26: STAT0
U$68: A03
U$69: A12
U$70: A21
U$71: A30
U$72: #17#TX#0
U$73: VB1
U$74: EN3
U$75: GND1
U$76: VU0
U$77: 130
U$78: BOOT0
U$79, U$109: #RST#0
U$80: RST0
U$81: #16#RX#0
U$83: #18#SCK#0
U$84: #35#A5#0
U$85: #36#A4#0
U$86: #25#A1#2
U$87: #26#A0#3
U$88: #34#A2#1
U$89: #39#A3#0
U$90: #12#4
U$91: #14#9
U$92: #15#7
U$93: #27#5
U$94: #32#8
U$95: #33#6
U$96: #EN#1
U$97: #VBAT#0
U$98: #VUSB#2
U$99: #13#LED#0
U$100: #21#SDA#1
U$101: #22#SCL#0
U$102: #PWR#0
U$107: NC0

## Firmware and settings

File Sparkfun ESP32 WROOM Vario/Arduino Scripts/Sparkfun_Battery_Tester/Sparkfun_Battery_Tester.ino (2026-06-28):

#include <Adafruit_GFX.h>
#include <Adafruit_SH110X.h>
#include <ESPmDNS.h>
#include <Preferences.h>
#include <SD.h>
#include <SPI.h>
#include <SparkFun_MAX1704x_Fuel_Gauge_Arduino_Library.h>
#include <Update.h>
#include <WebServer.h>
#include <WiFi.h>
#include <Wire.h>

constexpr uint8_t kQwiicPowerPin = 0;
constexpr uint8_t kSdCsPin = 5;
constexpr uint8_t kSdSckPin = 18;
constexpr uint8_t kSdMisoPin = 19;
constexpr uint8_t kSdMosiPin = 23;
constexpr uint8_t kOledSdaPin = 33;
constexpr uint8_t kOledSclPin = 32;
constexpr uint8_t kEncoderAPin = 39;
constexpr uint8_t kEncoderBPin = 36;
constexpr uint8_t kBackButtonPin = 35;
constexpr uint8_t kEncoderButtonPin = 34;
constexpr uint8_t kConfirmButtonPin = 4;
constexpr int8_t kOledResetPin = -1;
constexpr uint8_t kOledAddress = 0x3C;
constexpr uint16_t kOledWidth = 128;
constexpr uint16_t kOledHeight = 64;
constexpr uint32_t kBatteryReadMs = 1000;
constexpr uint8_t kMaxWifiNetworks = 6;
constexpr uint8_t kLogRateCount = 10;
constexpr uint32_t kLogRatesMs[kLogRateCount] = {
    100, 200, 500, 1000, 2000, 5000, 10000, 30000, 60000, 120000};
constexpr const char *kLogRateLabels[kLogRateCount] = {
    "10 Hz", "5 Hz", "2 Hz", "1 Hz", "0.5 Hz", "5 sec", "10 sec", "30 sec", "60 sec", "2 min"};
constexpr const char *kHostname = "sparkfun-vario";
constexpr const char *kFallbackApSsid = "SparkFun-Battery-Test";
constexpr const char *kPrefsNamespace = "vario";
constexpr const char *kLogPath = "/battery_test.csv";

struct StoredWifiNetwork {
  String ssid;
  String password;
};

TwoWire oledWire(1);
Adafruit_SH1106G oled(kOledWidth, kOledHeight, &oledWire, kOledResetPin);
Preferences prefs;
SFE_MAX1704X fuelGauge(MAX1704X_MAX17048);
WebServer server(80);

StoredWifiNetwork wifiNetworks[kMaxWifiNetworks];
uint8_t wifiNetworkCount = 0;
bool oledReady = false;
bool oledEnabled = true;
bool sdReady = false;
bool gaugeReady = false;
bool loggingActive = true;
bool bluetoothEnabled = false;
bool webReady = false;
bool apMode = false;
bool wifiOffRequested = false;
bool wifiManuallyOff = false;
uint8_t logRateIndex = 7;
uint32_t pendingWifiOffAtMs = 0;
uint32_t startMs = 0;
uint32_t lastBatteryReadMs = 0;
uint32_t lastLogMs = 0;
float batteryVoltage = NAN;
float batteryPercent = NAN;
String connectedSsid;
String defaultI2cDevices;
String oledI2cDevices;
String gaugeBus = "none";

String wifiKey(const char *prefix, uint8_t index) {
  return String(prefix) + String(index);
}

String htmlEscape(const String &value) {
  String out;
  out.reserve(value.length());
  for (size_t i = 0; i < value.length(); i++) {
    const char c = value[i];
    if (c == '&') out += F("&amp;");
    else if (c == '<') out += F("&lt;");
    else if (c == '>') out += F("&gt;");
    else if (c == '"') out += F("&quot;");
    else out += c;
  }
  return out;
}

String jsonEscape(const String &value) {
  String out;
  out.reserve(value.length() + 4);
  for (size_t i = 0; i < value.length(); i++) {
    const char c = value[i];
    if (c == '\\' || c == '"') {
      out += '\\';
      out += c;
    } else if (c == '\n') {
      out += F("\\n");
    } else if (c == '\r') {
      out += F("\\r");
    } else {
      out += c;
    }
  }
  return out;
}

String floatJson(float value, uint8_t decimals) {
  if (isnan(value)) {
    return F("null");
  }
  return String(value, static_cast<unsigned int>(decimals));
}

String scanI2cBus(TwoWire &bus) {
  String found;
  for (uint8_t address = 1; address < 127; address++) {
    bus.beginTransmission(address);
    if (bus.endTransmission() == 0) {
      if (found.length()) {
        found += ' ';
      }
      if (address < 16) {
        found += '0';
      }
      found += String(address, HEX);
    }
    delay(1);
  }
  found.toUpperCase();
  return found.length() ? found : String("none");
}

String stopwatch() {
  const uint32_t elapsed = (millis() - startMs) / 1000UL;
  char buf[16];
  snprintf(buf, sizeof(buf), "%02lu:%02lu:%02lu",
           static_cast<unsigned long>(elapsed / 3600UL),
           static_cast<unsigned long>((elapsed / 60UL) % 60UL),
           static_cast<unsigned long>(elapsed % 60UL));
  return String(buf);
}

void readSavedWifi() {
  wifiNetworkCount = 0;
  if (!prefs.getBool("wifiInit", false)) {
    return;
  }
  const uint8_t storedCount = min(prefs.getUChar("wifiCount", 0), kMaxWifiNetworks);
  for (uint8_t i = 0; i < storedCount; i++) {
    const String ssid = prefs.getString(wifiKey("wifiS", i).c_str(), "");
    if (!ssid.length()) {
      continue;
    }
    wifiNetworks[wifiNetworkCount].ssid = ssid;
    wifiNetworks[wifiNetworkCount].password = prefs.getString(wifiKey("wifiP", i).c_str(), "");
    wifiNetworkCount++;
  }
}

void loadLogRate() {
  logRateIndex = prefs.getUChar("btLogRate", logRateIndex);
  if (logRateIndex >= kLogRateCount) {
    logRateIndex = 7;
  }
}

void saveLogRate(uint8_t index) {
  if (index >= kLogRateCount) {
    return;
  }
  logRateIndex = index;
  prefs.putUChar("btLogRate", logRateIndex);
}

void connectWifi() {
  wifiManuallyOff = false;
  wifiOffRequested = false;
  apMode = false;
  connectedSsid = "";
  WiFi.mode(WIFI_STA);
  WiFi.setHostname(kHostname);
  WiFi.setSleep(false);

  WiFi.begin();
  uint32_t attemptStart = millis();
  while (WiFi.status() != WL_CONNECTED && millis() - attemptStart < 9000UL) {
    delay(100);
  }
  if (WiFi.status() == WL_CONNECTED) {
    connectedSsid = WiFi.SSID();
    MDNS.begin(kHostname);
    return;
  }
  WiFi.disconnect(false, false);
  delay(100);

  for (uint8_t i = 0; i < wifiNetworkCount; i++) {
    WiFi.begin(wifiNetworks[i].ssid.c_str(), wifiNetworks[i].password.c_str());
    attemptStart = millis();
    while (WiFi.status() != WL_CONNECTED && millis() - attemptStart < 9000UL) {
      delay(100);
    }
    if (WiFi.status() == WL_CONNECTED) {
      connectedSsid = WiFi.SSID();
      MDNS.begin(kHostname);
      return;
    }
    WiFi.disconnect(false, false);
    delay(100);
  }

  WiFi.mode(WIFI_AP);
  WiFi.softAP(kFallbackApSsid);
  connectedSsid = kFallbackApSsid;
  apMode = true;
  MDNS.begin(kHostname);
}

void startWebIfNeeded() {
  if (!webReady && (WiFi.status() == WL_CONNECTED || apMode)) {
    server.begin();
    webReady = true;
  }
}

void disableWifiNow() {
  logEvent("wifi_off");
  if (webReady) {
    server.stop();
    webReady = false;
  }
  WiFi.disconnect(false, false);
  WiFi.softAPdisconnect(true);
  WiFi.mode(WIFI_OFF);
  connectedSsid = "";
  apMode = false;
  wifiManuallyOff = true;
  wifiOffRequested = false;
}

void enableWifiNow() {
  connectWifi();
  startWebIfNeeded();
  logEvent("wifi_on");
}

String wifiStatusText() {
  if (WiFi.status() == WL_CONNECTED) {
    return WiFi.localIP().toString();
  }
  if (apMode) {
    return WiFi.softAPIP().toString();
  }
  return F("off");
}

String btStatusText() {
  return F("off");
}

void setBluetooth(bool enabled) {
  bluetoothEnabled = false;
}

bool physicalControlUsed() {
  static bool initialized = false;
  static uint8_t lastEncoderState = 0;
  static bool lastBack = false;
  static bool lastSelect = false;
  static bool lastConfirm = false;

  const uint8_t encoderState = (digitalRead(kEncoderAPin) ? 0x02 : 0x00) |
                               (digitalRead(kEncoderBPin) ? 0x01 : 0x00);
  const bool backPressed = digitalRead(kBackButtonPin) == LOW;
  const bool selectPressed = digitalRead(kEncoderButtonPin) == LOW;
  const bool confirmPressed = digitalRead(kConfirmButtonPin) == LOW;

  if (!initialized) {
    initialized = true;
    lastEncoderState = encoderState;
    lastBack = backPressed;
    lastSelect = selectPressed;
    lastConfirm = confirmPressed;
    return false;
  }

  const bool moved = encoderState != lastEncoderState;
  const bool pressed = (backPressed && !lastBack) ||
                       (selectPressed && !lastSelect) ||
                       (confirmPressed && !lastConfirm);
  lastEncoderState = encoderState;
  lastBack = backPressed;
  lastSelect = selectPressed;
  lastConfirm = confirmPressed;
  return moved || pressed;
}

void readBattery() {
  if (millis() - lastBatteryReadMs < kBatteryReadMs) {
    return;
  }
  lastBatteryReadMs = millis();
  if (!gaugeReady) {
    batteryVoltage = NAN;
    batteryPercent = NAN;
    return;
  }
  batteryVoltage = fuelGauge.getVoltage();
  batteryPercent = fuelGauge.getSOC();
}

void ensureLogHeader() {
  if (!sdReady || SD.exists(kLogPath)) {
    return;
  }
  File f = SD.open(kLogPath, FILE_WRITE);
  if (!f) {
    return;
  }
  f.println(F("millis,elapsed_s,event,battery_voltage,battery_percent,wifi_status,ssid,bluetooth_enabled,oled_enabled"));
  f.close();
}

void appendLogRow(const char *event) {
  if (!sdReady) {
    return;
  }
  const uint32_t now = millis();
  ensureLogHeader();
  File f = SD.open(kLogPath, FILE_APPEND);
  if (!f) {
    return;
  }
  f.print(now);
  f.print(',');
  f.print((now - startMs) / 1000UL);
  f.print(',');
  f.print(event);
  f.print(',');
  if (isnan(batteryVoltage)) f.print(""); else f.print(batteryVoltage, 3);
  f.print(',');
  if (isnan(batteryPercent)) f.print(""); else f.print(batteryPercent, 1);
  f.print(',');
  f.print((WiFi.status() == WL_CONNECTED || apMode) ? F("connected") : F("off"));
  f.print(',');
  f.print(connectedSsid);
  f.print(',');
  f.print(bluetoothEnabled ? 1 : 0);
  f.print(',');
  f.println(oledEnabled ? 1 : 0);
  f.close();
}

void writeLogSample(bool force = false) {
  if (!loggingActive || !sdReady) {
    return;
  }
  const uint32_t now = millis();
  const uint32_t logIntervalMs = kLogRatesMs[logRateIndex < kLogRateCount ? logRateIndex : 7];
  if (!force && lastLogMs != 0 && now - lastLogMs < logIntervalMs) {
    return;
  }
  lastLogMs = now;
  appendLogRow("sample");
}

void logEvent(const char *event) {
  appendLogRow(event);
}

void clearLogFile() {
  if (!sdReady) {
    return;
  }
  if (SD.exists(kLogPath)) {
    SD.remove(kLogPath);
  }
  ensureLogHeader();
  lastLogMs = 0;
  logEvent("log_cleared");
}

String buildStateJson() {
  uint32_t logSize = 0;
  if (sdReady && SD.exists(kLogPath)) {
    File logFile = SD.open(kLogPath, FILE_READ);
    if (logFile) {
      logSize = logFile.size();
      logFile.close();
    }
  }

  String json = F("{");
  json += F("\"uptime_ms\":");
  json += String(millis());
  json += F(",\"elapsed\":\"");
  json += stopwatch();
  json += F("\"");
  json += F(",\"battery_voltage\":");
  json += floatJson(batteryVoltage, 3);
  json += F(",\"battery_percent\":");
  json += floatJson(batteryPercent, 1);
  json += F(",\"gauge_ready\":");
  json += gaugeReady ? F("true") : F("false");
  json += F(",\"gauge_bus\":\"");
  json += jsonEscape(gaugeBus);
  json += F("\"");
  json += F(",\"i2c_default\":\"");
  json += jsonEscape(defaultI2cDevices);
  json += F("\"");
  json += F(",\"i2c_oled\":\"");
  json += jsonEscape(oledI2cDevices);
  json += F("\"");
  json += F(",\"logging_active\":");
  json += loggingActive ? F("true") : F("false");
  json += F(",\"sd_ready\":");
  json += sdReady ? F("true") : F("false");
  json += F(",\"log_size\":");
  json += String(logSize);
  json += F(",\"log_rate_index\":");
  json += String(logRateIndex);
  json += F(",\"log_rate_label\":\"");
  json += kLogRateLabels[logRateIndex < kLogRateCount ? logRateIndex : 7];
  json += F("\"");
  json += F(",\"log_rate_options\":[");
  for (uint8_t i = 0; i < kLogRateCount; i++) {
    if (i) {
      json += ',';
    }
    json += '"';
    json += kLogRateLabels[i];
    json += '"';
  }
  json += ']';
  json += F(",\"wifi_connected\":");
  json += (WiFi.status() == WL_CONNECTED || apMode) ? F("true") : F("false");
  json += F(",\"ap_mode\":");
  json += apMode ? F("true") : F("false");
  json += F(",\"wifi_status\":\"");
  json += jsonEscape(wifiStatusText());
  json += F("\"");
  json += F(",\"ssid\":\"");
  json += jsonEscape(connectedSsid);
  json += F("\"");
  json += F(",\"bluetooth_enabled\":");
  json += bluetoothEnabled ? F("true") : F("false");
  json += F(",\"oled_enabled\":");
  json += oledEnabled ? F("true") : F("false");
  json += F(",\"free_heap\":");
  json += String(ESP.getFreeHeap());
  json += F("}");
  return json;
}

void sendRoot() {
  String page = F("<!doctype html><html><head><meta name=viewport content='width=device-width,initial-scale=1'>"
                  "<title>SparkFun Battery Test</title><style>"
                  "body{font-family:-apple-system,BlinkMacSystemFont,Segoe UI,sans-serif;margin:18px;max-width:680px}"
                  ".status{background:#eee;padding:12px;line-height:1.55}button{font-size:16px;padding:8px;margin:4px}"
                  "a{display:inline-block;margin:8px 8px 8px 0}</style></head><body>"
                  "<h1>SparkFun Battery Test</h1><p class=status id=s>Loading...</p>"
                  "<label>Log rate <select id=lr onchange=\"setRate(this.value)\"></select></label><br>"
                  "<button onclick=\"post('/log-start')\">Start logging</button>"
                  "<button onclick=\"post('/log-stop')\">Stop logging</button>"
                  "<button onclick=\"post('/log-clear')\">Clear log</button>"
                  "<button onclick=\"post('/oled-on')\">OLED on</button>"
                  "<button onclick=\"post('/oled-off')\">OLED off</button>"
                  "<button onclick=\"wifiOff()\">WiFi off</button><br>"
                  "<a href=/log-download>Download CSV</a><a href=/log>View CSV</a>"
                  "<h2>OTA</h2><input id=f type=file><button onclick=ota()>Upload firmware</button><pre id=o></pre>"
                  "<script>"
                  "function fmt(v,d,s){return v==null?'--':Number(v).toFixed(d)+s}"
                  "function rates(j){if(!j.log_rate_options)return;let h='';j.log_rate_options.forEach((x,i)=>h+='<option value='+i+' '+(i==j.log_rate_index?'selected':'')+'>'+x+'</option>');lr.innerHTML=h}"
                  "function load(){fetch('/api/state',{cache:'no-store'}).then(r=>r.json()).then(j=>{"
                  "rates(j);s.innerHTML='Stopwatch '+j.elapsed+'<br>Battery '+fmt(j.battery_percent,1,'%')+' '+fmt(j.battery_voltage,3,' V')+'<br>SSID '+(j.ssid||'--')+'<br>WiFi '+j.wifi_status+'<br>Bluetooth '+(j.bluetooth_enabled?'on':'off')+'<br>OLED '+(j.oled_enabled?'on':'off')+'<br>Logging '+(j.logging_active?'on':'off')+' @ '+j.log_rate_label+'<br>SD '+(j.sd_ready?'ready':'off')+' · log '+j.log_size+' bytes<br>Gauge '+(j.gauge_ready?'ready on '+j.gauge_bus:'not found')+'<br>I2C default '+j.i2c_default+'<br>I2C OLED '+j.i2c_oled+'<br>Heap '+j.free_heap;});}"
                  "function post(u){fetch(u,{method:'POST'}).then(load)}"
                  "function setRate(i){fetch('/log-rate?i='+encodeURIComponent(i),{method:'POST'}).then(load)}"
                  "function wifiOff(){s.innerHTML+=' <br>WiFi turning off. Press back/select or rotate knob to turn it back on.';fetch('/wifi-off',{method:'POST'}).catch(()=>{})}"
                  "function ota(){let file=f.files[0];if(!file)return;let fd=new FormData();fd.append('firmware',file,file.name);let x=new XMLHttpRequest();x.open('POST','/api/ota');x.upload.onprogress=e=>{if(e.lengthComputable)o.textContent=Math.round(e.loaded*100/e.total)+'%'};x.onload=()=>{o.textContent=x.status+' '+x.responseText};x.send(fd)}"
                  "setInterval(load,2000);load();</script></body></html>");
  server.send(200, F("text/html"), page);
}

void sendState() {
  server.sendHeader(F("Cache-Control"), F("no-store"));
  server.send(200, F("application/json"), buildStateJson());
}

void sendLog(bool download) {
  if (!sdReady || !SD.exists(kLogPath)) {
    server.send(404, F("text/plain"), F("No battery log file"));
    return;
  }
  if (download) {
    server.sendHeader(F("Content-Disposition"), F("attachment; filename=battery_test.csv"));
  }
  File f = SD.open(kLogPath, FILE_READ);
  server.streamFile(f, F("text/csv"));
  f.close();
}

void handleOtaUpload() {
  HTTPUpload &upload = server.upload();
  if (upload.status == UPLOAD_FILE_START) {
    Update.begin(UPDATE_SIZE_UNKNOWN);
  } else if (upload.status == UPLOAD_FILE_WRITE) {
    Update.write(upload.buf, upload.currentSize);
  } else if (upload.status == UPLOAD_FILE_END) {
    Update.end(true);
  }
}

void handleOtaDone() {
  const bool ok = !Update.hasError();
  server.send(ok ? 200 : 500, F("text/plain"), ok ? F("OK rebooting") : F("OTA failed"));
  if (ok) {
    delay(500);
    ESP.restart();
  }
}

void startWeb() {
  server.on(F("/"), HTTP_GET, sendRoot);
  server.on(F("/api/state"), HTTP_GET, sendState);
  server.on(F("/log"), HTTP_GET, []() { sendLog(false); });
  server.on(F("/log-download"), HTTP_GET, []() { sendLog(true); });
  server.on(F("/log-start"), HTTP_POST, []() {
    loggingActive = true;
    startMs = millis();
    lastLogMs = 0;
    logEvent("logging_started");
    sendState();
  });
  server.on(F("/log-stop"), HTTP_POST, []() {
    logEvent("logging_stopped");
    loggingActive = false;
    sendState();
  });
  server.on(F("/log-clear"), HTTP_POST, []() {
    clearLogFile();
    sendState();
  });
  server.on(F("/log-rate"), HTTP_POST, []() {
    if (server.hasArg("i")) {
      saveLogRate(static_cast<uint8_t>(server.arg("i").toInt()));
      lastLogMs = millis();
      logEvent("log_rate_changed");
    }
    sendState();
  });
  server.on(F("/bt-on"), HTTP_POST, []() { sendState(); });
  server.on(F("/bt-off"), HTTP_POST, []() { sendState(); });
  server.on(F("/oled-on"), HTTP_POST, []() {
    oledEnabled = true;
    if (oledReady) oled.oled_command(SH110X_DISPLAYON);
    logEvent("oled_on");
    sendState();
  });
  server.on(F("/oled-off"), HTTP_POST, []() {
    oledEnabled = false;
    if (oledReady) {
      oled.clearDisplay();
      oled.display();
      oled.oled_command(SH110X_DISPLAYOFF);
    }
    logEvent("oled_off");
    sendState();
  });
  server.on(F("/wifi-off"), HTTP_POST, []() {
    wifiOffRequested = true;
    pendingWifiOffAtMs = millis() + 750UL;
    server.send(200, F("text/plain"), F("WiFi shutting off; press back/select or rotate knob to turn it back on."));
  });
  server.on(F("/api/ota"), HTTP_POST, handleOtaDone, handleOtaUpload);
  server.begin();
  webReady = true;
}

void drawOled() {
  if (!oledReady || !oledEnabled) {
    return;
  }
  oled.clearDisplay();
  oled.setTextSize(1);
  oled.setTextColor(SH110X_WHITE);
  oled.setCursor(0, 0);
  oled.print(F("Log "));
  oled.print(stopwatch());
  oled.setCursor(0, 10);
  oled.print(F("Bat "));
  if (isnan(batteryPercent)) oled.print(F("--")); else oled.print(batteryPercent, 1);
  oled.print(F("%"));
  oled.setCursor(0, 20);
  oled.print(F("Volt "));
  if (isnan(batteryVoltage)) oled.print(F("--")); else oled.print(batteryVoltage, 3);
  oled.print(F("V"));
  oled.setCursor(0, 30);
  oled.print(F("SSID "));
  oled.print(wifiManuallyOff ? F("WiFi off") : (connectedSsid.length() ? connectedSsid : F("--")));
  oled.setCursor(0, 40);
  oled.print(F("WiFi "));
  oled.print(wifiStatusText());
  oled.setCursor(0, 50);
  if (wifiManuallyOff) {
    oled.print(F("Press/rotate: WiFi"));
  } else {
    oled.print(F("BT off"));
  }
  oled.display();
}

void setup() {
  Serial.begin(115200);
  delay(250);
  startMs = millis();

  pinMode(kQwiicPowerPin, OUTPUT);
  digitalWrite(kQwiicPowerPin, HIGH);
  delay(50);
  pinMode(kEncoderAPin, INPUT);
  pinMode(kEncoderBPin, INPUT);
  pinMode(kBackButtonPin, INPUT);
  pinMode(kEncoderButtonPin, INPUT);
  pinMode(kConfirmButtonPin, INPUT_PULLUP);
  physicalControlUsed();

  Wire.begin();
  Wire.setClock(400000);
  oledWire.begin(kOledSdaPin, kOledSclPin);
  oledWire.setClock(400000);
  defaultI2cDevices = scanI2cBus(Wire);
  oledI2cDevices = scanI2cBus(oledWire);

  oledReady = oled.begin(kOledAddress, true);
  if (oledReady) {
    oled.clearDisplay();
    oled.setTextColor(SH110X_WHITE);
    oled.setTextSize(1);
    oled.setCursor(0, 0);
    oled.print(F("Battery tester"));
    oled.display();
  }

  gaugeReady = fuelGauge.begin(Wire);
  if (gaugeReady) {
    gaugeBus = "default";
    fuelGauge.quickStart();
  }

  SPI.begin(kSdSckPin, kSdMisoPin, kSdMosiPin, kSdCsPin);
  sdReady = SD.begin(kSdCsPin, SPI, 8000000);
  ensureLogHeader();

  prefs.begin(kPrefsNamespace, false);
  loadLogRate();
  readSavedWifi();
  connectWifi();
  if (WiFi.status() == WL_CONNECTED || apMode) {
    startWeb();
  }

  readBattery();
  logEvent("boot");
  writeLogSample(true);
  drawOled();
}

void loop() {
  if (wifiOffRequested && millis() >= pendingWifiOffAtMs) {
    disableWifiNow();
  }

  if (wifiManuallyOff && physicalControlUsed()) {
    enableWifiNow();
  }

  if (webReady) {
    server.handleClient();
  }
  readBattery();
  writeLogSample();
  static uint32_t lastDisplayMs = 0;
  if (millis() - lastDisplayMs >= 1000UL) {
    lastDisplayMs = millis();
    drawOled();
  }
}

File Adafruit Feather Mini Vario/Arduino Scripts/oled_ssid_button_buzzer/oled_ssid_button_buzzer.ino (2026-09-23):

#include <Arduino.h>
#include <math.h>
#include <string.h>
#include <WiFi.h>
#include <ESPmDNS.h>
#include <NetworkUdp.h>
#include <ArduinoOTA.h>
#include <Preferences.h>
#include <WebServer.h>
#include <BluetoothA2DPSource.h>
#include <SPIFFS.h>
#include <Wire.h>
#include <Adafruit_GFX.h>
#include <Adafruit_SH110X.h>
#include <Adafruit_SHT4x.h>
#include <Adafruit_BMP5xx.h>
#include <WiFiManager.h>
#include "esp_sleep.h"
#include "driver/rtc_io.h"

#ifndef BAT_VOLT_PIN
#define BAT_VOLT_PIN BATT_MONITOR
#endif

namespace {
const char *const kHostname = "vario-feather-v2";
const char *const kConfigPortalSsid = "VarioFeatherSetup";

constexpr uint8_t kBuzzerPin = 13;
constexpr uint8_t kBuzzerResolutionBits = 8;
const char *const kPrefsNamespace = "vario";
const char *const kPrefWifi = "bootWifi";
const char *const kPrefBluetooth = "bootBt";
const char *const kPrefBluetoothTarget = "btTarget";
const char *const kPrefAudio = "bootAudio";
const char *const kPrefBuzzerOutput = "buzzOut";
const char *const kPrefStartupBeeps = "startBeeps";
const char *const kPrefBuzzerVolume = "buzzVol";
const char *const kPrefDirectSettings = "directAP";
const char *const kPrefWifiSetupRequired = "wifiSetup";
const char *const kPrefResponse = "response";
const char *const kPrefBatteryLogMs = "batLogMs";
const char *const kPrefHasAltitudeZero = "hasZero";
const char *const kPrefAltitudeZeroFt = "zeroFt";
const char *const kPrefBootBlinds = "bootBlinds";
// ponytail: SmartBlinds ESP32 has a DHCP reservation; hardcode IP, skip mDNS
const char *const kBlindsHost = "192.168.50.112";
const char *const kBluetoothAudioLocalName = "VarioFeatherA2DP";
const char *const kBatteryLogPath = "/battery_log.csv";

constexpr uint8_t kButtonA = 15;
constexpr uint8_t kButtonB = 32;
constexpr uint8_t kButtonC = 14;

constexpr uint32_t kI2cClockHz = 400000;
constexpr float kMetersToFeet = 3.28084F;
constexpr float kFeetToMeters = 1.0F / kMetersToFeet;
constexpr float kSeaLevelPressureHpa = 1013.25F;
constexpr float kAltitudeSmoothingAlpha = 0.25F;
constexpr float kVarioResponseAlpha[] = {0.18F, 0.32F, 0.50F, 0.72F};
const char *const kVarioResponseLabel[] = {"Smooth", "Normal", "Quick", "Direct"};
constexpr uint8_t kVarioResponseCount = sizeof(kVarioResponseAlpha) / sizeof(kVarioResponseAlpha[0]);
constexpr float kLiftThresholdMps = 0.18F;
constexpr float kLiftOffThresholdMps = 0.08F;
constexpr float kSinkThresholdMps = -1.80F;
constexpr float kSinkOffThresholdMps = -1.40F;
constexpr uint32_t kLiftFreqBaseHz = 720;
constexpr uint32_t kLiftFreqIncrementHzPerMps = 170;
constexpr uint32_t kSinkFreqBaseHz = 360;
constexpr uint32_t kSinkFreqDecrementHzPerMps = 45;
constexpr uint32_t kMinToneHz = 130;
constexpr uint32_t kMaxToneHz = 1800;
constexpr uint32_t kToneQuantizeHz = 10;
constexpr uint32_t kBluetoothAudioSampleRateHz = 44100;
constexpr uint8_t kBluetoothTargetMaxChars = 64;
constexpr float kBluetoothAudioMaxAmplitude = 12000.0F;
constexpr float kTwoPi = 6.28318530718F;
constexpr uint8_t kDefaultBuzzerVolumePercent = 40;
constexpr uint8_t kMinBuzzerVolumePercent = 5;
constexpr uint8_t kMaxBuzzerVolumePercent = 100;
constexpr uint32_t kMenuLongPressMs = 800;
constexpr uint32_t kButtonDebounceMs = 45;
constexpr uint8_t kMenuItemCount = 14;
constexpr uint8_t kBatteryLogMenuItemCount = 4;
constexpr uint8_t kMenuVisibleRows = 8;
constexpr uint8_t kToneTestCount = 4;
constexpr uint32_t kToneTestDurationMs = 3000;
constexpr uint32_t kSensorReadMs = 100;
constexpr uint32_t kDisplayUpdateMs = 100;
constexpr uint32_t kBlindsPingMs = 3000;
constexpr uint32_t kBlindsHttpTimeoutMs = 1500;
constexpr uint32_t kBmpWarmupMs = 5000;
constexpr uint32_t kBmpRetryMs = 2000;
constexpr uint32_t kWifiConnectTimeoutMs = 20000;
constexpr uint32_t kWifiPortalTimeoutMs = 300000;
constexpr uint32_t kWifiRetryMs = 15000;
constexpr float kMinBatteryLogFrequencyHz = 0.5F;
constexpr float kMaxBatteryLogFrequencyHz = 10.0F;
constexpr uint32_t kDefaultBatteryLogIntervalMs = 2000;
constexpr size_t kBatteryLogRamFallbackMaxBytes = 49152;
constexpr uint16_t kSettingsPort = 80;
constexpr uint16_t kApSettingsPort = 8080;
const char *const kToneTestLabel[] = {"Ascent", "Fast up", "Descent", "Fast down"};
const char *const kNoRouterLinkHtml =
  "<p><a href='http://192.168.4.1:8080/'>No router mode / settings</a></p>";
const char kBatteryLogHeader[] =
  "elapsed_s,battery_percent,battery_voltage,ssid,wifi_status,bluetooth_status,heap_free,event";

Adafruit_SH1107 display = Adafruit_SH1107(64, 128, &Wire);
Adafruit_SHT4x sht4 = Adafruit_SHT4x();
Adafruit_BMP5xx bmp;
Preferences prefs;
WiFiManager wifiManager;
WiFiManagerParameter noRouterLink(kNoRouterLinkHtml);
WebServer settingsServer(kSettingsPort);
WebServer apSettingsServer(kApSettingsPort);
BluetoothA2DPSource a2dpSource;

bool bmpReady = false;
bool shtReady = false;
bool lastA = HIGH;
bool lastB = HIGH;
bool lastC = HIGH;
volatile bool buttonBPressed = false;
volatile bool buttonCPressed = false;
bool altitudeFilterInitialized = false;
bool wifiEnabled = true;
bool bootWifiEnabled = true;
bool bluetoothEnabled = false;
bool bootBluetoothEnabled = false;
bool bluetoothAudioStarted = false;
bool bluetoothAudioStartFailed = false;
bool otaStarted = false;
volatile bool audioEnabled = true;
bool buzzerOutputEnabled = true;
bool startupBeepsEnabled = true;
bool menuActive = false;
bool blindsMode = false;
bool bootBlindsMode = false;
bool blindsOnline = false;
const char *blindsMotion = "Idle";
uint32_t lastBlindsPingMs = 0;
bool toneOn = false;
bool liftAudioActive = false;
bool sinkAudioActive = false;
bool liftBeepOn = false;
bool varioRateInitialized = false;
bool toneTestActive = false;
bool readyBeepActive = false;
bool bmpWarmupComplete = false;
bool altitudeZeroSaved = false;
bool directSettingsMode = false;
bool wifiSetupRequired = false;
bool wifiConnectInProgress = false;
bool wifiPortalRunning = false;
bool settingsRoutesConfigured = false;
bool settingsServerStarted = false;
bool apSettingsServerStarted = false;
bool pendingWifiReset = false;
bool pendingRestart = false;
bool displayNeedsRefresh = true;
bool oledEnabled = true;
bool batteryLoggingActive = false;
bool batteryLogFlashReady = false;
bool batteryLogFlashChecked = false;
bool batteryLogFlashFull = false;
bool batteryLogRamTruncated = false;
bool batteryLogSavedWifiEnabled = true;
bool batteryLogSavedBluetoothEnabled = false;
bool batteryLogSavedOledEnabled = true;
bool batteryLogSavedDirectSettingsMode = false;
bool batteryLogSavedWifiSetupRequired = false;
uint8_t menuIndex = 0;
uint8_t varioResponseIndex = 1;
uint8_t toneTestPatternIndex = 0;
uint8_t toneTestPlayingIndex = 0;
uint8_t readyBeepCount = 0;
uint8_t buzzerVolumePercent = kDefaultBuzzerVolumePercent;
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

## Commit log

2026-06-20 Rev 1
    [1.2in 7 Segment Display.f3d, 1.2in 7 Segment Display.step, 1.2in 7 Segment Display.stl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]
2026-06-21 FlatCAM ready
    [Buzzer PCB.kicad_pcb, Buzzer PCB.kicad_sch, PCB.step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]
2026-06-21 CAM ready
    [Buzzer PCB.kicad_pcb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]
2026-06-21 deleted adafruit cad parts
    [1.2in 7 Segment Display.f3d, 1.2in 7 Segment Display.step, 1.2in 7 Segment Display.stl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]
2026-06-21 V2 PCB done
    [Buzzer PCB.kicad_pcb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]
2026-06-22 Fix S8050 pinout and buzzer test interval
    [Buzzer PCB.kicad_pcb, Buzzer PCB.kicad_sch]
2026-06-22 Fixed transistor pins
    [Buzzer PCB.kicad_pcb]
2026-06-22 Add Buzzer PCB V2 KiCad project
    [Buzzer PCB.kicad_pcb, Buzzer PCB.kicad_sch]
2026-06-23 V2 with sparkfun
    [Buzzer PCB.kicad_pcb, Buzzer PCB.kicad_sch, PCB.step]
2026-06-23 Persist altitude zero across resets
    [oled_ssid_button_buzzer.ino]
2026-06-23 Add web settings UI and WiFi reset menu
    [oled_ssid_button_buzzer.ino]
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2026-06-23 Fix WiFi reset and menu responsiveness
    [oled_ssid_button_buzzer.ino]
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2026-06-23 Fix setup AP crash during WiFi reset
    [oled_ssid_button_buzzer.ino]
2026-06-23 Updated Component References for Buzzer PCB V2
    [Comidox 5V Booster Board Drawing Sheet1.dxf, Comidox 5V Booster Board.step, HiLetGo TP4057 LiPo_LiIon Charger Drawing HiLetGo TP4057 LiPo LiIon Charger.dxf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]
2026-06-24 Before component update: OLED/SD/TP4057 footprint swap, remove SW2-SW5, add booster + BZ2/BZ3 buzzer drivers
    KiCad-MCP-Checkpoint: true
    Project-Path: KiCAD Files/Buzzer PCB V2
2026-06-24 Restore KiCad component references and footprints
    [5776 SHT41 Sensor - from SHT45 same SHT4x board family.step, 6407 BMP581 Sensor - from BMP585 same BMP5xx board family.step, Adafruit 128x64 OLED FeatherWing.b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]
2026-06-24 Reposition buzzer PCB footprints and add SHT41 header
    [Buzzer PCB.empty-deleted.kicad_pcb, Buzzer PCB.kicad_pcb, Buzzer PCB.kicad_sch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]
2026-06-25 updated pcb
    [Buzzer PCB.kicad_pcb, Buzzer PCB.kicad_sch]
2026-06-25 final routing
    [Buzzer PCB.kicad_pcb]
2026-06-25 Latest board
    [Buzzer PCB.kicad_pcb]
2026-06-25 getting close
    [Buzzer PCB-ALL-holes-only.dxf, Buzzer PCB-Edge_Cuts.dxf, Buzzer PCB-F_Cu.dxf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]
2026-06-26 ready to mill
    [Buzzer PCB-Edge_Cuts.dxf, Buzzer PCB-NPTH-drl_map.dxf, Buzzer PCB-NPTH_2_5mm_Vector.dxf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]
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2026-06-26 DEEP CORNER HOLES
    [Buzzer PCB-NPTH_2_5mm_Vector.dxf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]
2026-06-26 last attempt
    [Buzzer PCB.kicad_pcb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]
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2026-06-27 Save V3 KiCad board before manual via DRC modeling
    [Buzzer PCB V3 (rerouted traces).kicad_pcb, Buzzer PCB V3 (rerouted traces).kicad_sch, SparkFun_6DoF_LSM6DSV16X_Qwiic_1x1in_board.step]
2026-06-27 FInal Sparkfun Version
    [Buzzer PCB V3 (rerouted traces)-B_Cu.gbr, Buzzer PCB V3 (rerouted traces)-Edge_Cuts.gbr, Buzzer PCB V3 (rerouted traces)-F_Cu.gbr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]
2026-06-28 fixed 2mm isolation
2026-06-28 FIX MISSING TRACES
2026-06-28 fixed with 0.4mm isolation
    [Buzzer PCB V3 (rerouted traces).kicad_pcb]
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2026-06-28 Restructure repo into per-board folders; add Bluetooth toggle
    - Move project into board-named top-level folders:
    "Adafruit Feather Mini Vario" and "Sparkfun ESP32 WROOM Vario"
    - Add Sparkfun_Vario Bluetooth classic enable/disable (radio.cpp) with
    VARIO_DISABLE_BT compile guard and battery-logging BT controls
    - Flatten SparkFun component-reference clones to plain files
    - gitignore build output, .DS_Store, and .history (VS Code local history)
    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
    [261 JST PH 2-pin cable female connector 100mm simplified.step, 3898 400mAh Battery.f3d, 3898 400mAh Battery.step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]
2026-06-28 Add SD self-flash firmware switch + WiFi/BT build split
    WiFi + Bluetooth can't coexist in IRAM on the ESP32-WROOM, so ship two
    firmwares and switch between them from the SD card.
    - firmware.cpp/.h: flashFirmwareFromSd() streams the alternate image from
    the SD root through Update, draws a live % progress bar on the OLED, then
    reboots. New "Switch FW" menu item.
    - radio_config.h: single build selector. VARIO_RADIO_WIFI (default) ->
    VARIO_DISABLE_BT; VARIO_RADIO_BT -> VARIO_DISABLE_WIFI.
    - Guard WiFi/web objects and bodies behind VARIO_DISABLE_WIFI (globals.cpp,
    wifi_net.cpp, web.cpp) with no-op stubs so the BT image links without WiFi.
    Both images verified building and fitting (no IR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
    [controls.cpp, display.cpp, globals.h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]
2026-06-28 Add SD file manager to web app (browse/upload/download/rename/delete)
    New "Files" card in the SD tab walks the SD card: click folders to descend,
    download/rename/delete any file, multi-file upload into the current folder.
    Backed by /api/files (list), /file (download), /api/file/{delete,rename};
    upload reuses the existing /api/upload path handler.
    Claude-Session: https://claude.ai/code/session_01EBUqpDiDXFTeQW7shG5GQL
2026-06-29 Add A2DP earbud beep latency test sketch
    Standalone bench sketch: streams a 1 kHz beep to TOZO A1 earbuds over
    Bluetooth Classic A2DP while firing the same beep on the piezo (pin 13) at
    the same instant — the audible piezo-vs-earbud gap is the A2DP latency.
    Decides whether BT vario audio is worth pursuing before folding into radio.cpp.
    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
2026-06-29 Add Buzzer Lab to web app — tune frequency/duty/buzzers for loudness
    New "Buzzer Lab" card (System tab) drives the buzzers directly via /api/tone,
    bypassing the vario's 130-1800 Hz clamp (up to 6 kHz) so piezo resonance can
    be found by ear: frequency + duty sliders (live), B1/B2/B3 selection, and a
    200->6k auto-sweep. Vario audio pauses while the lab is active; a keepalive
    watchdog releases the buzzers if the browser goes away.
    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
    [audio.cpp, globals.h, web.cpp]
2026-06-30 Add SD file manager to web app (browse/upload/download/rename/delete)
    - Battery fix: remove delay(2) from readBatteryIfDue so reads work reliably
    with WiFi active (battery now shows with WiFi on)
    - GPS altitude source: useGpsAltitude flag (OLED menu + web settings toggle);
    when enabled, displayAltitudeFt tracks GPS altitude instead of baro
    - WiFi setup menu item: OLED + web WiFi tab "WiFi setup" starts the config
    portal without forgetting saved networks (vs Forget WiFi which clears them)
    - BT firmware stub: add startWifiPortal() no-op to VARIO_DISABLE_WIFI stubs
    so BT build links cleanly
    - SD firmware files: fw_wifi.bin (1.43 MB) and fw_bt.bin (1.41 MB) uploaded
    to SD card root for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
    [controls.cpp, display.cpp, globals.h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]
2026-06-30 Make encoder window/menu switching instant
    Force updateDisplay(true) immediately on every encoder step instead of
    waiting for the 100ms throttle gate. Window changes now show as fast as
    the OLED I2C transfer allows (~23ms), not in batches up to 100ms late.
    Same for entering menu mode and scrolling menu items.
    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
2026-06-30 Fix encoder responsiveness, GPS altitude blip, stray indicator digit
    - Encoder: lower accumulator threshold 4→2; if each detent only gives 2
    transitions (common on budget encoders) this makes it 1 click per step
    - GPS altitude: guard both baro write-backs in sensors.cpp behind
    !useGpsAltitude so baro can't overwrite the GPS value every 100ms
    - Indicator: explicit fillRect before drawing n/N so stale digits from a
    previous narrower string can't bleed through
    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
    [controls.cpp, display.cpp, sensors.cpp]
2026-07-01 Add tunable vario tone model: 1-3 buzzers, thresholds, pitch, two-tone
    - Buzzers setting (1-3 simultaneous) replaces the unexposed volumeLevel;
    adjustable from web Settings and a new OLED menu item
    - Vario Tone web card: climb threshold, climb pitch, pitch rise, beep
    tempo, sink threshold, sink pitch, all persisted and applied live
    - Two-tone options: climb beeps step up a major third mid-beep, sink
    tone warbles; tone ceiling raised 1800->4500 Hz for piezo resonance
    - Remove Bluetooth classic slider from the WiFi web app (BT is never
    available in the WiFi build)
    - Carried along from the previous session: battery read via A1 ADC
    divider (drops MAX17048-over-GPS-pins juggling), WiFi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
    [audio.cpp, controls.cpp, display.cpp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]
2026-07-01 Add button lock (hold Select+Back) to prevent backpack button presses
    Hold Select+Back for a configurable duration to toggle a lock that
    swallows all button/encoder input except the same unlock gesture.
    Flashes Locked/Unlocked on the OLED (only when the screen is on) and
    beeps at the current volume; both the hold time and the beep are
    adjustable/toggleable from the web UI only.
    [controls.cpp, display.cpp, globals.h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]
2026-07-01 Add WiFi on/off toggle to OLED menu
    - New menu item "WiFi" (kMenuWifiEnabled) to enable/disable WiFi master switch
    - Persists state via kPrefWifiEnabled preference (default: on)
    - setWifiEnabled(bool, bool) controls WiFi radio state fully
    - initWifi() and serviceWifi() respect wifiEnabled global
    - Selecting WiFi setup/forget while disabled auto-enables WiFi
    - Mirrors existing Bluetooth on/off pattern
2026-07-01 Replace GPS-on-OLED toggle with a real GPS enable/disable switch
    The old "GPS display" menu item never actually gated anything — GPS
    parsing always ran. Repurpose it as a true enable/disable: when off,
    the GPS UART is never opened (gpsSerial.end()/skip begin()), freeing
    the pins that are time-shared with the MAX17048 battery gauge so
    battery reads aren't fighting GPS for the bus. Exposed in both the
    OLED menu and the web UI.
    [Sparkfun_Vario.ino, controls.cpp, display.cpp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]
2026-07-01 Fix lock-splash setCursor() build error on esp32 core 3.3.10
    max(x, 0) mixed int16_t and int, which the toolchain's std::max
    overload resolution rejects instead of falling back to the Arduino
    min/max macros. Caught while compiling for OTA upload.
    [display.cpp]
2026-07-03 Add IMU + flight submenus, custom OLED fonts, lock splash to menu
    [Top (X2D).3mf]
2026-07-03 Serve web app over the AP, add Lock/OLED menu items, hide dead radio toggles
    - AP portal now runs our own SoftAP + wildcard-DNS captive portal and serves
    the full vario web app (same routes as station mode), so a phone joined to
    SparkFun-Vario-Setup gets the same UI it gets over a network. Drops
    WiFiManager entirely; WiFi credentials are added from the web app's WiFi
    section. onNotFound bounces captive-portal probes to the app root.
    - Add "Lock screen" as the top menu item (locks controls, same as holding
    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
2026-07-03 Give each buzzer its own LEDC timer so chords use all 3
    Auto ledcAttach() assigned channels 0,1,2 to pins 13/26/27, which map to
    timers 0,0,1 -- so pins 13 and 26 shared a timer and were locked to a single
    frequency. Chord jingles collapsed to effectively one voice. Attach to
    channels 0,2,4 (distinct timers 0,1,2) for true 3-voice output, and rework
    the chime/arp jingles to actually drive all three buzzers.
    [audio.cpp]
2026-07-03 Add configurable Bluetooth earbud name (default TOZO-A1)
    Persist the A2DP target name in NVS so the Bluetooth firmware can pair to
    any earbuds, not just the hardcoded TOZO-A1. Editable from the WiFi build's
    web Settings -> Bluetooth audio card; the value survives a reflash so it
    carries over to the BT firmware. Blank resets to the default.
    On-device rotary-encoder text entry is not built yet; the web field covers
    setting it once from the WiFi build.
    [globals.h, web.cpp]
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2026-07-10 Back up all SD logs from the vario (2026-07-10)
    vario_log.csv + old, battery logs, per-session /logs/*.csv, windows.json,
    pulled over the SD file-manager web API at 172.20.10.3.
    Claude-Session: https://claude.ai/code/session_017nywbYmMamiwa9WFSuFQWC
    [2026-07-02_17-56-36.csv, 2026-07-02_19-12-23.csv, 2026-07-02_19-31-22.csv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]
2026-07-10 Clock: keep time synced from GPS and NTP, most-recent source wins
    The old serviceClock() seeded the RTC once and bailed forever after
    (if (timeKnown()) return), so a fresh GPS fix could never correct or
    re-seed the clock after NTP set it (or vice versa), and the reported
    source label went stale once NTP took over from GPS.
    Now both sources keep writing the RTC:
    - GPS re-seeds every kGpsClockResyncMs (60s) from a fix newer than
    kGpsFixMaxAgeMs, correcting for the fix centiseconds and parse age so a
    re-seed never makes an NTP-synced clock visibly stutter.
    - NTP updates via a real sntp_set_time_sync_notification_cb callback
    instead of the old timeKnown() heuristic.
    - clockSource() report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
    [globals.h]
2026-07-10 OLED clock: 12h/24h toggle with AM/PM and a saved timezone offset
    The OLED date/time window fields and the 'Time zone' menu item were
    UTC-only — no way to show local time or correct for a wrong timezone.
    New Clock settings category (menu: Clock format, Time zone):
    - Clock format toggles 24h <-> 12h with AM/PM, persisted (kPrefClock12h).
    - Time zone is a 15-minute-step encoder value (UTC-12..+14), persisted
    (kPrefTzMinutes), live-previewed as offset + current local time while
    editing.
    - localTimeString()/localDateString() in timekeeping.cpp apply the offset
    and format; isoTimestamp() (used for logging) stays UTC-only so log
    files are unaffected.
    - The OLED 'date'/'time' window fiel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
    [controls.cpp, display.cpp, globals.h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]
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2026-08-03 v1.1.0: BLE vario telemetry for iOS apps, 5 Hz logging, per-FW OLED layouts, SD usage
    - BT firmware now advertises as "SparkFun Vario" over BLE (FFE0/FFE1, NimBLE)
    streaming $LK8EX1 at 5 Hz so Gaggle/Flyskyhy can use it like a BlueFlyVario;
    replaces Bluetooth Classic SPP which iOS cannot see
    - Log rates down to 0.2s/0.5s (browser + OLED menu, same arrays as before)
    - Flight logs named /logs/flight_YYYY_MM_DD_HH-MM-SS.csv from local start time
    - Idle log size cap (Settings -> Logging, MB, 0=unlimited) with _old rotation
    - SD card used/total in web SD tab + new sd_usage OLED panel field
    - Per-firmware OLED layouts (windows_wifi.json / windows_bt.json) with a
    "Layout for" selector in the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
    [Sparkfun_Vario.ino, globals.h, logging.cpp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]
2026-08-03 igc_convert: add --gaggle mode so Gaggle uses baro altitude
    Gaggle ignores the IGC pressure column and derives climb rate from GPS
    altitude. Verified by diffing a FlySkyHy log against Gaggle's own re-export
    of it: Gaggle's altitude matched the GPS column on 4000/5359 fixes exactly
    (rest +/-1 m rounding) and the baro column on 45, and every B record it
    wrote had PPPPP=00000. On that flight baro and GPS drifted 68 m apart by
    landing, which is why max climb disagreed with FlySkyHy.
    --gaggle copies PPPPP over GGGGG so Gaggle's math lands on the BlueFlyVario
    trace. Both columns are 5 chars, so I-record extension offsets stay valid
    and the rest of the file passes through untouched. G-records are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
2026-08-03 igc_convert: repair BlueFlyVario dropout spikes in --gaggle
    When the vario's BLE link drops, FlySkyHy writes GPS altitude into the
    pressure column for a fix or two, then snaps back -- e.g. 1061 -> 1031 ->
    1061 in consecutive seconds while GPS moves 0 m. Each one adds ~2x its
    depth of phantom climb and sink to whatever the importing app computes.
    despike() compares every fix to the median of its 6 nearest neighbours, so
    a run of one or two bad samples is outvoted. The window is kept symmetric:
    a lopsided one biases the median on a steady climb and "repairs" real lift
    near the file edges. On the 2026-08-03 Marbachegg flight this repairs 6
    spikes and drops raw height gain from 9400 ft to 9055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
2026-08-03 v1.2.0: WiFi + BLE telemetry in one firmware; fix BT toggle reboot
    - WiFi build now includes NimBLE LK8EX1 telemetry (the old WiFi/BT split was
    forced by Bluedroid Classic IRAM; NimBLE fits). BT-only build kept as a
    low-power variant.
    - Stub rgbLedWrite so the unused RGB-LED/RMT driver stays out of the link
    (IRAM was 1440 bytes over without it)
    - Fix reboot when toggling Bluetooth off: init NimBLE once, "off" = stop
    advertising + disconnect instead of deinit
    - Add the missing BLE telemetry toggle to web Settings (fillSettings
    referenced a nonexistent element)
    Claude-Session: https://claude.ai/code/session_01A6ETw4vTX3DyX3GbiQo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
    [power.cpp, radio.cpp, web.cpp]
2026-08-03 v1.3.0: dual BLE services (FFE0 + Nordic UART), GPS-over-BLE toggle, BLE name setting
    - Stream LK8EX1 on both HM-10 (FFE0/FFE1) and Nordic UART TX simultaneously;
    add Battery (180F) + Device Info (180A) services apps probe after connect
    (targets Gaggle stuck-on-connecting and Flyskyhy not offering the device)
    - $GPGGA/$GPRMC at 1 Hz behind a "Send GPS to apps" toggle (web + OLED
    GPS menu); silent when GPS disabled, no fix, or fix older than 5 s
    - Configurable advertised BLE name (web Settings, applied at boot)
    Claude-Session: https://claude.ai/code/session_01A6ETw4vTX3DyX3GbiQoyp2
    [controls.cpp, display.cpp, globals.h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]
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2026-10-20 Fix driving calibration loss on sharp motion and sensor settling

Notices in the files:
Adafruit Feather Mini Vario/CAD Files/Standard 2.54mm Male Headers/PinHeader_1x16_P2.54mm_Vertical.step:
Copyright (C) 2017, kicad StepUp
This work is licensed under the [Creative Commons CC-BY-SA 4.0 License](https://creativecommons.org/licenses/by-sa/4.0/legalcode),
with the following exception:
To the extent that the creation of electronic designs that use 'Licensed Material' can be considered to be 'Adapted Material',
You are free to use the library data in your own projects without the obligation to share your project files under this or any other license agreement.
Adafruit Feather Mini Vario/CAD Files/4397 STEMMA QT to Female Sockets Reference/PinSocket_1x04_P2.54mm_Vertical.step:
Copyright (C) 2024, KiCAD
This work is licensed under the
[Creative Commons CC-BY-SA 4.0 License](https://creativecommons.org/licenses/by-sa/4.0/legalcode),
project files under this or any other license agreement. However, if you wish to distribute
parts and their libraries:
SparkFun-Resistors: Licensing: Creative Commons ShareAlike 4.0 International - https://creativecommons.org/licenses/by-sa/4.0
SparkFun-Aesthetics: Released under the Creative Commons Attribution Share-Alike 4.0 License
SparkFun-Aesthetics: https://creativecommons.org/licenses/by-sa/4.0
